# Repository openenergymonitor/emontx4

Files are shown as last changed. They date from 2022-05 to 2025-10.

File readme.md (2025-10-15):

# EmonTx v4

The emonTx v4 is an energy monitoring transmitter unit that can monitor up to 6 AC circuits using CT sensors and the OpenEnergyMonitor 1-3 phase voltage sensing unit. At it's core is a Microchip AVR128DB48 microcontroller - responsible for sampling the current and voltage waveforms and calculating the power and energy values. The emonTx v4 also supports temperature sensing and pulse counting.

Data from the emonTx can be transmitted over the 433 MHz RFM69cw radio link or read directly using a USB cable from an emonBase or emonPi. A number of adapter boards are also available to provide internal connectivity options via ESP32, ESP8266, Pi Pico W and Pi Zero W.

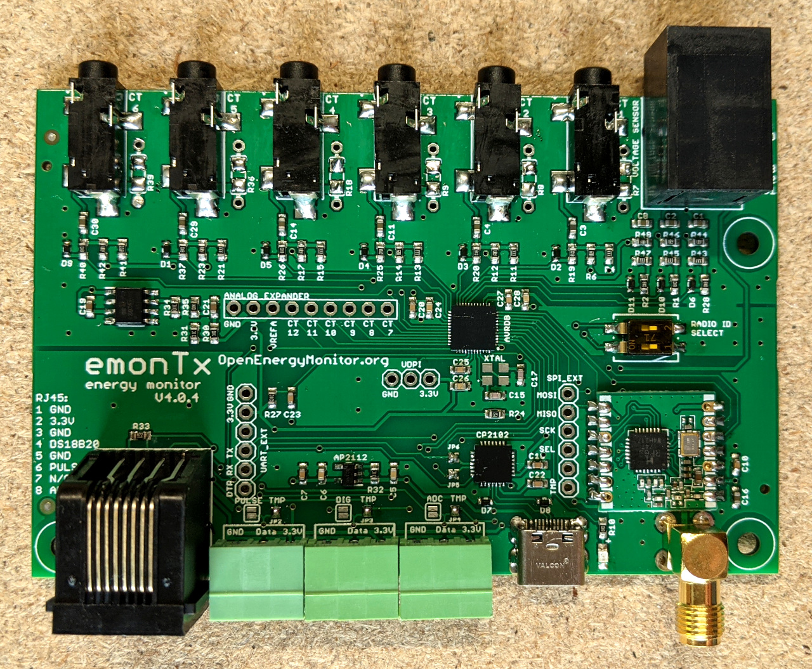
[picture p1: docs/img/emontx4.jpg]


**Key features**

* Micro-controller: AVR128DB48 (VQFN 128 kb flash, 48-pin package)
* 3 voltage channels (via RJ11 connector top-right, interfaces with separate voltage sensing board, single phase firmware only at present).
* 6 CT current channels on the base board.
* Option to extend the number of CT channels to 12 via an additional extender board (firmware not yet developed for this).
* Precision voltage reference for the ADC to improve accuracy.
* RJ45 socket for pulse counter and DS18B20 temperature sensing.
* 3x 3-WAY pluggable terminal blocks for selectable temperature sensing, pulse or additional analog input.
* RFM69CW 433MHz radio transceiver
* DIP Switch to select node id
* USB-C power and integrated CP2102 usb to serial chip
* Serial and SPI pin headers breakout internally, designed for use with adapter boards.
 
The dimensions are slightly smaller than that of the emonTx v3 at 65mm long rather than 80mm.

The board is designed to support both single and full 3-phase electricity monitoring when used in conjunction with the relevant external voltage sensing board. And the CT extender pin headers should provide a cost effective way of gaining additional CT channels.

The on-board USB to serial chip will make it easier and neater to have a hard-wired installation linking the emonTx to a RaspberryPi based base station.

## Documentation

[View on read the docs](https://docs.openenergymonitor.org/emontx4/index.html)

Or here on github:

- [Install Guide](docs/emontx4_emonbase_install.md)
- [Configuration](docs/configuration.md)
- [Firmware](docs/firmware.md)
- [Expansion boards](docs/expansion_boards.md)

## Expansion Boards

- [6CT Expansion Board](https://github.com/openenergymonitor/emontx4/tree/main/expansion_boards/CTExt)
- [ESP8266 Expansion Board](https://github.com/openenergymonitor/emontx4/tree/main/expansion_boards/ESP8266)
- [ESP32 Expansion Board](https://github.com/openenergymonitor/emontx4/tree/main/expansion_boards/ESP32)
- [Pi Pico Expansion Board](https://github.com/openenergymonitor/emontx4/tree/main/expansion_boards/PiPico)
- [Pi Zero ExtExpansionension Board](https://github.com/openenergymonitor/emontx4/tree/main/expansion_boards/PiZero)

## Community & Support

- [OpenEnergyMonitor Forums](https://community.openenergymonitor.org)

OpenEnergyMonitor Shop Support: support@openenergymonitor.zendesk.com

## License

- The hardware designs (schematics and CAD files) are licensed under a Creative Commons Attribution-ShareAlike 3.0 Unported License.
- The firmware is released under the GNU GPL V3 license The documentation is subject to GNU Free Documentation License
- The hardware designs follow the terms of the OSHW (Open-source hardware) Statement of Principles 1.0.

## Disclaimer

```
OUR PRODUCTS AND ASSEMBLY KITS MAY BE USED BY EXPERIENCED, SKILLED USERS, AT THEIR OWN RISK. TO THE FULLEST EXTENT PERMISSIBLE BY THE APPLICABLE LAW, WE HEREBY DISCLAIM ANY AND ALL RESPONSIBILITY, RISK, LIABILITY AND DAMAGES ARISING OUT OF DEATH OR PERSONAL INJURY RESULTING FROM ASSEMBLY OR OPERATION OF OUR PRODUCTS.

Your safety is your own responsibility, including proper use of equipment and safety gear, and determining whether you have adequate skill and experience. OpenEnergyMonitor and Megni registered partnership disclaims all responsibility for any resulting damage, injury, or expense. It is your responsibility to make sure that your activities comply with applicable laws, including copyright. Always check the webpage associated with each unit before you get started. There may be important updates or corrections. All use of the instructions, kits, projects and suggestions given both by megni.co.uk, openenergymonitor.org and shop.openenergymonitor.org are to be used at your own risk. The technology (hardware , firmware and software) are constantly changing, documentation (including build guide and instructions) may not be complete or correct.

If you feel uncomfortable with assembling or using any part of the system, return it to us for a full refund.
```

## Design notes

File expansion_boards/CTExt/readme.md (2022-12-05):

# EmonTx v4 CT Expansion Board

The expansion board adds another 6 CT inputs, bringing the total to 12. This utilises the larger amount of analog inputs on the 48pin AVR-DB chip.

While the first version of the hardware for this is available, the firmware for this functionality is not yet available.

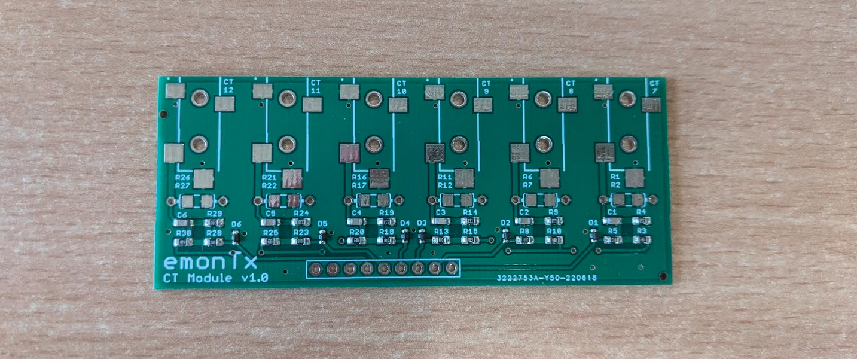
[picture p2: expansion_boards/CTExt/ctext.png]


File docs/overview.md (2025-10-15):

---
github_url: "https://github.com/openenergymonitor/emontx4/blob/main/docs/overview.md"
---

# Overview

The emonTx4 is part of the AVR-DB based hardware family which now includes the emonPi2 and the emonTx5.

While no longer available in the shop the emonTx4 is still actively supported as part of the latest generation of hardware.

These units provide a redesigned focus on higher accuracy, more CT channels and precision voltage sensing. When combined with the emonVs voltage sensor, the emonBase base-station and a selection of CT sensors, the emonTx4 provides an end-to-end electricity monitoring solution perfect for monitoring home consumption, solar generation, EV charging, heat pumps, battery storage or any AC electrical circuit for that matter.

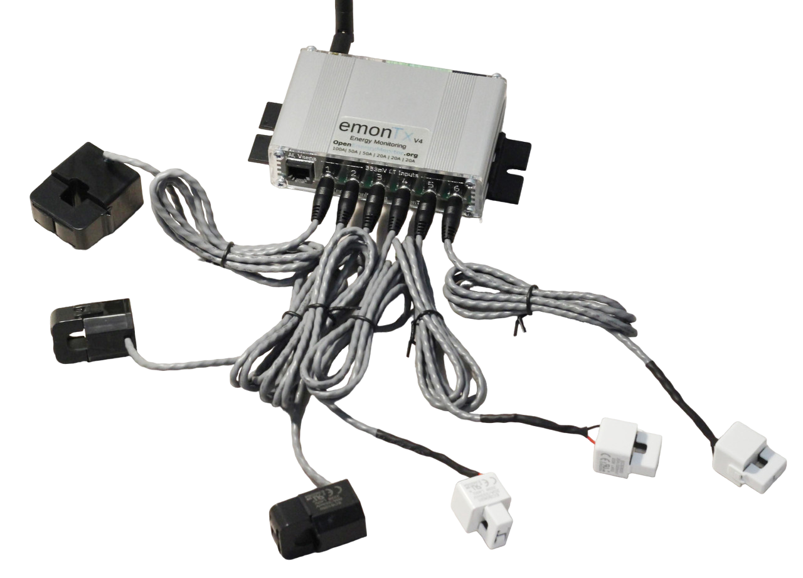
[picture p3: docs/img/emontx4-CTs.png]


## Key features

- 6x clip-on CT current sensor inputs (suitable for a range of 333mV voltage output CT sensors).
- emonVs precision voltage sensor input.
- Full Real/Active power measurement & continuous sampling.
- Cumulative energy persisted on reboot.
- The initial firmware release supports single phase monitoring only.
- Support for 3 phase voltage sensing.
- 3 pluggable terminal block inputs for DS18B20 temperature sensing, pulse counting or an analogue voltage input.
- RJ45 socket for pulse counting and DS18B20 temperature sensors.
- On-board USB to UART converter for easier programming and serial output.
- 433 MHz radio transceiver
- Extension header pins for use with ESP8266, ESP32, Pi Pico & Pi Zero development board extension modules
- Wall-mount aluminium enclosure

## Technical spec

- Microcontroller: [Microchip AVR128DB48](https://www.microchip.com/en-us/products/microcontrollers-and-microprocessors/8-bit-mcus/avr-mcus/avr-db)
- Arduino core support [DxCore by SpenceKonde](https://github.com/SpenceKonde/DxCore)
- ADC Resolution: 12-bit
- Precision voltage reference: [MCP1502](https://www.microchip.com/en-us/product/MCP1502)
- On board USB to UART converter: CP2102
- RFM69CW 433 MHz radio

## Accuracy

We have taken several key steps to improve accuracy with the emonTx4. The largest source of improvement comes from: a higher accuracy voltage sensor, higher accuracy CT current sensors and a wider range of CT sensors with current ratings that can better suit the load being monitored (making sure the analog-to-digital range of the microcontroller is being put to full use).

The key sensor and component tolerances are now:

- CT Sensors: ±0.5%
- EmonVs voltage sensor: ±0.5%
- Analog voltage reference ±0.2%
- Combined: ±1.2%

We have also upgraded the microcontroller from the ATmega328 to and AVR128DB48. The main improvement is a higher resolution ADC at 12-bits (4x the resolution of the ATmega328) alongside the capability to monitor more channels.

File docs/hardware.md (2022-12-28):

---
github_url: "https://github.com/openenergymonitor/emontx4/blob/main/docs/hardware.md"
---

# Hardware

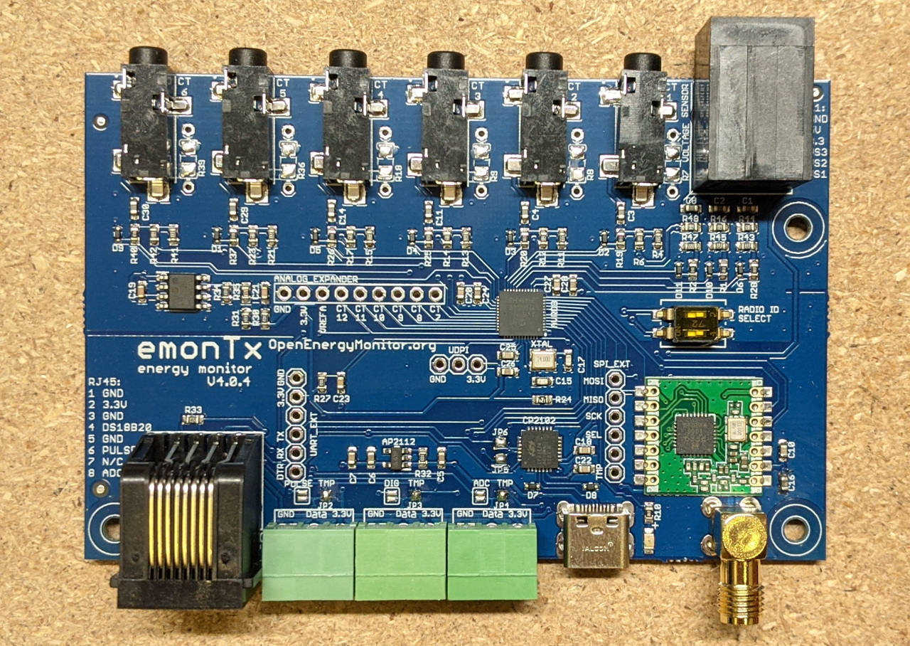
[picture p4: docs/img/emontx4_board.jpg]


## Schematic

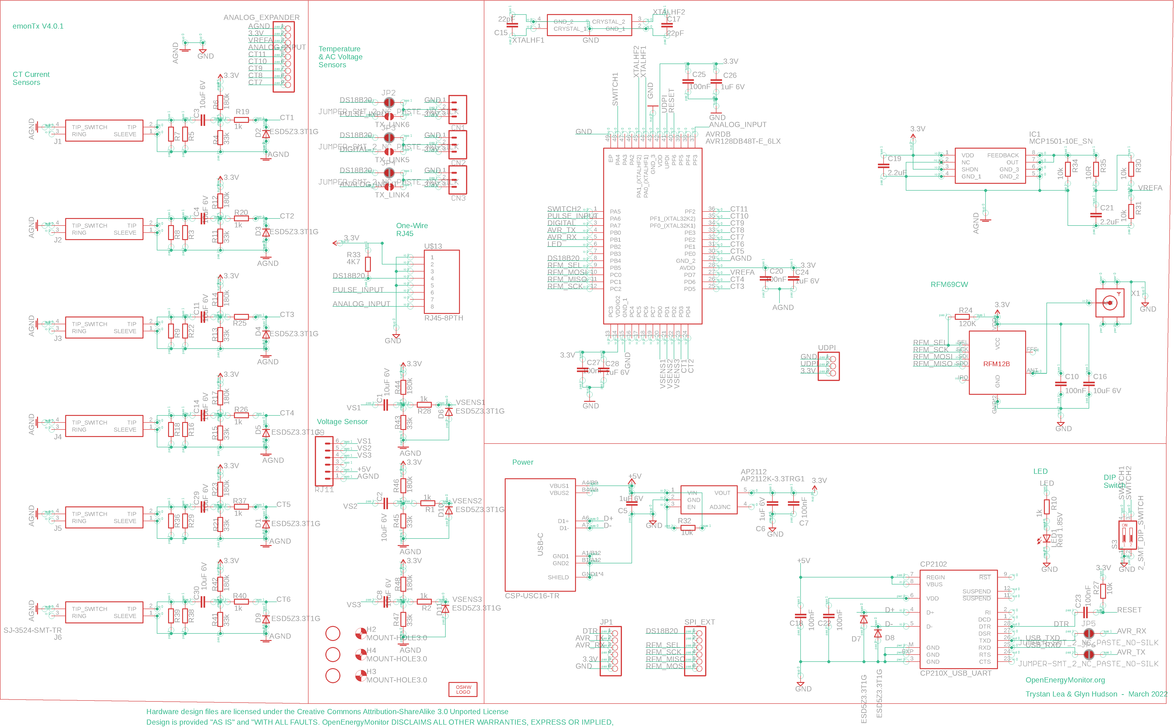
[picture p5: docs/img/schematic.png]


## Board layout

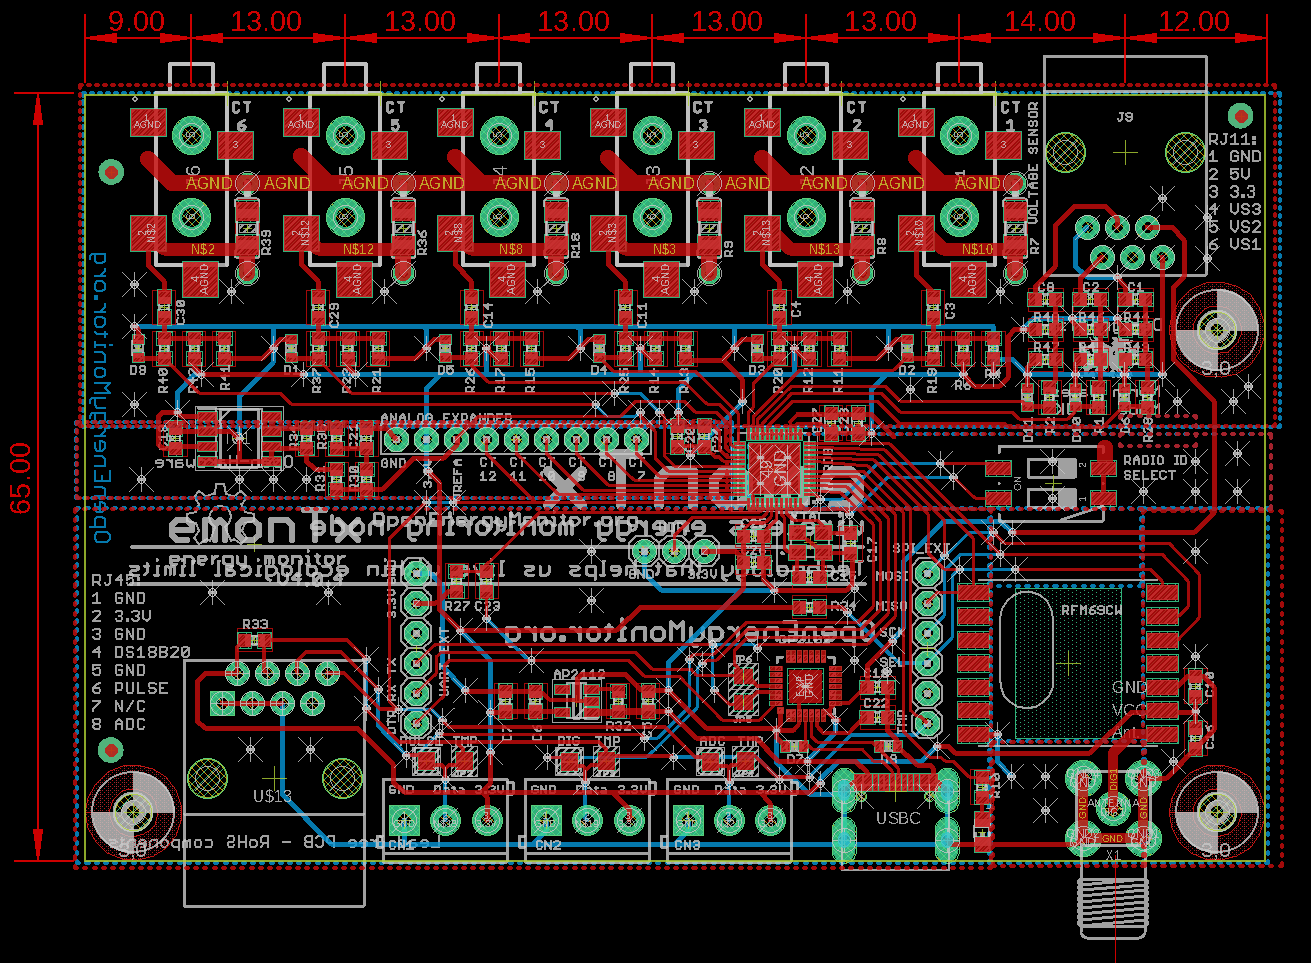
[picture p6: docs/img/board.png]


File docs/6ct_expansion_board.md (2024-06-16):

# 6 CT Expansion board

The 6 CT Expansion board adds a further 6x CT inputs to the EmonTx4, giving a total of 12 CT inputs. This can be used with example firmware that is provided as part of the new EmonLibDB library, supporting both single phase and 3 phase monitoring. 

**Note: Firmware configuration, compilation and upload required using the Arduino IDE, see firmware guide below for details.**

## Installation guide

**Upgrading:** If ordered separately to the EmonTx4 the expansion board comes with a 12 CT fascia to replace the standard 6 CT version. A 9-way header is also included that needs to be soldered in place on the EmonTx4.

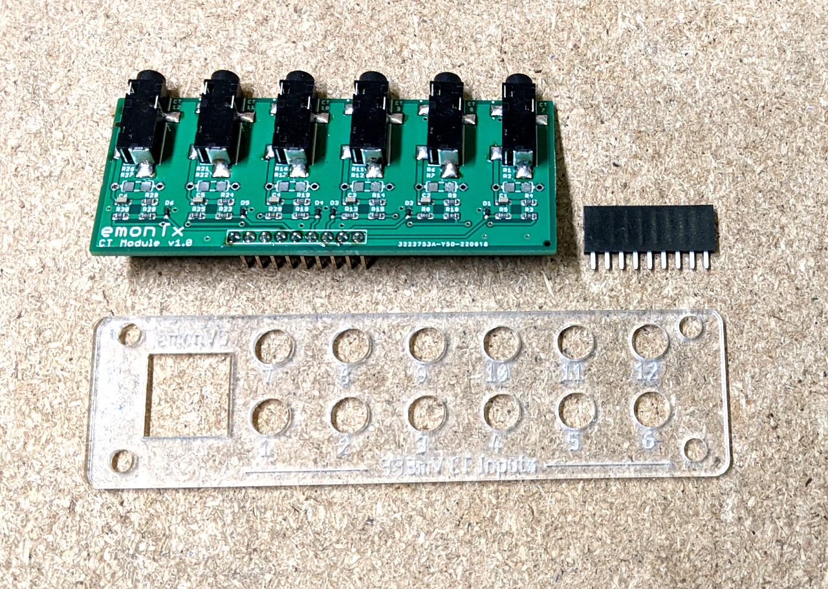
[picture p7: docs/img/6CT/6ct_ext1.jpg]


Place the 9 way header on the top side of the board as circled below:

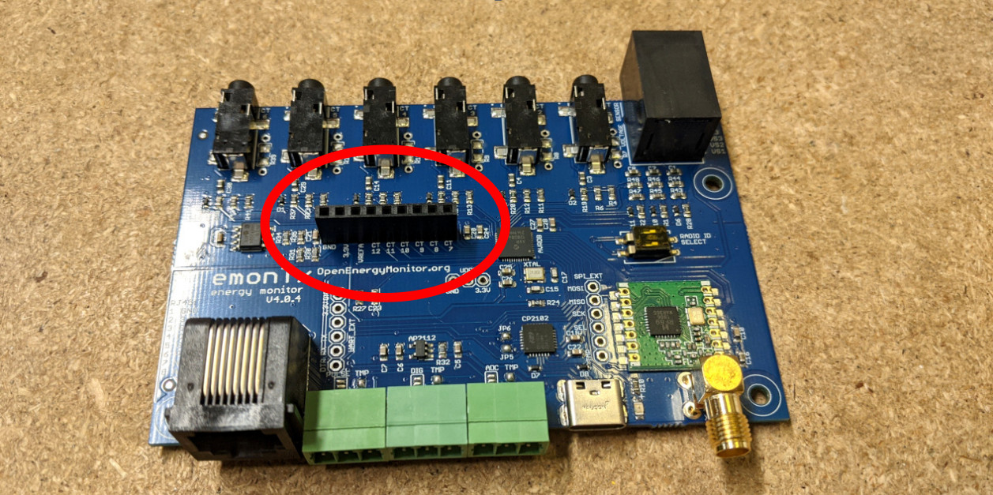
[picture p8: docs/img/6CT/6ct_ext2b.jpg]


Solder the pins on the bottom side, taking care not to bridge across the pins:

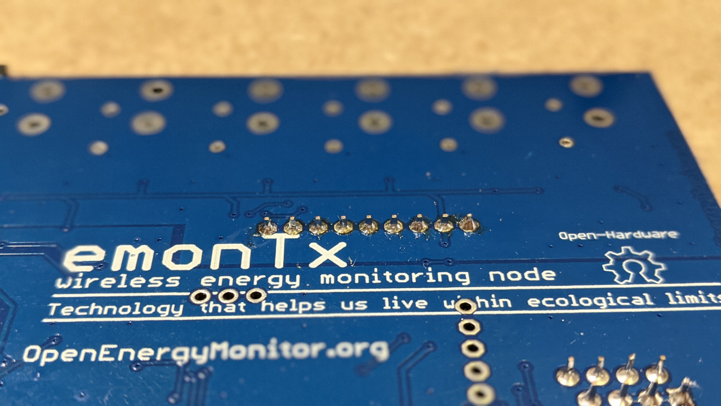
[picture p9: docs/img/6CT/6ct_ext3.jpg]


**Note:** The mechanical attachment of the expansion board is not very secure. It relies on the 9 way PCB header connection. Care needs to be taken when plugging in expansion board CTs as the board can flex on the header. This is something we plan to improve on future versions.

We recommend connecting the CT sensors through the face plate, outside of the aluminium enclosure first and then attaching the face plate to the enclosure second. This ensures that the CT's are all fully inserted and that the pressure on the header is minimised. See pictures below.

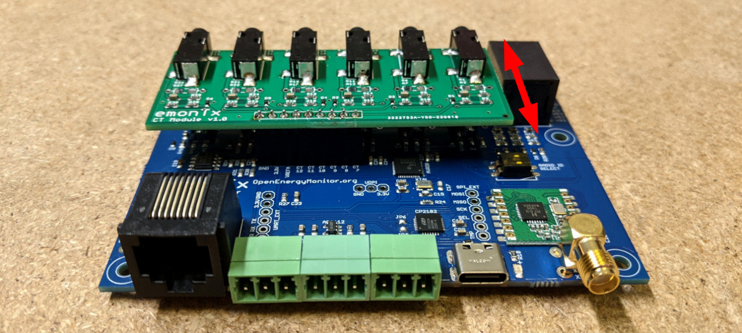
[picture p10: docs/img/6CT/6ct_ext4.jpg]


Slide the emonTx4 board, expansion board, face plate and CT jacks into the case:

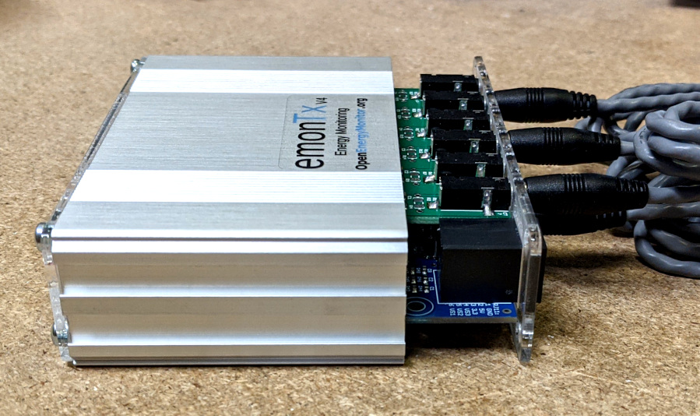
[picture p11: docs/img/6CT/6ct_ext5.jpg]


Screw in the torx screws (torx size T10):

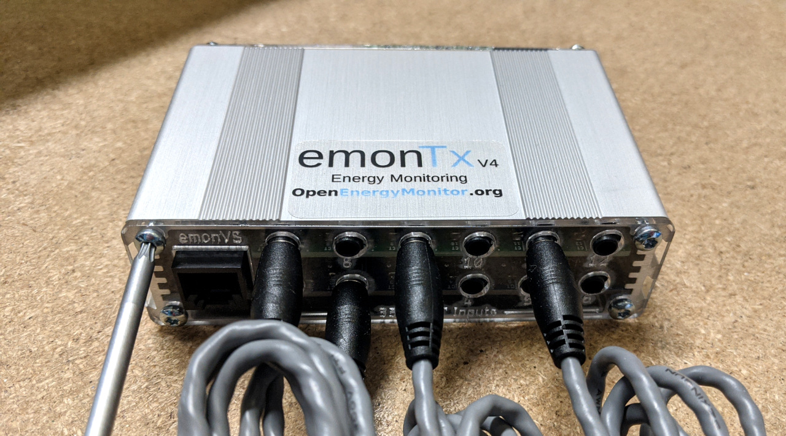
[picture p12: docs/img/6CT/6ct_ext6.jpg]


## Firmware guide

If you are using the newer "LowPowerLabs" radio firmware, you will be able to flash precompiled firmware. See the [firmware guide](firmware.md) to determine which firmware you require for your needs.

If you are using the older "JeeLib Classic" radio firmware (pre 2022 monitoring installations), using the 6 CT channel expansion board may require compiling and uploading custom configuration of the emonTx4 firmware. Start by setting up the Arduino IDE environment following the [firmware guide](firmware.md).

Open the base firmware `emon_DB_12CT` from the [avrdb_firmware](https://github.com/openenergymonitor/avrdb_firmware) firmware repository.

1\. Make sure to **select emonTx4 as the hardware variant**:

```
// 1. Set hardware variant
// Options: EMONTX4, EMONTX5, EMONPI2
#define EMONTX4
```

2\. **Set `NUM_V_CHANNELS`** to 1 for single phase or 3 for three phase: 

```
// 3. Set number of voltage channels (1 for single phase, 3 for three phase)
#define NUM_V_CHANNELS 3
```

3\. **Adjust voltage and CT sensor calibration as required** (lines 187-207):

**Voltage inputs:**
101.3 here refers to 101.3% of the default calibration value. Please see [emonLibDB user guide](https://github.com/openenergymonitor/emonLibDB/blob/main/guide.md) for more info as well. 0.16 refers to the voltage sensor phase calibration.

```
  EmonLibDB_set_vInput(1, 101.3, 0.16);  
#if NUM_V_CHANNELS == 3
  EmonLibDB_set_vInput(2, 101.3, 0.16); 
  EmonLibDB_set_vInput(3, 101.3, 0.16); 
#endif
```

**Current channel inputs:** 100.0 here refers to 100A CT sensors. If you have 20A or 50A CT sensors change the relevant channels to 20.0 or 50.0 to match the CT sensor. 3.2 refers to the CT sensor phase calibration.

```
  EmonLibDB_set_cInput(1, 20.0, 3.2);
  EmonLibDB_set_cInput(2, 20.0, 3.2);
  EmonLibDB_set_cInput(3, 20.0, 3.2);
  EmonLibDB_set_cInput(4, 20.0, 3.2);
  EmonLibDB_set_cInput(5, 20.0, 3.2);
  EmonLibDB_set_cInput(6, 20.0, 3.2);
  
#ifdef EXPANSION_BOARD
  EmonLibDB_set_cInput(7, 20.0, 3.2);
  EmonLibDB_set_cInput(8, 20.0, 3.2);
  EmonLibDB_set_cInput(9, 20.0, 3.2);
  EmonLibDB_set_cInput(10, 20.0, 3.2);
  EmonLibDB_set_cInput(11, 20.0, 3.2);
  EmonLibDB_set_cInput(12, 20.0, 3.2);
#endif  
```

4\. **Link voltage and current sensors to define the power & energy measurements.** The firmware includes default configuration for the selected NUM_V_CHANNELS (1 phase or 3 phase). In the single phase example all CT sensors are connected to voltage phase 1. In the three phase code, the allocation is CT1 = phase1, CT2 = phase2, CT3 = phase3 etc.

```
#if NUM_V_CHANNELS == 1
  EmonLibDB_set_pInput(1, 1);                  // CT1, V1 (etc)
  EmonLibDB_set_pInput(2, 1);
  EmonLibDB_set_pInput(3, 1);
  EmonLibDB_set_pInput(4, 1);  
  EmonLibDB_set_pInput(5, 1);
  EmonLibDB_set_pInput(6, 1);
#ifdef EXPANSION_BOARD
  EmonLibDB_set_pInput(7, 1);                  // CT7, V1 (etc)
  EmonLibDB_set_pInput(8, 1);
  EmonLibDB_set_pInput(9, 1);
  EmonLibDB_set_pInput(10, 1);  
  EmonLibDB_set_pInput(11, 1);
  EmonLibDB_set_pInput(12, 1);
#endif
#endif

#if NUM_V_CHANNELS == 3
  EmonLibDB_set_pInput(1, 1);                  // CT1, V1 (etc)
  EmonLibDB_set_pInput(2, 2);
  EmonLibDB_set_pInput(3, 3);
  EmonLibDB_set_pInput(4, 1);  
  EmonLibDB_set_pInput(5, 2);
  EmonLibDB_set_pInput(6, 3);
#ifdef EXPANSION_BOARD
  EmonLibDB_set_pInput(7, 1);                  // CT7, V1 (etc)  
  EmonLibDB_set_pInput(8, 2);
  EmonLibDB_set_pInput(9, 3);
  EmonLibDB_set_pInput(10, 1);  
  EmonLibDB_set_pInput(11, 2);
  EmonLibDB_set_pInput(12, 3);
#endif
#endif
```

*Note: It is also possible to measure Line-Line loads, see Line-Line loads: example lines 253-267.*

5\. **Compile and upload your configured firmware to the EmonTx4.** Note compilation and upload settings as covered in the  [EmonTx4 How to compile and upload firmware guide](firmware.md). 

6\. **To receive the radio packet data on an emonPi or emonBase** first make sure that you are running LowPowerLabs radio firmware on the emonPi or emonBase receiver. 

If you have existing nodes running the original JeeLib classic radio format, the firmware on these will also need to be updated if everything is to continue talking to each other. 

If you have an emonPi make sure that it's running the latest emonPi LowPowerLabs firmware, this can be uploaded from the local emoncms Admin > Update page.

If you bought an emonBase alongside an emonTx4 and selected the standard radio format option the radio configuration should already be correct and ready to receive data from the EmonTx4 running the above firmware example.

7\. **Configure emonHub to decode the `emon_DB_12CT` radio packet**.<br>
If you have the latest version of emonhub with autoconf enabled, it will automatically populate the node decoder configuration below. If you have an older system with autoconf disabled, follow the following manual steps:

On your local emonPi/emonBase navigate to `Setup > Emonhub > Edit Config.`

If you already have a node configuration in the `[nodes]` section for the EmonTx4 under the same nodeid as above, remove this first. 

Add the following node decoder in its place (Adjust the nodeid to match the configured nodeid as set in the firmware above):

    [[28]]
        nodename = emonTx4_28
        [[[rx]]]
            names = MSG, Vrms1, Vrms2, Vrms3, P1, P2, P3, P4, P5, P6, E1, E2, E3, E4, E5, E6, pulse, Analog
            datacodes = L, h, h, h, h, h, h, h, h, h, l, l, l, l, l, l, L, H
            scales = 1.0, 0.01, 0.01, 0.01, 1.0, 1.0, 1.0, 1.0, 1.0, 1.0, 1.0, 1.0, 1.0, 1.0, 1.0, 1.0, 1.0, 1.0
            units = n, V, V, V, W, W, W, W, W, W, Wh, Wh, Wh, Wh, Wh, Wh, p, n

    [[29]]
        nodename = emonTx4_29
        [[[rx]]]
            names = MSG, Vrms2, Vrms3, P7, P8, P9, P10, P11, P12, E7, E8, E9, E10, E11, E12, digPulse, anaPulse
            datacodes = L, h, h, h, h, h, h, h, h, l, l, l, l, l, l, L, L
            scales = 1.0, 0.01, 0.01, 1.0, 1.0, 1.0, 1.0, 1.0, 1.0, 1.0, 1.0, 1.0, 1.0, 1.0, 1.0, 1.0, 1.0
            units = n, V, V, W, W, W, W, W, W, Wh, Wh, Wh, Wh, Wh, Wh, p, p

8\. **That should be it!** you should now see the EmonTx4 data appear both in the EmonHub log window and as inputs on the Emoncms inputs page :tada:

For more information, please see forum thread: [EmonTx4 3-phase support with emonLibDB](https://community.openenergymonitor.org/t/emontx4-3-phase-support-with-emonlibdb/23541)

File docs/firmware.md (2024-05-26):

---
github_url: "https://github.com/openenergymonitor/emontx4/blob/main/docs/firmware.md"
---

# Firmware

**Updated: 14th May 2024**<br>

There are currently 8 pre-compiled firmware options for the emonTx4 available via both the Emoncms firmware upload tool and the command line `emonupload.py` firmware tool. 

**To choose the right firmware, there are 4 main questions:**

1. Is the application 1-phase, 3-phase (4-wire) or current only?<br>

2. Are you using a 6 channel expander for a total of 12 CT channels?<br>

3. Do you require temperature sensing?<br>

4. Do you require compatibility firmware that uses the JeeLib Classic radio format for use with an existing pre 2022 monitoring installation?

Select the right firmware from the list that matches the requirements of your application:

| ID | Firmware | Voltage | CTs | Temperature | Pulse|
| --- | --- | --- | --- | --- | --- |
| | **Radio: LowPowerLabs** | | | | |
| 1 | emonTx4_DB_6CT_1phase_LPL | 1-ph | 6 | 0 | 1* |
| 2 | emonTx4_DB_6CT_3phase_LPL | 3-ph | 6 | 0 | 1* |
| 3 | emonTx4_DB_12CT_1phase_LPL | 1-ph | 12 | 0 | 3* |
| 4 | emonTx4_DB_12CT_3phase_LPL | 3-ph | 12 | 0 | 3* |
| 5 | emonTx4_CM_6CT_temperature_LPL | 1-ph or current only | 6 | 3 (6\*\*) | 1 |
| | **Radio: Compatibility mode (JeeLib Classic)** | | | | |
| 6 | emonTx4_DB_6CT_1phase_JeeLib_Classic | 1-ph  | 6 | 0 | 1* |
| 7 | emonTx4_DB_6CT_3phase_JeeLib_Classic | 3-ph  | 6 | 0 | 1* |
| 8 | emonTx4_CM_6CT_temperature_JeeLib_Classic | 1-ph or current only | 6 | 3 (6\*\*) | 1 |

*The pulse sensor * denote standard firmware radio packet support for the number of pulse sensors given. Firmware modification can extend the number of pulse sensors to 3 on all emonLibDB based firmwares.*

- All firmwares transmit data via 433Mhz RFM69CW radio by default and are designed to be used with a receiving emonPi/emonBase base-station. The radio can be turned off via serial configuration if reading data via USB cable.

- All firmwares include serial configuration of radio, voltage and current channel calibration values.

- **_DB:** EmonLib**DB** electricity monitoring library.<br>

- **_CM:**  EmonLib**CM** electricity monitoring library.

- **3-phase firmwares phase allocation:** follows the following pattern: 

  - CT1: phase 1
  - CT2: phase 2
  - CT3: phase 3
  - CT4: phase 1
  - CT5: phase 2
  - CT6: phase 3
  - continued for 12 CT expansion board...

- **3-phase (4-wire):** 3-phase support is for 3-phase, 4-wire systems only. That is systems with an L1, L2, L3 and a NEUTRAL wire. For 3-phase, 3-wire systems please contact us.

- **North American split-phase systems:** The 3-phase voltage sensor can also be used to provide voltage measurement for North American split-phase systems. A custom phase allocation will likely be required for this configuration which can be achieved by minor firmware modification.

- **Current only:** Supported by firmware 5 & 8 only, can be used with installations without an emonVs voltage sensor. These firmwares uses the older emonLibCM electricity monitoring library that has a fallback option to an assumed RMS voltage value if no AC voltage signal is detected.

- **Temperature sensing:** 
  - Supported by firmware 5 & 8 only. Temperature sensing support is achieved with a very slight degradation in electricity monitoring performance, see forum thread about this [here](https://community.openenergymonitor.org/t/emontx4-ds18b20-temperature-sensing-firmware-release-1-5-7/23496/3).

  - \*\*The default maximum number of temperature sensors that can be connected is 3 but this can be increased up to 6 by changing the `#define MAX_TEMPS 3` value at the top of the firmware when compiling and uploading from source.

- **Pulse sensing** is configured on the standard emonTx4 digital input port available on the RJ45 socket as well as the terminal block input (if the solder pad is configured). 

- **Analog input:** Reading from the analog input can be enabled for all firmware variants via a `#define` compile option when compiling from source.

**Base firmwares**<br>
These are now built from a set of base firmware's common to all AVR-DB hardware variants (emonTx4, emonTx5 and emonPi2) available in the [avrdb_firmware repository](https://github.com/openenergymonitor/avrdb_firmware/)

- Firmwares 1, 2, 6 & 7 compiled from the `emon_DB_6CT` base firmware.
- Firmwares 3 & 4 are compiled from the `emon_DB_12CT` base firmware.
- Firmwares 5 & 8 are compiled from the `emon_CM_6CT_temperature` base firmware.

---

## Updating firmware using an emonPi/emonBase (recommended)

The easiest way of updating the emonTx4 firmware is to connect it to an emonBase with a USB cable and then use the firmware upload tool available at `Setup > Admin > Update > Firmware`.

```{warning} 

**System update may be required:** If you don not see the latest firmware version as listed above in the firmware list a full system update is required first.
```

**Note: Upload via USB-C will only work if connected in the right orientation. Try turning the USB-C connector around if upload fails.** Some USB-C connectors have a smooth side on one side and jagged connection of the metal fold on the other. On the cables we have here, the smooth side should be facing up towards the top/front face of the emonTx4:

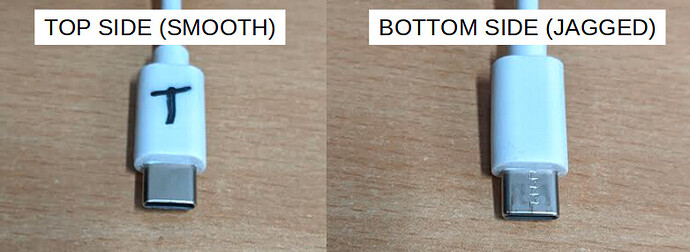
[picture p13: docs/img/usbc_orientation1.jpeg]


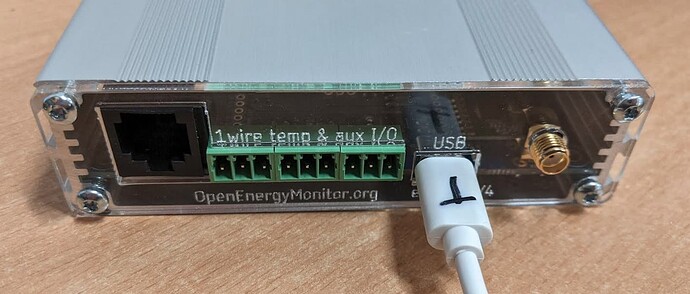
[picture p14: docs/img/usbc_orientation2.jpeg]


Refresh the update page after connecting the USB cable. You should now see port `ttyUSB0` appear in the 'Select port` list.



Double check the serial port, this is likely to be 'ttyUSB0' when plugged in via USB device connected. Select 'emonTx4' from hardware.

The standard radio format is 'LowPowerLabs', if you wish to use the emonTx4 with an existing system running JeeLib classic radio format you can select the JeeLib classic radio format here.

## Upload pre-compiled using EmonScripts emonupload2 tool 

On the emonPi/emonBase ensure EmonScripts is updated to latest version then run emonupload2 tool 

    /opt/openenergymonitor/EmonScripts/emonupload2.py

Select hardware then firmware version

```
Select hardware:
  1. emonTx5
  2. emonPi2
  3. emonTx4
  4. emonPi
  5. emonTx3
  6. rfm69pi
  7. rfm12pi
  8. emonTH2
  9. JeeLink
Enter number:3

Select firmware:
1. emonTx4_DB_6CT_1phase_LPL               2.1.0      (Standard LowPowerLabs)
2. emonTx4_DB_6CT_3phase_LPL               2.1.0      (Standard LowPowerLabs)
3. emonTx4_DB_12CT_1phase_LPL              1.2.0      (Standard LowPowerLabs)
4. emonTx4_DB_12CT_3phase_LPL              1.2.0      (Standard LowPowerLabs)
5. emonTx4_CM_6CT_temperature_LPL          1.6.0      (Standard LowPowerLabs)
6. emonTx4_DB_6CT_1phase_JeeLib_Classic    2.1.0      (Compatibility)
7. emonTx4_DB_6CT_3phase_JeeLib_Classic    2.1.0      (Compatibility)
8. emonTx4_CM_6CT_temperature_JeeLib_Classic1.6.0      (Compatibility)

```

emonupload2 tool can also be run on any other linux computer by cloning the EmonScripts repo then running the emonupload2.py python script. Python3 required 

    git clone https://github.com/openenergymonitor/EmonScripts

## Upload pre-compiled manually using avrdude

Alternatively to upload the same pre-compiled firmware via command line on emonPi / emonBase: 

    avrdude -C/opt/openenergymonitor/EmonScripts/update/avrdude.conf -v -pavr128db48 -carduino -D -P/dev/ttyUSB0 -b115200 -Uflash:w:emonTx4_DB_6CT_1phase_LPL_v2_1_0.ino.hex:i 

Or using different computer, ensure `avrdude.conf` has `avr128db48` entry i.e DxCore see below instructions 

    avrdude -Cavrdude.conf -v -pavr128db48 -carduino -D -P/dev/ttyUSB0 -b115200 -Uflash:w:emonTx4_DB_6CT_1phase_LPL_v2_1_0.ino.hex:i 
    
You will need avrdude installed (tested on version 6.3-2017) and the custom DxCore avrdude.conf. This can be downloaded here: [DxCore avrdude.conf](https://raw.githubusercontent.com/openenergymonitor/EmonScripts/master/update/avrdude.conf).

## How to compile and upload firmware

### Compile and Upload using PlatformIO

Clone the `avrdb_firmware` repo 

    git clone https://github.com/openenergymonitor/avrdb_firmware
    cd avrdb_firmware/emon_DB_6CT
    
Open `emon_DB_6CT.ino` in an editor and change `#define EMONTX5` to `#define EMONTX4`. 

Change any other compile options as required e.g:

- to use JeeLib classic radio format for compatibility with an existing installation change `#define RFM69_LOW_POWER_LABS` to `#define RFM69_JEELIB_CLASSIC`.
- to enable analog read uncomment `#define ENABLE_ANALOG`.
- change pulse pin to standard emonTx4 digital input if required `#define PULSE_PIN 1`.
    
Install PlatformIO core then to compile and upload:

    pio run -t upload

On first run PlatformIO will download automatically all the required libraries. You can also use the PlatformIO GUI. 

### Compile and Upload using Arduino IDE 

If you don’t already have the Arduino IDE it can be downloaded from here:<br>
[https://www.arduino.cc/en/software](https://www.arduino.cc/en/software)

Once you have the IDE installed, you then need to install [Spence Konde’s DxCore](https://github.com/SpenceKonde/DxCore). This can be done by first pasting the following board manager URL in Arduino IDE > File > Preferences:

    http://drazzy.com/package_drazzy.com_index.json

Then navigating to: *Tools > Boards > Boards Manager*, Select “DxCore by Spence Konde” and click Install. 

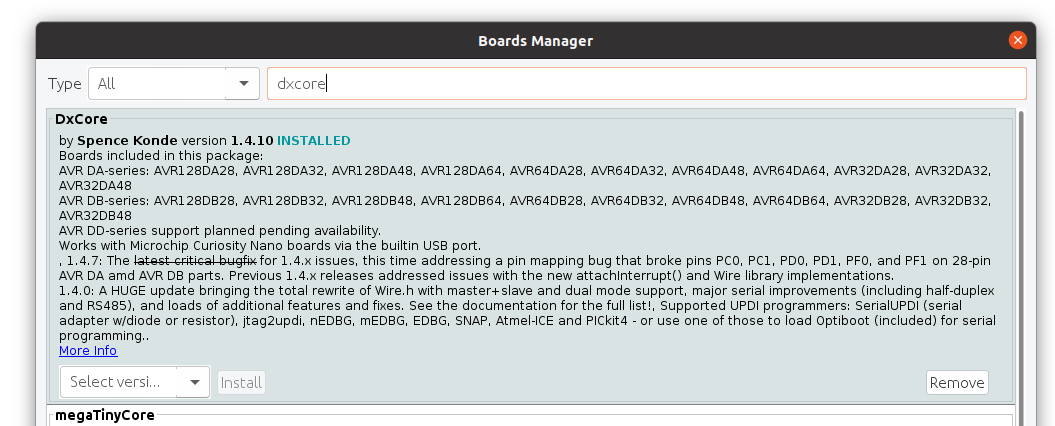
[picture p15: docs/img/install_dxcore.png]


For more information on DxCore installation see: [https://github.com/SpenceKonde/DxCore/blob/master/Installation.md](https://github.com/SpenceKonde/DxCore/blob/master/Installation.md).

**Libraries**

Locate or create your Arduino Sketchbook directory (location found in Arduino preferences). If it doesnt already exist, create a directory called libraries in the Sketchbook directory and install the following libraries:

1\. Download EmonLibCM library (avrdb branch)<br>
[https://github.com/openenergymonitor/EmonLibCM/tree/avrdb](https://github.com/openenergymonitor/EmonLibCM/tree/avrdb)

2\. Download EmonLibDB library (main branch)<br>
[https://github.com/openenergymonitor/emonLibDB](https://github.com/openenergymonitor/emonLibDB)

2\. Download emonEProm library (avrdb branch)<br>
[https://github.com/openenergymonitor/emonEProm/tree/avrdb](https://github.com/openenergymonitor/emonEProm/tree/avrdb)

3\. Download RFM69_LPL library (main branch)<br>
[https://github.com/openenergymonitor/RFM69_LPL](https://github.com/openenergymonitor/RFM69_LPL)

4\. Download RFM69_JeeLib library (avrdb branch)<br>
[https://github.com/openenergymonitor/RFM69_JeeLib/tree/avrdb](https://github.com/openenergymonitor/RFM69_JeeLib/tree/avrdb)

5\. Download DxCore SpenceKonde OneWire library:<br>
[https://github.com/SpenceKonde/OneWire](https://github.com/SpenceKonde/OneWire)

**Open and edit the AVR-DB firmware**

Clone the `avrdb_firmware` repo 

    git clone https://github.com/openenergymonitor/avrdb_firmware

Open the base firmware that you wish to use in the Arduino IDE e.g `emon_DB_6CT.ino`.

Change `#define EMONTX5` to `#define EMONTX4`. 

Change any other compile options as required e.g:

- to use JeeLib classic radio format for compatibility with an existing installation change `#define RFM69_LOW_POWER_LABS` to `#define RFM69_JEELIB_CLASSIC`.
- to enable analog read uncomment `#define ENABLE_ANALOG`.

**Compilation settings:**

With DxCore and the libraries installed the firmware should then compile. 

Under Tools, select the following configuration options:

- Select Board "AVR DB-series (Optiboot)"
- Select Chip: AVR128DB48
- Clock Speed: 24 MHz Crystal
- Bootloader serial port: UART3: TXPB0, RXPB1

Select Board "AVR DB-series (Optiboot)"

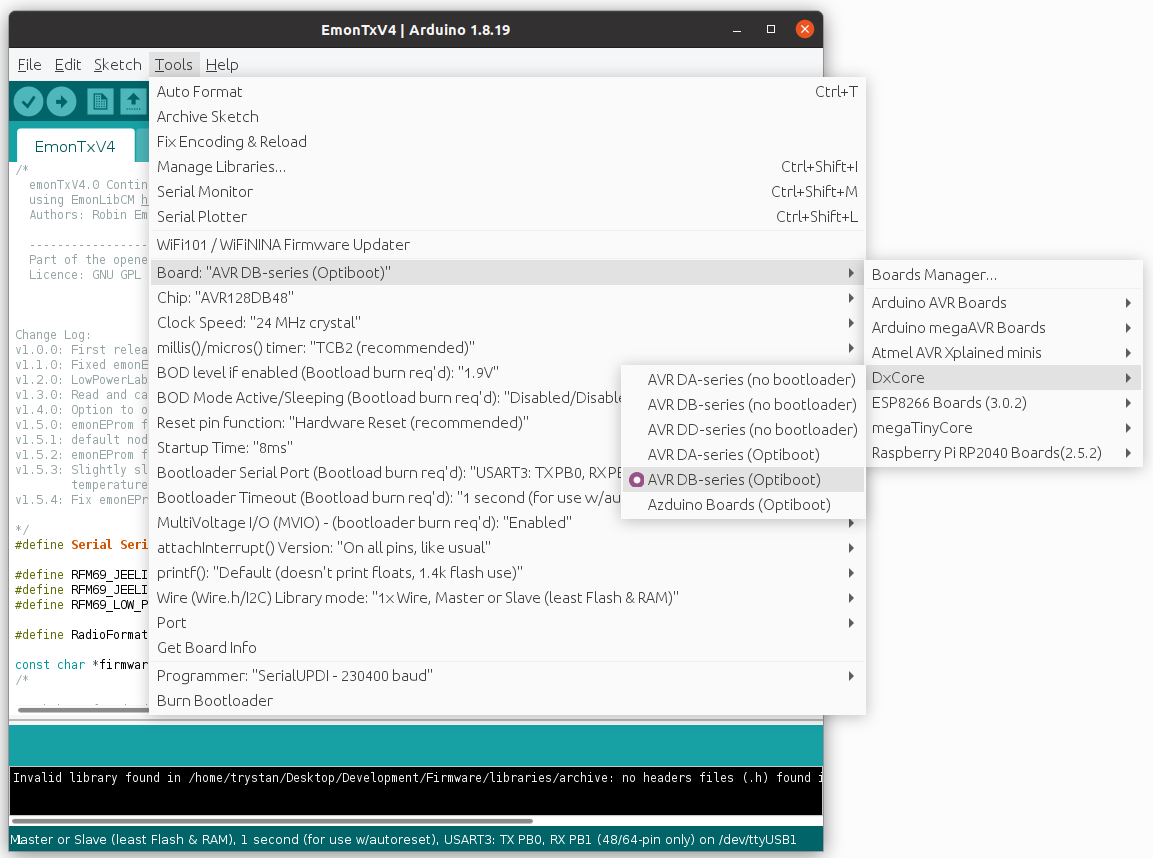
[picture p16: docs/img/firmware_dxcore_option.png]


Select Chip: AVR128DB48

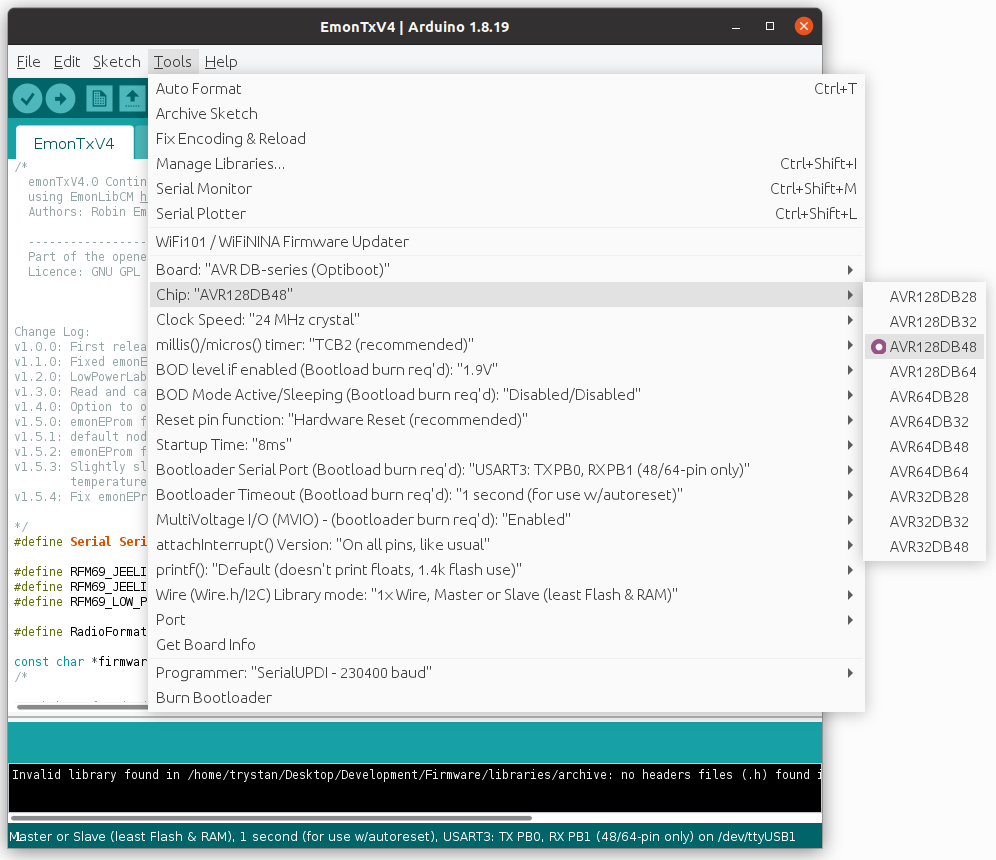
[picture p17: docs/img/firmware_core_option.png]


Bootloader serial port: UART3: TXPB0, RXPB1

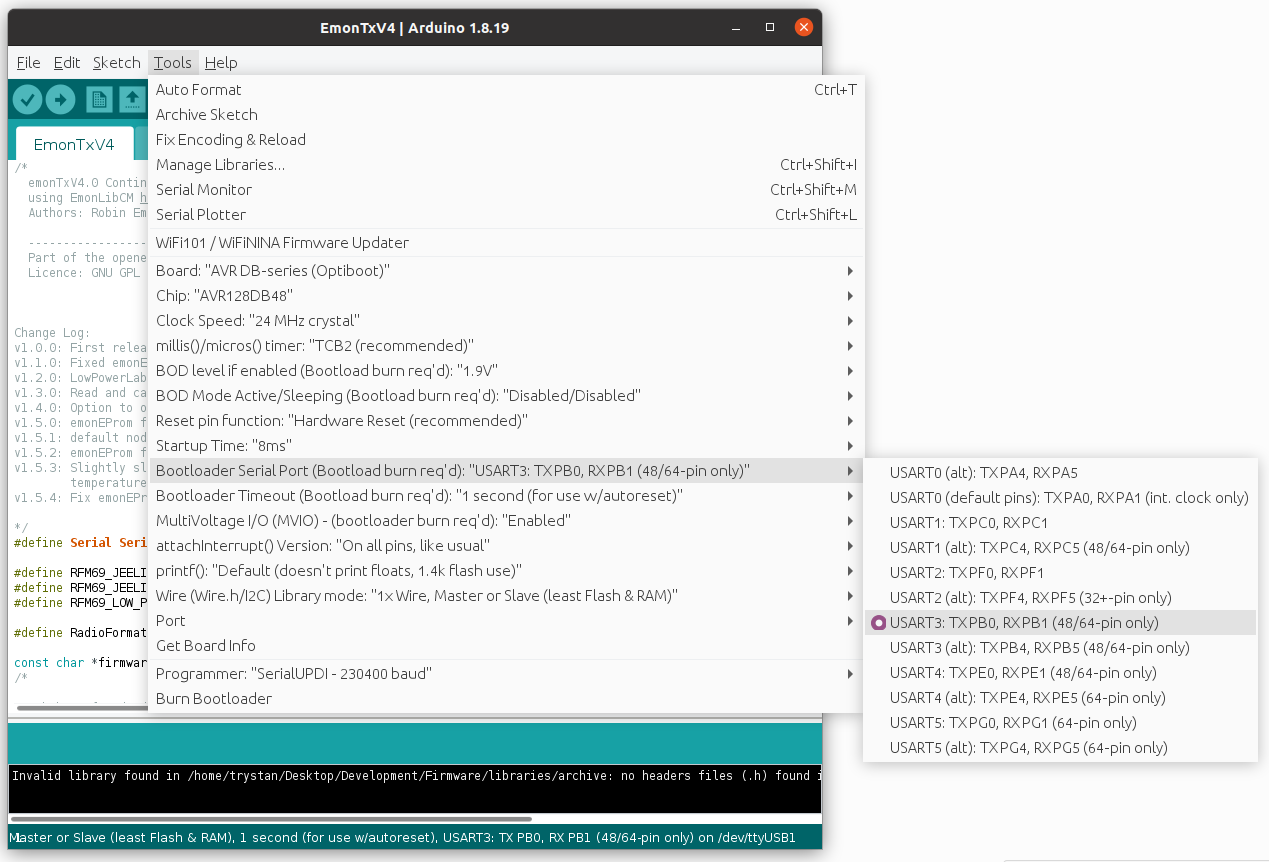
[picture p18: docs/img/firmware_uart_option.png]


### EmonHub node decoders:

**emonTx4_CM_6CT_temperature**

3 temperature sensors:

    [[17]]
        nodename = emonTx4_CM_17
        [[[rx]]]
            names = MSG, Vrms, P1, P2, P3, P4, P5, P6, E1, E2, E3, E4, E5, E6, T1, T2, T3, pulse
            datacodes = L,h, h,h,h,h,h,h, l,l,l,l,l,l, h,h,h,L
            scales = 1,0.01, 1,1,1,1,1,1, 1,1,1,1,1,1, 0.01,0.01,0.01,1
            units = n,V, W,W,W,W,W,W, Wh,Wh,Wh,Wh,Wh,Wh, C,C,C,p
            
4 temperature sensors:

    [[17]]
        nodename = emonTx4_CM_17
        [[[rx]]]
            names = MSG, Vrms, P1, P2, P3, P4, P5, P6, E1, E2, E3, E4, E5, E6, T1, T2, T3, T4, pulse
            datacodes = L,h, h,h,h,h,h,h, l,l,l,l,l,l, h,h,h,h,L
            scales = 1,0.01, 1,1,1,1,1,1, 1,1,1,1,1,1, 0.01,0.01,0.01,0.01,1
            units = n,V, W,W,W,W,W,W, Wh,Wh,Wh,Wh,Wh,Wh, C,C,C,C,p
            
6 temperature sensors:

    [[17]]
        nodename = emonTx4_CM_17
        [[[rx]]]
            names = MSG, Vrms, P1, P2, P3, P4, P5, P6, E1, E2, E3, E4, E5, E6, T1, T2, T3, T4, T5, T6, pulse
            datacodes = L,h, h,h,h,h,h,h, l,l,l,l,l,l, h,h,h,h,h,h, L
            scales = 1,0.01, 1,1,1,1,1,1, 1,1,1,1,1,1, 0.01,0.01,0.01,0.01,0.01,0.01,1
            units = n,V, W,W,W,W,W,W, Wh,Wh,Wh,Wh,Wh,Wh, C,C,C,C,C,C,p

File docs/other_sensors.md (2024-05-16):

---
github_url: "https://github.com/openenergymonitor/emontx4/blob/main/docs/other_sensors.md"
---

# Other sensors

## Temperature sensing

The emonTx4 supports temperature sensing via [DS18B20 temperature sensors](../electricity-monitoring/temperature/DS18B20-temperature-sensing.md) when using the single phase emonLibCM *emonTx4_CM_6CT_temperature* firmware. 

These are small temperature sensors with a 12-bit ADC and a digital output all in the sensor itself. Communication is over a one-wire bus and requires little in the way of additional components. The sensors have a quoted accuracy of ±0.5°C in the range -10°C to +85°C.

It is possible to connect DS18B20 temperature sensors to the emonTx4 either via the 3 pluggable terminal blocks or via the RJ45 connector (just to the left of the terminal blocks in the picture below, see pinout at the bottom of this page).

Pluggable terminal block connections are: GND (black), DATA (white), 3.3V (red), left to right, repeated for each of the three blocks:

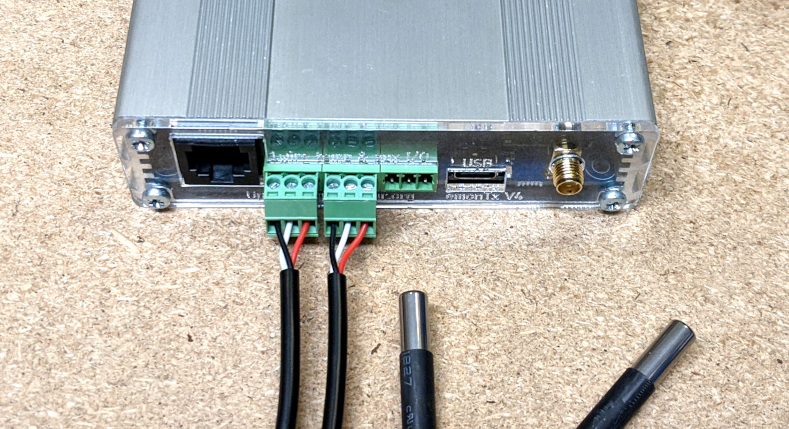
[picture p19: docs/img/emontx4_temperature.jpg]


The function of the emonTx4 terminal blocks can be changed with small solder-jumpers just above the terminals on the emonTx4 PCB. The default configuration is 3x temperature sensor inputs, one on each terminal block. Notice the bridged solder jumpers circled in red and labeled 'TMP' in the picture below: 

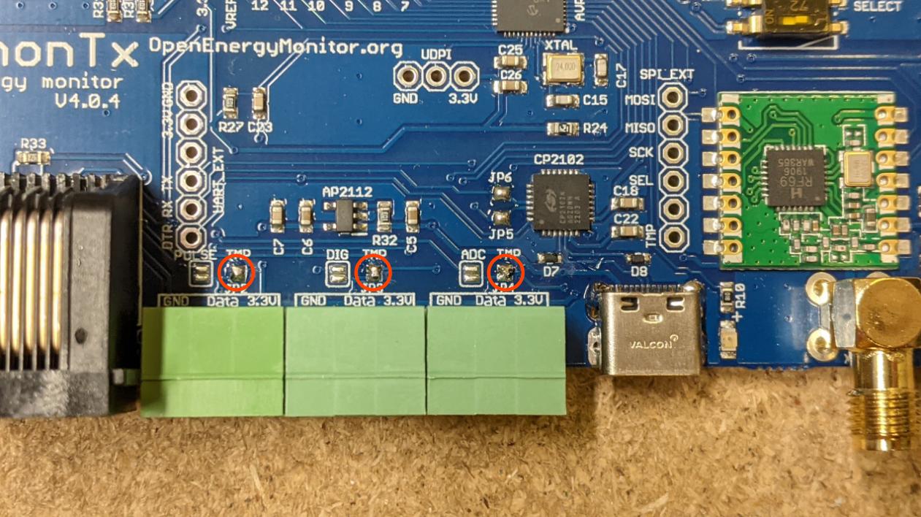
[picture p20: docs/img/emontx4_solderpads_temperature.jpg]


The DS18B20 input is connected to digital PIN_PB4 on the AVR128DB48 microcontroller.

```{tip}
It's possible to change the function of the 'Data' pin on each of the terminal blocks. 

- Terminal 1 (left) can be either temperature sensing or pulse input. 
- Terminal 2 (middle) can be either temperature sensing or digital input/output PA7. 
- Terminal 3 (right) can be either temperature sensing or analog input AIN19 (CT12).

Move the solder link as required to configure these for your application. Additional firmware changes are required to make use of the digital input/output PA7 and the analog input AIN19 (CT12).
```

The *emonTx4_CM_6CT_temperature* firmware supports up to 3x temperature sensors by default. This can be extended to support up to 6x temperature sensors by changing the firmware setting `MAX_TEMPS` at the top of the firmware file *(see base firmware `emon_CM_6CT_temperature` from the [avrdb_firmware](https://github.com/openenergymonitor/avrdb_firmware) repository)*:

```
// 8. The maximum number of temperature sensors that can be read
#define MAX_TEMPS 3
```

**Note:** Due to the way that the one wire protocol works, specifically its requirement for precise timing requiring brief periods of disabling other interrupts on the microcontroller, there is a minor negative impact on electricity monitoring performance when adding temperature sensors. An introduction of ~0.04% error with 3 temperature sensors or 0.07% error with 6 temperature sensors, out of a maximum component tolerance error of 1.2%. Please see the detailed forum post on this here: [EmonTx4 DS18B20 Temperature sensing & firmware release 1.5.7](https://community.openenergymonitor.org/t/emontx4-ds18b20-temperature-sensing-firmware-release-1-5-7/23496).

Temperature sensing is unfortunately not supported when using the more recent emonLibDB electricity monitoring library and associated firmwares: *emonTx_DB_6CT_1phase*, *emonTx_DB_6CT_3phase* and *emon_DB_12CT*. There is more going on in this electricity monitoring library in order to support 3-phase measurement and it was not possible to integrate temperature sensing in the same way. Please use the earlier single phase emonLibCM based firmware *emonTx4_CM_6CT_temperature* if you do require temperature sensing at the emonTx4 measurement point. 

For applications that require temperature sensing and 3phase emonTx4 monitoring or up to the 12 CT sensors, we recommend using a seperate USB powered emonTH2 with multiple external temperature sensors to achieve this.

## Pulse counting

- The pulse counting input on the emonTx4 is available as standard on the RJ45 socket (see pinout below).

- When compiling firmware make sure to set `#define PULSE_PIN 1` to select the standard emonTx4 digital input.

- The same pulse input can be configured for use on the first pluggable terminal block (closest to the RJ45 socket) as seen in the picture below with a solder bridge on solder jumper marked 'PULSE'. Solder bridge marked 'TMP' must also be removed.

- The pinout of the terminal block is: GND, PULSE INPUT, 3.3V.

- The pulse input is connected to PIN_PA6 on the AVR128DB48 microcontroller.

- With custom firmware modification and correctly configured solder bridges, further pulse inputs could be added to the other terminal block inputs as well. The middle pin of the second terminal block can be connected to PIN_PA7, the middle pin of the third terminal block is connected to PIN_PF3 (alternatively analog input 19).

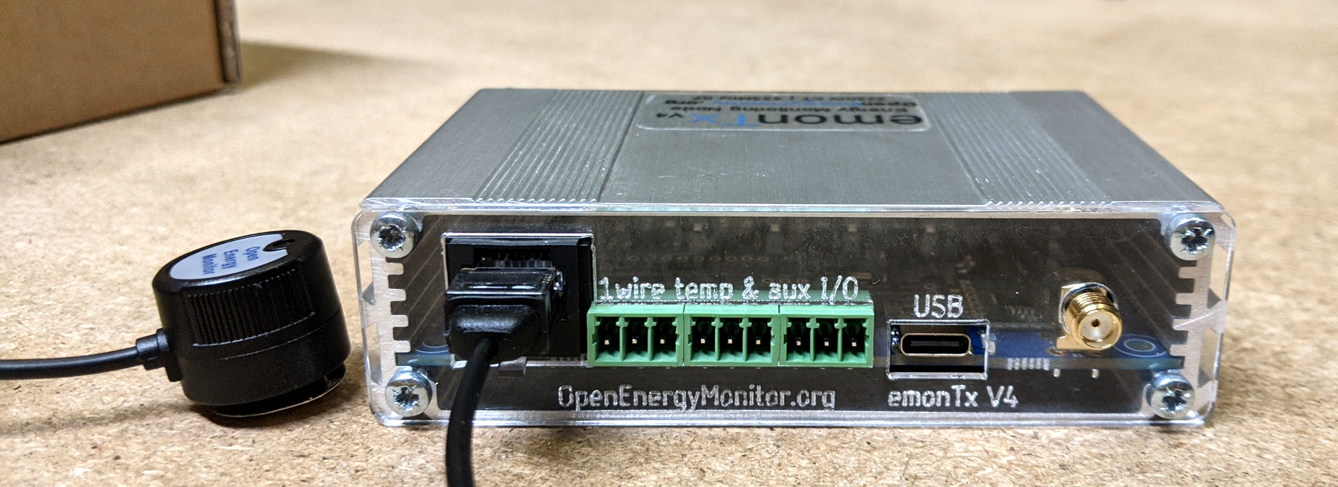
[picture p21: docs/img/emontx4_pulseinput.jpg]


## Analog input

It's possible to link analog input AIN19 (CT12) to right-most terminal block as shown below, the analog input is also available via the RJ45 socket (see pinout below). An example application is measuring flow rate using a Sika VFS which has an analog voltage output.

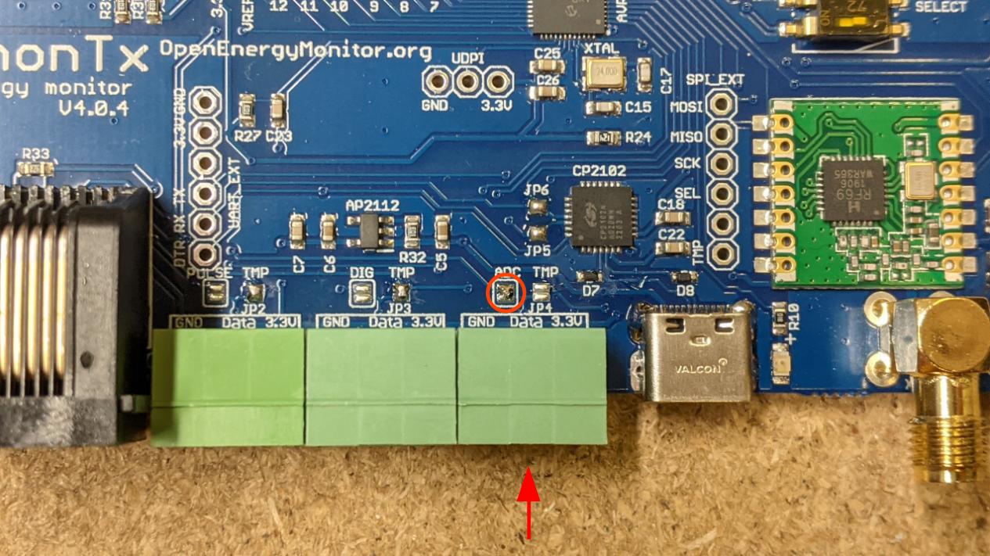
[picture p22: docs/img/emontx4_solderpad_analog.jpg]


```{warning}
The analog input voltage must be in the range **0 - 1.024V**. This ADC is configured for this range in order to suit the 333mV CT sensors. This analog input can not be used when using the emonTx4 with the C.T Extender board.
```

**How to use the analog input:**

Using the analog input requires compiling and uploading custom configuration of the emonTx4 firmware. Start by setting up the Arduino IDE environment following the [firmware guide](firmware.md).

For applications that require an analog input and temperature sensing open the base firmware `emon_CM_6CT_temperature` from the [avrdb_firmware](https://github.com/openenergymonitor/avrdb_firmware) firmware repository.

1\. Make sure to select emonTx4 as the hardware variant:

```
// 1. Set hardware variant
// Options: EMONTX4, EMONTX5, EMONPI2
#define EMONTX4
```

2\. Uncomment the line `#define ENABLE_ANALOG`:

```
// 6. Enable analog reading (disabled by default)
// IF ENABLED CHANGE NUM_I_CHANNELS = 5
// #define ENABLE_ANALOG
```

3\. Set `NUM_I_CHANNELS = 5`. We need to use one of the CT sensor ADC channel input allocations for the analog input instead:

```
// 4. Set number of current channels
#define NUM_I_CHANNELS 5
```

4\. Compile and upload the firmware to the emonTx4. 

## RJ45 Pinout

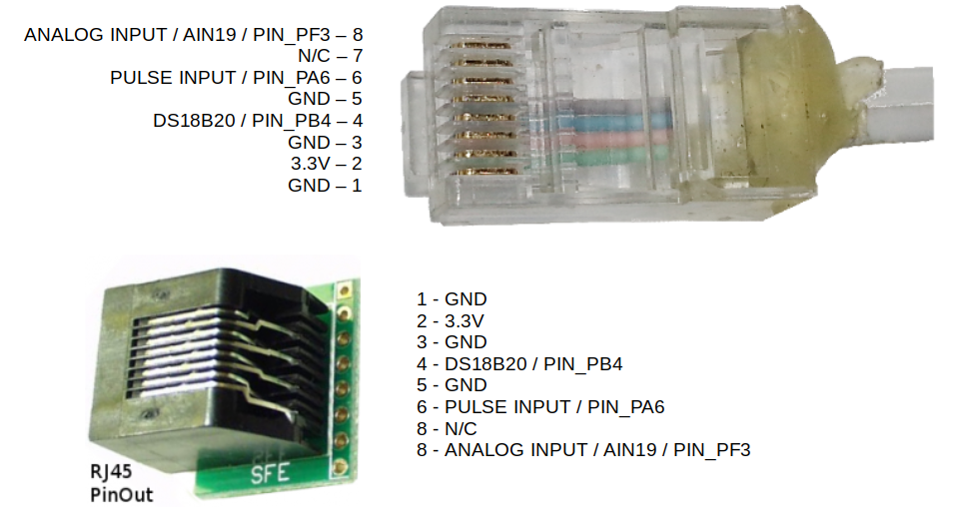
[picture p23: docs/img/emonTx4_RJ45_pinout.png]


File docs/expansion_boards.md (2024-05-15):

---
github_url: "https://github.com/openenergymonitor/emontx4/blob/main/docs/expansion_boards.md"
---

# Expansion boards

The emonTx4 has been designed to make it possible to expand its capability through expansion boards. These mostly focus around adding Wi-Fi communications but there's also a CT channel expansion board for more channels.

Not all of these expansion boards made it to production and have been labelled below as *Development only*. The initial goal was to try a range of options in an open development process, we then selected the WiFi connectivity option that we had the most mature software for given other issues that would have needed to have been addressed to make the other options production ready.

 We have kept the *development only* expansion boards here in the documentation for anyone interested in picking up the design files and software that we did put together.

## 6 CT Expansion Board

See dedicated page: [6 CT Expansion board](6ct_expansion_board.md)

## Adafruit ESP8266 Huzzah Wi-Fi Expansion Board

*This expansion board was stocked in the shop alongside the emonTx4 as an option to provide WiFi connectivity from 2022-2023. We still have spare ESP8266 expansion board bare PCB's please email the shop if you would like to add this to an existing emonTx4.* 

A simple adapter board that links the ESP8266 Huzzah Wi-Fi board to the EmonTx4. Can run the full EmonESP firmware which can be used to forward the emonTx4 data to Emoncms via HTTP or MQTT. Other firmware examples include an encrypted client with a serial configuration interface. See below.

When mounted on the emonTx4, the ESP8266 Huzzah module sits inverted so as to fit in the emonTx4 enclosure:

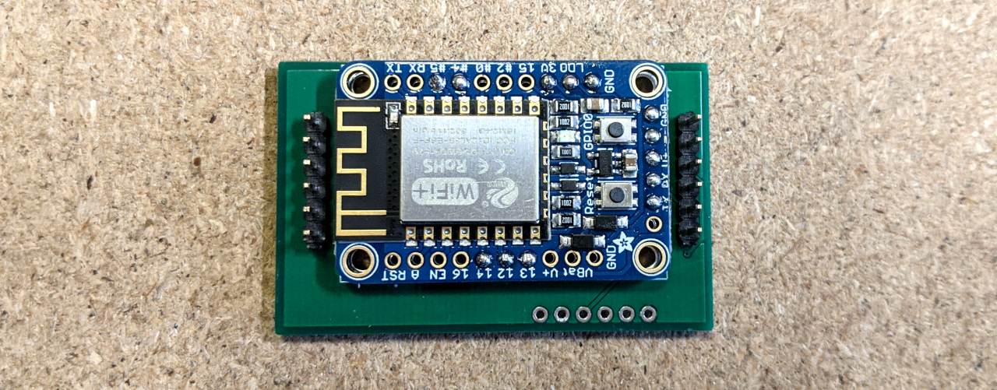
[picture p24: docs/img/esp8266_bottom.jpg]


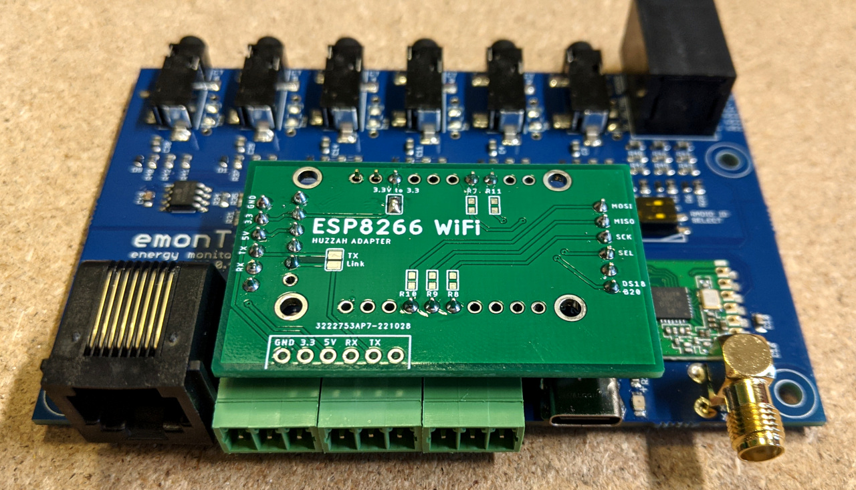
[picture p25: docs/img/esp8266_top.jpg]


**Note:** The ESP8266 adapter PCB design includes the option to solder additional SMT resistors that enable the ESP8266 to take control of the RFM69 Radio module and temperature sensing on the main emonTx4 board. 

### Software Examples

**Arduino / Platform IO**

- [EmonESP](https://github.com/openenergymonitor/EmonESP) (see the [EmonESP user guide](https://github.com/openenergymonitor/emonesp))
- [Basic emoncms client](https://github.com/openenergymonitor/emontx4/tree/main/expansion_boards/ESP8266/examples/basic_emoncms_client)
- [Emoncms client with encryption](https://github.com/openenergymonitor/emontx4/tree/main/expansion_boards/ESP8266/examples/emoncms_client_with_encryption)
- [Emoncms client with encryption & serial config](https://github.com/openenergymonitor/emontx4/tree/main/expansion_boards/ESP8266/examples/emoncms_client_encryption_serialconfig)

### Schematic and board file

- [Eagle files](https://github.com/openenergymonitor/emontx4/tree/main/expansion_boards/ESP8266/hardware)
- [Schematic image](https://github.com/openenergymonitor/emontx4/blob/main/expansion_boards/ESP8266/hardware/schematic.png)
- [Board image](https://github.com/openenergymonitor/emontx4/blob/main/expansion_boards/ESP8266/hardware/board.png)

---

## Pi Pico WiFi Expansion Board (Development only)

*The adapter board never made it to production as we decided to focus on the ESP8266 Wi-Fi expansion board above which had more mature software. We do however have plenty of spare Pi Pico WiFi Expansion Board PCB's if using this is of interest to anyone. Please email the shop if you would like to add this to an existing emonTx4.*

The Raspberry Pi Pico W is a wireless-enabled version of the original Pi Pico based on the RP2040 chip. This simple expansion board just maps the Pi Pico W pins to the UART and SPI headers on the emonTx4.



### Software Examples

**Arduino**

- [Basic emoncms client](https://github.com/openenergymonitor/emontx4/blob/main/expansion_boards/PiPico/examples/arduino/basic_emoncms_client/basic_emoncms_client.ino)
- [Emoncms client with encryption](https://github.com/openenergymonitor/emontx4/blob/main/expansion_boards/PiPico/examples/arduino/emoncms_client_with_encryption/emoncms_client_with_encryption.ino)
- [Serial config example](https://github.com/openenergymonitor/emontx4/blob/main/expansion_boards/PiPico/examples/arduino/serial_config_struct/serial_config_struct.ino)
- **[Emoncms client with encryption & serial config](https://github.com/openenergymonitor/emontx4/blob/main/expansion_boards/PiPico/examples/arduino/emoncms_client_encryption_serialconfig/emoncms_client_encryption_seri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)**

**MicroPython**

- [Basic emoncms client](https://github.com/openenergymonitor/emontx4/tree/main/expansion_boards/PiPico/examples/micropython)

### Uploading Arduino code

This guide provides a good overview of getting started with the Pi Pico W and Arduino IDE: [https://dronebotworkshop.com/picow-arduino](https://dronebotworkshop.com/picow-arduino)

### Uploading MicroPython

1. Download the latest MicroPython Pi Pico W build from here: [https://micropython.org/download/rp2-pico-w](https://micropython.org/download/rp2-pico-w) and drop it onto the drive created by the Pi Pico when plugged in via USB to your computer.
2. Install Adafruit Ampy, see: [https://pypi.org/project/adafruit-ampy](https://pypi.org/project/adafruit-ampy)
3. Upload the micropython example using ampy, e.g:

```
ampy --port /dev/ttyACM0 put basic_emoncms_client.py main.py
```

---

## ESP32 Wi-Fi Expansion Board (Development only)

*The adapter board never made it to production as we decided to focus on the ESP8266 Wi-Fi expansion board above which had more mature software. We do however have a small number of spare PCB's if using this is of interest to anyone. Please email the shop if you would like to add this to an existing emonTx4.*



### Software Examples

**Arduino / Platform IO**

- [Basic emoncms client](https://github.com/openenergymonitor/emontx4/tree/main/expansion_boards/ESP32/examples/basic_emoncms_client)
- [Emoncms client with encryption](https://github.com/openenergymonitor/emontx4/tree/main/expansion_boards/ESP32/examples/emoncms_client_with_encryption)
- [Emoncms client with encryption & serial config](https://github.com/openenergymonitor/emontx4/tree/main/expansion_boards/ESP32/examples/emoncms_client_encryption_serialconfig)
- [Emoncms client with encryption & serial config & display](https://github.com/openenergymonitor/emontx4/tree/main/expansion_boards/ESP32/examples/emoncms_client_encryption_serialconfig_display)
- [RFM69 SPI test](https://github.com/openenergymonitor/emontx4/tree/main/expansion_boards/ESP32/examples/rfm69cw_test)

---

## Pi Zero Expansion Board (Development only)

*The adapter board never made it to production as we decided to focus on the ESP8266 Wi-Fi expansion board above which had more mature software. We do however have a small number of spare PCB's if using this is of interest to anyone. Please email the shop if you would like to add this to an existing emonTx4.*



Starting with an SD card running emonSD:<br>
[https://github.com/openenergymonitor/emonpi/wiki/emonSD-pre-built-SD-card-Download-&-Change-Log](https://github.com/openenergymonitor/emonpi/wiki/emonSD-pre-built-SD-card-Download-&-Change-Log)

Configure EmonHub to use the EmonHubOEMInterfacer:<br>
[https://github.com/openenergymonitor/emonhub/tree/master/conf/interfacer_examples/OEM](https://github.com/openenergymonitor/emonhub/tree/master/conf/interfacer_examples/OEM)

    [[OEM]]
        Type = EmonHubOEMInterfacer
        [[[init_settings]]]
            com_port = /dev/ttyAMA0
            com_baud = 115200
        [[[runtimesettings]]]
            pubchannels = ToEmonCMS,

Errata: The PiZero needs to be powered seperately via a micro-USB cable (optionally sourced from the emonVs). We missed connecting the internal 5V rail to the expansion header in the first emonTx4 design that went to production, initially we didnt think the 5V rail would be needed but in hindsight this was an unfortunate oversight.

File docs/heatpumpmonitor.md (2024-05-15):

---
github_url: "https://github.com/openenergymonitor/emontx4/blob/main/docs/heatpumpmonitor.md"
---

# EmonTx4 Heatpump Monitor

This guide covers how to setup an emonTx4 as a heat pump monitor, measuring:

- Heat pump electrical consumption
- Immersion heater & backup heater consumption
- Flow temperature
- Return temperature
- Other temperatures e.g: DHW & outside
- Flow rate and heat output via an analog reading from a Sika VFS flow meter (supplied with many heat pumps, e.g: Mitsubushi EcoDan, Samsung & Daikin).



This can be used to create the full 'My Heatpump' emoncms dashboard, showing electric, heat, COP and system temperatures.

It's a configuration that is particularly well suited as a retrofit heat pump monitoring system that can be added on to a heat pump that is already installed, the CT sensors can be clipped on existing cables without rewiring, temperature sensors can be attached and an existing Sika flow meter interfaced with, without requiring draining down of the system and installation of a heat meter. 

This said, if you have the opportunity to install an inline class 1 electricity meter and class 2 heat meter, which requires electrical installation and system drain down, we would recommend that approach for higher accuracy, see our [emonHP system for more details](https://shop.openenergymonitor.com/level-3-heat-pump-monitoring-bundle-emonhp/).

## Hardware

The following outlines the kit we would recommend for an emonTx4 heat pump monitor installation. You may want to add more CT sensors or temperature sensors depending on your installation requirements.

- 1x emonTx4
- 1x emonVs-psu voltage sensor and power supply<br>*or the emonVs-mini together with a seperate power supply.*
- 1x+ CT sensors (rating and number as required)
- 2x+ DS18B20 temperature sensors<br>*firmware supports 3x by default, additional sensors can be added.*
- 1x+ Cable to read from Sika VFS analog output with integrated voltage divider.



## 1. Electricity monitoring

There are a number of different components that make up the electricity consumption of a heat pump, these can include:

1. Heat pump compressor and air source fan.
2. Control electronics often located alongside the compressor (usually in the outside unit of a monoblock air source heat pump).
3. Inside controllers
4. Central heating pumps
5. Zone or diverter valves
6. Immersion heater for legionella and DHW backup.
7. Backup direct electric heater
8. Fan assisted radiators
9. Other 3rd party controls
10. Monitoring 

**Mitsubishi Ecodan** heat pumps usually have 1,2,3,4 & 5 on one supply and circuit breaker, 6 & 7 will usually be connected seperately. 

On several EcoDan installations that we have worked with the outside unit was connected via an armoured cable to the main consumer unit - often some distance away. The primary pipework and a signal & power cable then run to a location inside the house where the inside controller is located alongside other components such as the central heating pump, diverter valve, hot water cylinder etc.

We often find that the most convenient place for the CT sensor that measures the electricity consumption of the EcoDan outside unit (and usually inside controller) is inside the outside unit itself, with a cable extension back to an emonTx4 located next to the inside controller. 

The following picture shows a 50A CT sensor on the main supply connection terminals inside the outside unit. This unit is a 11kW (heat output) unit which specifies a 32A MCB rating. The maximum current seen so far on this unit has been 17A.

```{warning}
The supply to the heat pump should be disconnected before opening the front panel on the outside unit. This work should only be carried out by a suitably competent person due to electrocution risk.
```



It's then often convenient to add additional CT sensors at the location of the inside controller to measure central heating pump electricity consumption and the immersion heater separately.



The CT sensors connect to the CT sensor inputs on the emonTx4. 

**Voltage sensing**<br>
For accurate electricity monitoring we would always recommend a voltage sensor. Without a voltage sensor the standby electricity consumption of a heat pump can read as high as ~270W when the real (active) power reading should actually be 12W! The EcoDan heat pumps that we have tested this on so far have all exhibited very low power factor, leading to these large differences between real (active) power and apparent power. The power factor is usually better when the heat pump is running with a difference of 10-20% between real power and apparent power.

The emonTx4 can either use the full emonVs-psu (voltage sensor and power supply) or the cheaper emonVs-mini (voltage sensor only). If using the emonVs-mini, a separate USB power supply is required. The installation picture above shows an installation with the full emonVs-psu.

## 2. Temperature sensing

The next step is to add temperature sensors. It can be useful to measure a wide range of system and environment temperatures when monitoring heat pumps. 

In the following example installation we are monitoring the flow and return temperatures in the primary pipework. Together with a flow rate measurement, we can use these to calculate the heat output of the heat pump.

We are also measuring the flow and return temperatures on the radiator side of the low loss header. These can be used to check how well balanced the flow rates in and out of the low loss header are and how much distortion is present.



It can also be worthwhile measuring:

- Outside temperature: can be used together with flow temperature to estimate Carnot COP)
- DHW tank temperature: useful for analysing DHW cycle timing and hot water use.
- Room temperatures: useful for analysing fabric efficiency or effectiveness of heat pump in providing comfort.

### Temperature sensor installation

The emonTx4 single phase *emonTx4_CM_6CT_temperature* firmware supports temperature sensing using DS18B20 temperature sensors. We supply these as encapsulated waterproof sensors in our shop. One of the challenges to accurate temperature measurement is mounting these to the flow and return primary pipework. John Cantor of [heatpumps.co.uk](https://heatpumps.co.uk), who we have worked with on heat pump monitoring, wrote a useful blog post with suggestions for different ways to mount these sensors here [Temperature sensing with OpenEnergyMonitor](https://heatpumps.co.uk/2015/06/08/temperature-sensing-with-openenergymonitor/).

The most accurate mounting method would be to use temperature sensor pockets which immerse the sensor in the fluid being measured. These however require a system drain down and plumbing work to install. 

When retrofitting monitoring to an existing system it's often more practical to mount the sensors to the outside of the pipework. The following illustrates one way of doing this, we are still experimenting with the best approach.

Testing the difference between sensor pockets and pipe surface measurement suggests that pockets read about 0.5C higher than measurements taken at the pipe surface. See temperature sensing error below.

1\. Remove the rubber heat shrink cover from the bottom end of the DS18B20 temperature sensor, this ensures that the sensor cylinder is in maximum contact with the pipe.

2\. Choose a straight piece of pipe where you can ensure a good insulation cover after installing the sensor, avoid attaching to fittings. Clean the copper pipe with some wire wool to remove any oxide layer.

3\. Place a little thermal paste (used for computer CPU heat sinks) on the pipe to aid conduction.

4\. In this example we have wound a length of solid core copper wire around the pipe and sensor with the idea that it will aid conduction of heat more evenly around the sensor body. A cable tie on the cable end of the sensor can help keep the sensor in place.



<!--![temperature_sensor_02.jpg](img/heatpump/temperature_sensor_02.jpg)-->

5\. Ensure that the sensor and pipework is well insulated.



6\. Connect temperature sensors to the emonTx



7\. Ensure that the emonTx4 solder bridges are configured for temperature sensing on the first two terminal blocks and analog on the last block:



### Temperature sensing error

A small error in temperature measurement can make a large difference to heat output measurement accuracy. To give an example, let's say we have a relative error between the flow and return temperature measurement of 0.2°C. If the flow rate is 20 L/min, the heat error is: 

    4200 J/kg.K x (20 L/min / 60 s/min) x 0.2 K = 280W

The DS18B20 temperature sensors that the emonTx4 supports have a maximum error of ±0.5°C from -10°C to +85°C. The typical error curve suggests a mean error of -0.2°C at 20°C decreasing to 0°C at 60°C. The default resolution set in the firmware is 11-bit which provides a resolution of 0.125°C.

For heat measurement the relative error between the flow and return temperature sensors is more important than the absolute error of the individual flow and return temperature measurements. 

```{image} img/heatpump/temperature_rel_error_test.jpg
:class: bg-primary
:width: 300px
:align: right
```

One relatively simple way to test this relative error is to attach the sensors to be installed together and take comparative measurements immersed in warm water. To give an example of the kind of difference we've observed, a test over 138 readings gave an average difference of 0.03°C between two sensors from the same batch and a 0.1°C comparing with a sensor from a different batch. The accuracy of the heat measurement could be improved by calibrating for these differences.

In our experience ecapsulated DS18B20 temperature sensors mounted to the surface of copper pipe as shown above can read ~0.5°C lower than sensors immersed in water using sensor pockets. The flow and return temperature sensors usually read lower by the same amount, which means the deltaT and heat measurement is not necessarily affected. Taking account of this difference and applying a manual adjustment may however be worthwhile when using the flow temperature sensor for carnot COP calculation.

```
T_condensing = T_flow + 4K
T_refrigerant = T_ambient - 6K
Carnot_COP = (T_condensing + 273) / ((T_condensing+273) – (T_evaporating + 273))
Practical_COP = 0.5 x  Carnot_COP (a real-life heat pump achieves about 50% its 'ideal' efficiency)
```

If the flow temperature measurement is measured as 30°C at the surface of the pipe rather than 30.5°C via a pocket and the outside temperature is 5°C. The difference in COP would be a predicted COP of 4.386 rather than 4.331, an error of around 1.3%. The difference in predicted heat output at 500W electrical input would be ~28W.

## 3. Reading from a Sika VFS analog output

Some heat pumps have a Sika VFS flow sensor installed as part of the standard installation package. The Sika VFS flow sensor looks like this:



If you have a Mitsubushi EcoDan, this will usually be installed near your EcoDan controller, which is often mounted close to the hot water tank.

The Sika VFS flow sensor that is usually installed alongside Mitsubushi EcoDan heat pumps has an output of 0.5V at 5L/min and 3.5V at 100L/min. The following lists typical flow rates and Sika VFS output voltages that we might see from a range of heat pump sizes:

- 5kW heat output at a dT of 5K is ~14 L/min (0.78V)
- 8kW heat output at a dT of 5K is ~23 L/min (1.07V)
- 11kW heat output at a dT of 5K is ~32 L/min (1.35V)
- 14kW heat output at a dT of 5K is ~40 L/min (1.61V)

We can see that at 23, 32 & 40 L/min the output voltage is higher than the 0-1.024V range of the analog input on the emonTx4. We therefore need to scale this voltage down to better fit the emonTx4 input voltage range. This can be done with a simple voltage divider.

In the example pictured below I have choosen a voltage divider with equal values for both top and bottom resistors, 100k each. This halves the voltage seen at the emonTx4 analog input pin. 1.61V will now become 0.8V and the maximum measurable flow rate is just over 50L/min.

Different voltage divider values can be choosen to best fit the range of flow rates expected.

 



## 4. Firmware

Open the base firmware `emon_CM_6CT_temperature` from the [avrdb_firmware](https://github.com/openenergymonitor/avrdb_firmware) firmware repository.

1\. Make sure to select emonTx4 as the hardware variant:

```
// 1. Set hardware variant
// Options: EMONTX4, EMONTX5, EMONPI2
#define EMONTX4
```

2\. Uncomment the line `#define ENABLE_ANALOG`:

```
// 6. Enable analog reading (disabled by default)
// IF ENABLED CHANGE NUM_I_CHANNELS = 5
// #define ENABLE_ANALOG
```

3\. Set `NUM_I_CHANNELS = 5`. We need to use one of the CT sensor ADC channel input allocations for the analog input instead:

```
// 4. Set number of current channels
#define NUM_I_CHANNELS 5
```

4\. Increase the number of temperature sensors if required (the first image above shows an example with 4x temperature sensors: primary flow and return and secondary flow and return after the low loss header). E.g increase the default MAX_TEMPS 3 to 4 if required:

```
// 8. The maximum number of temperature sensors that can be read
#define MAX_TEMPS 4
```

5\. Compile and upload the firmware to the emonTx4. 

## 5. Basestation or Wi-Fi adapter

The emonTx4 can transmit its data via: 

1. 433 MHz radio to a receiving emonBase basestation or emonPi.
2. USB cable direct connection to an emonBase/emonPi
3. Direct WiFi using an expansion board.

See guides:

- [Install Guide](emontx4_emonbase_install.md)
- [Adding to an existing install](emontx4_emonpi_install.md)
- [Expansion boards](expansion_boards.md)

If transmitting via 433 MHz radio, the following emonhub.conf node decoder is required to decode the radio packet data:

```
[[17]]
  nodename = emon_CM_6CT_temperature_17
  [[[rx]]]
    names = MSG, Vrms, P1, P2, P3, P4, P5, E1, E2, E3, E4, E5, T1, T2, T3, T4, pulse, analog
    datacodes = L,h,h,h,h,h,h,l,l,l,l,l,h,h,h,L,h
    scales = 1,0.01,1,1,1,1,1,1,1,1,0.01,0.01,0.01,1,1
    units = n,V,W,W,W,W,W,Wh,Wh,Wh,Wh,Wh,C,C,C,p,
```

## 6. Emoncms input configuration

The following set of screenshots gives an example of configuring this analog input for use in reading the flow rate from the Sika VFS flow sensor. The flow rate is then used together with measurement of flow and return temperature to calculate heat.

These screenshots are from the emonPi2 guide, the process is however exactly the same for the emonTx4:









## 7. Emoncms & MyHeatpump app

Emoncms includes an application specific heat pump dashboard available in the Apps module. The following video gives a good overview of what this dashboard can do, how to access daily electricity consumption and heat output data as well as detailed system temperature and power data.

There's also a little feature shown briefly at the end that simulates the heat output and COP of the heat pump based on the Carnot COP equation.

<div class='videoWrapper'>
<iframe width="560" height="315" src="https://www.youtube.com/embed/jBY1Sx3LR2o" frameborder="0" allowfullscreen></iframe>
</div>

It's also worth checking out David Bowen (@MyForest) heat pump app, see community forum post: [Heat Pump Experimentation App - Release News](https://community.openenergymonitor.org/t/heat-pump-experimentation-app-release-news/13423).

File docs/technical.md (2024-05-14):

---
github_url: "https://github.com/openenergymonitor/emontx4/blob/main/docs/technical.md"
---

# Technical Guide

## RFM69 Radio

The emonTx4 includes a 433 MHz RFM69CW radio on the board. This can be used to transmit data to an emonPi or emonBase base station. These radios provide a neat and simple way of sending data between devices.

The emonTx4 supports two different RFM69 radio formats:

1. LowPowerLabs (Default & Recommended)
2. JeeLib Classic (backwards compatibility mode)

There is a shop option to select between Standard (LowPowerLabs) and Backwards compatibility (JeeLib Classic) when ordering an emonTx4.



The radio format can also be changed by updating the firmware later using either the local emoncms firmware upload tool or the command line emonupload.py tool. See [Firmware](firmware.md).

The format can also be chosen when compiling the firmware, see the #define option towards the top of each firmware option:

```
// 2. Set radio format
// Options: RFM69_JEELIB_CLASSIC, RFM69_JEELIB_NATIVE, RFM69_LOW_POWER_LABS
#define RFM69_LOW_POWER_LABS
```

The LowPowerLabs format supports encryption. Please see encryption section below for details on how to secure this.

### Background on libraries and formats

We have used the RFM69CW radio now for quite a few years but the release of the emonTx4 brings with it an important change in the software implementation used for the radio. Up until this point we had been using the **JeeLib 'Classic' packet format.** This was built around compatibility with an earlier generation radio module called RFM12. The benefit of backwards compatibility however meant that some of the new features implemented on the RFM69 module could not be used. These included the FIFO data buffers which reduce the requirement to interrupt the main microcontroller (useful for energy monitoring) and hardware encryption. 

Jean Claude Wippler who originally developed the JeeLib library did develop a version of the library that made use of the new RFM69 features. He called the resulting packet format the **'Native' packet format**. There's a useful post on the differences [here](https://jeelabs.org/book/1522a/index.html). More recently Robert Wall adapted this JeeLib native library for use with the emonPi, to make continuous sampling possible.

The **LowPowerLabs packet format and library** is a separately developed project by [Felix Rusu of LowPowerLabs](https://github.com/LowPowerLab/RFM69). In terms of packet format and implementation it is in many ways similar to the JeeLib Native packet format library - in that it uses the native RFM69 module features. The radio settings such as bit rate are subtly different (55,555 bits/s vs 49,230 bits/s). The header section of the radio packet payload is also slightly differently enabling 1023 possible nodes, 256 possible networks and a control byte used for requesting acknowledgments.

**The emonTx4 uses the LowPowerLabs radio format by default.**<br>
The release of the emonTx4 was originally going to include the switch from the JeeLib Classic format to the JeeLib Native format, but in the end we've decided to make the switch to the LowPowerLabs library instead. 

This significant change was made primarily in order to make use of the packet acknowledgment and retry feature implemented in the LowPowerLabs library, which in testing was critical to bring packet loss down to the magic 0% level (with nodes within good signal range).

The second important benefit of this change is to have a radio format that is compatible with the wider actively developed LowPowerLabs RFM69 ecosystem. 

**Uncoordinated vs coordinated transmit**<br>
The present implementation can still be improved further, OpenEnergyMonitor nodes are still transmitting radio data in an uncoordinated way, which increases the likelihood of packet collisions and therefore packet loss. Nodes do listen briefly for a quiet radio window and the emonTx4 requests a packet acknowledgment, retrying if not heard, but there is a limitation to how many nodes that can practically be accommodated using this scheme alone.

The next step in development is to explore the option to either have the base station request data from each radio node in sequence or for the base station to broadcast some kind of timing coordination packet, say every 10s. Nodes would then offset the time at which they transmit by some delay relating to their unique node id's.

### Encryption

Encryption is enabled by default when using the LowPowerLabs or JeeLib Native packet formats.

**It is not however secure as the encryption key used is publicly available.** There is not yet a mechanism in place to generate and distribute the encryption key's to radio nodes in an automated way, or as part of an initial pairing process.

The default encryption key is currently hard coded in the firmware, e.g on line 230 of the emonTx4 firmware:

```
rf.encrypt("89txbe4p8aik5kt3");
```

In order to truly secure the radio network you can create your own secret 16 character encryption key. This encryption key needs to be copied to all radio nodes on the network, including the base-station.

The emonBase available for purchase with the emonTx4 in the OpenEnergyMonitor shop comes with an SPI RFM69 receiver board. The encryption key used for this is currently hard-coded in emonHub on line 51: [https://github.com/openenergymonitor/emonhub/blob/master/src/interfacers/EmonHubRFM69LPLInterfacer.py#L51](https://github.com/openenergymonitor/emonhub/blob/master/src/interfacers/EmonHubRFM69LPLInterfacer.py#L51).

This key needs to be modified here to match the secret key used on the emonTx4. The result will be a secure, encrypted radio network.

## Voltage sensing

The following LTSpice schematic & simulation describes the emonTx4 voltage sensing circuit.



*Download [voltage sensor LTSpice simulation](files/emonVs.zip)*

1. On the left, the mains supply is connected through a series of 10k, 0.1%, 250mW current limiting resistors. These add up to a total resistance of 60k. The primary winding of the ZMPT101B precision voltage transformer also has a series resistance of 120 Ohms. This means we would expect the current in the primary to be 3.992 mA at a mains voltage of 240V RMS.

2. The ZMPT101B precision voltage transformer itself has a 1:1 relationship between primary and secondary current. While the suggested current is 2mA on the datasheet the transformer is rated up to 10ma and the phase error is significantly less at 4mA than 2ma. 

3. Next we convert the secondary current to a voltage using the burden resistor (R2, 75R, 0.1%). The burden resistor alone would give a voltage output of 299.4mV RMS when the mains voltage is 240V.

4. The actual output voltage is a little less due to the impedance of the bias circuit. We can treat R5 (180k) and R6 (33k) as being in parallel with the burden resistor R2. The effective resistance is then: 1/((1/75)+(1/33000)+(1/180000)) = 74.799 Ohms. This gives an output voltage of 298.6 mV.

5. The output voltage as simulated by LTSpice taking into account the indicated inductance values of the voltage sensing transformer, small effect of the RJ11 cable resistance and capacitor C1 is a little lower at 297.55 mV.

6. The above suggests a calibration value of 240 / 0.29755 = 806.58.  

**Update 14th May 2024:** The actual calibration value as applied over serial or hardcoded for emonTx4 firmware now uses the emonLibDB approach of setting this as a % value of 800, where 800 would be 100.0% and 806.58 is 100.8%.

7. If we use this calibration value in the emonTx4 firmware and compare the resulting RMS voltage with parallel measurement from SDM120 electric meters we usually see the SDM120 voltage measurement reading about 0.3% higher. This suggests a calibration value of:<br>`806.58 × 1.003 = 809.0` or 101.1%

8. If we compare with a non-isolated version of the circuit above (omitting the ZMPT101B) consisting of a voltage divider with R1 (top) = 60k and R2 (bottom) = 75 Ohms. The RMS voltage difference is ~0.2%. This suggests that the voltage calibration for a single emonTx4 should be:<br>`806.58 × 1.002 = 808.2` or 101.0%.

9. The difference between the LTSpice simulated voltage output derived calibration and calibration based on comparison to an SDM120 or the non-isolated voltage sensor test is likely due to three main factors:

    - Transformer coupling factor
    - Error in the inductance value used in the simulation
    - Higher coil impedance due to higher coil temperature @ 4ma.
  
Work is ongoing to improve these parameters used in the LTSpice simulation.

**Phase angle error**

An important factor with both voltage and current sensing is phase error. The following chart from the ZMPT101B datasheet shows the phase error at different input currents. 

We have chosen current limiting resistors on the primary to give an input current of ~4mA at 240V RMS and 2mA at 120V RMS in order to reduce both the extent of the phase error and the variation - the curve is flatter between 2mA and 4mA than it is between 1mA and 2mA.

This does of course have a small penalty in terms of increased power consumption. Increasing from 0.5W at 2mA to 1W at 4mA.



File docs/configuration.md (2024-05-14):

---
github_url: "https://github.com/openenergymonitor/emontx4/blob/main/docs/configuration.md"
---

# Configuration

## Default configuration

**Updated 14th May 2024 to reflect updated configuration for new firmware release**. These use the same calibration format for both emonLibCM based firmwares and emonLibDB based firmwares.

The emonTx4 comes as standard with the following default configuration:

- **emonVs:** (Vcal: 101.3)
- **CT 1:** 100A 0.333V (Ical: 100.0, Ilead: 3.2)
- **CT 2:** 50A 0.333V (Ical: 50.0, Ilead: 3.2)
- **CT 3:** 50A 0.333V (Ical: 50.0, Ilead: 3.2)
- **CT 4:** 20A 0.333V (Ical: 20.0, Ilead: 3.2)
- **CT 5:** 20A 0.333V (Ical: 20.0, Ilead: 3.2)
- **CT 6:** 20A 0.333V (Ical: 20.0, Ilead: 3.2)
- **Transmit via RFM69CW:** ON
- **Radio nodeid:** 17
- **Radio group:** 210
- **Radio frequency:** 433 MHz
- **Datalogging period:** 9.8s 
- **Minimum pulse period:** 100ms

To use the emonTx4 with a different CT arrangement, radio node or group, these settings can be adjusted over serial using either an online web tool or directly via a serial console. 

Alternatively it’s possible to configure the emonTx4 directly via serial using the arduino serial.

## Using the web tool

**Note: Communication via USB-C will only work if connected in the right orientation. Try turning the USB-C connector around if upload fails.** Some USB-C connectors have a smooth side on one side and jagged connection of the metal fold on the other. On the cables we have here, the smooth side should be facing up towards the top/front face of the emonTx4:





With the emonTx connected to a computer via a [USB-C to USB-A cable](https://shop.openenergymonitor.com/1m-usb-c-cable/) (USB-C to USB-C is **not** supported), it's possible to configure the emonTx directly from a WebSerial compatible internet browser. 

*Note: To connect to a computer that only has a USB-C port, use a USB-C to USB-A cable, together with a USB-A to USB-C adaptor.*

The process is plug-and-play on Mac and Linux, but windows users will need to install a driver for the emonTx serial (CP210x): [Windows 10 Driver Download](https://www.silabs.com/developers/usb-to-uart-bridge-vcp-drivers?tab=downloads)

Compatible browsers: [Chrome, Edge, Opera](https://developer.mozilla.org/en-US/docs/Web/API/Web_Serial_API#browser_compatibility)

**Launch the tool: [openenergymonitor.org/serial](https://openenergymonitor.org/serial/)**

- Click 'Connect` and allow the connection to the serial port. The emonTx V4 appears as a CP210x serial port 
- Make changes to the configuration
- Click 'Save' 

Monitoring data from the emonTx is displayed in the serial window 

*Note: Firefox is not currently supported*



## Directly via serial

Alternatively it's possible to configure the emonTx4 directly via serial using the arduino serial monitor or other similar tool. 
The following details the available commands and their function.

Available commands:

- **l** list the settings
- **r** restore sketch defaults
- **s** save settings to EEPROM
- **v** show firmware version
- **z** zero energy values
- **x** exit, lock and continue
- **?** show this text again
- **w\<x\>** turn RFM Wireless data off: x = 0 or on: x = 1
- **b\<n\>** set r.f. band n = a single numeral: 4 = 433MHz, 8 = 868MHz, 9 = 915MHz (may require hardware change)
- **p\<nn\>** set the r.f. power. nn - an integer 0 - 31 representing -18 dBm to +13 dBm. Default: 25 (+7 dBm)
- **g\<nnn\>** set Network Group nnn - an integer (OEM default = 210)
- **n\<nn\>** set node ID n= an integer (standard node ids are 1..60)
- **d\<xx.x\>** a floating point number for the datalogging period
- **c\<n\>** n = 0 for OFF, n = 1 for ON, enable current & power factor values to serial output for calibration.
- **f\<xx\>** the line frequency in Hz: normally either 50 or 60
- **k\<x\> \<yy.y\> \<zz.z\>**
  - Calibrate an analogue input channel:
  - x = a single numeral: 0 = voltage calibration, 1 = ct1 calibration, 2 = ct2 calibration, etc
  - yy.y = a floating point number for the voltage/current calibration constant
  - zz.z = a floating point number for the phase calibration for this c.t. (z is not needed, or ignored if supplied, when x = 0)
  - e.g. k0 256.8
  - k1 90.9 2.00
- **a\<xx.x\>** a floating point number for the assumed voltage if no a.c. is detected
- **m\<x\> \<yy\>** meter pulse counting: 
  - x = 0 for OFF, x = 1 for ON
  - yy = an integer for the pulse minimum period in ms. (y is not needed, or ignored when x = 0)
- **t\<x\>** turn temperature measurement on or off: x = 0 for OFF, x = 1 for ON

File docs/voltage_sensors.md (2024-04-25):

---
github_url: "https://github.com/openenergymonitor/emontx4/blob/main/docs/voltage_sensors.md"
---

# Voltage sensors

## Overview

There are 3 different voltage sensor options that are compatible with the emonTx4. While the **standard voltage sensor available in the bundle is the emonVs-PSU** (voltage sensor and power supply) you may want to select a different voltage sensor depending on your installation and requirements.

Here is a quick overview of the 3 options:



## emonVs-PSU

A combined precision 1-3 phase **voltage sensor and power supply** unit. When bought as a single-phase variant is comes with a cable and plug for use with a standard AC socket outlet but it can alternatively be installed by a suitably competent person into a 6A or lower circuit protection device in the fuse board (consumer unit) or a 3A fused spur (Note: The supplied emonVs mains power cable has a cross sectional area of 1.5mm^2). This can provide a tidy installation if no socket is available and helps ensure higher monitoring uptime if sockets are at risk of being unplugged for use by other appliances.

The following picture shows what is inside the box for the single phase configuration. The 3-phase variant includes 3x ZMPT101B precision voltage transformers (T1, T2 & T3), 3x fuses (F1, F2 & F3) and 3x MOV surge protectors (M1, M2 & M3). One of each for each phase.



- Supports a range of mains voltages 120-240V, US, EU, UK.
- Output AC voltage signal on RJ11 @ 120V = (120V / 60k 0.1%) x 75R 0.1% = 150 mV
- Output AC voltage signal on RJ11 @ 240V = (240V / 60k 0.1%) x 75R 0.1% = 300 mV
- Precision current-type voltage transformer: ZMPT101B (0.2%) 
- Combined tolerance of voltage sensor components: 0.4%
- 10W Mornsun power supply can power both the emonTx v4 (via RJ11) and the emonBase (via USB-C)
- 1A Fuse, MOV surge protector, Common mode choke & filter capacitor.
- Wall mountable.

## emonVs-mini

A simple single-phase precision **voltage sensor only** (no integrated power supply). The emonTx4 will require a separate power supply/source when used with this voltage sensor. Supplied with a mains cable and plug for use with a standard AC socket outlet.

This can be a good solution if you have sockets near by and a spare USB power supply that can be used to power the emonTx4. An existing emonPi or emonBase could also be used to power and read data from the emonTx4 over USB.



- Supports a range of mains voltages 120-240V, US, EU, UK.
- Output AC voltage signal on RJ11 @ 120V = (120V / 60k 0.1%) x 75R 0.1% = 150 mV
- Output AC voltage signal on RJ11 @ 240V = (240V / 60k 0.1%) x 75R 0.1% = 300 mV
- Precision current-type voltage transformer: ZMPT101B (0.2%)
- Combined tolerance of voltage sensor components: 0.4%
- 1A Fuse & MOV surge protector
- Wall mountable.

## ACAC Converter

If you already have an ACAC adapter voltage sensor spare from one of our earlier units e.g emonTx2, emonTx3 or emonPi. This small adapter can be used to convert the voltage and connector to the ~300mV RJ11 input on the emonTx4. The tolerance of the ACAC adapters are ±3% and voltage divider resistors will be ±1% (not pictured), the accuracy of using an ACAC adapter can be improved with careful calibration, more details to follow.



Available as a development board in the shop soon.

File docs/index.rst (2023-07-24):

emonTx4 User Guide
==================

.. toctree::
   :maxdepth: 2
   
   overview.md
   Install Guide <emontx4_emonbase_install.md>
   Adding to an existing install <emontx4_emonpi_install.md>
   Heatpump monitor <heatpumpmonitor.md>
   configuration.md
   firmware.md
   hardware.md
   technical.md
   voltage_sensors.md
   Temperature, Pulse & Analog <other_sensors.md>
   expansion_boards.md
   6ct_expansion_board.md

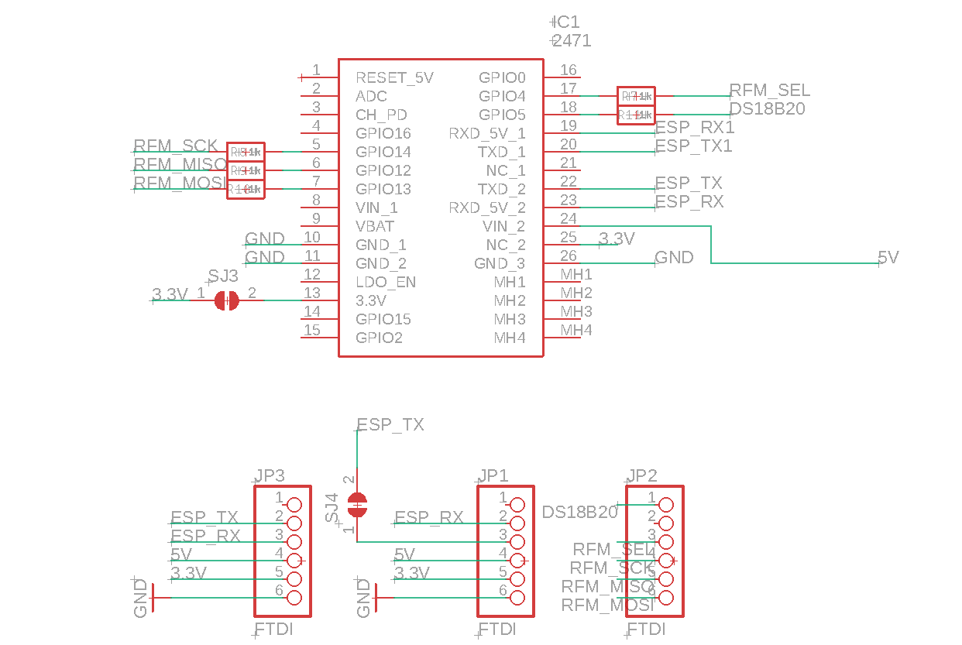
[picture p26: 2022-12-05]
expansion_boards/ESP8266/hardware/schematic.png

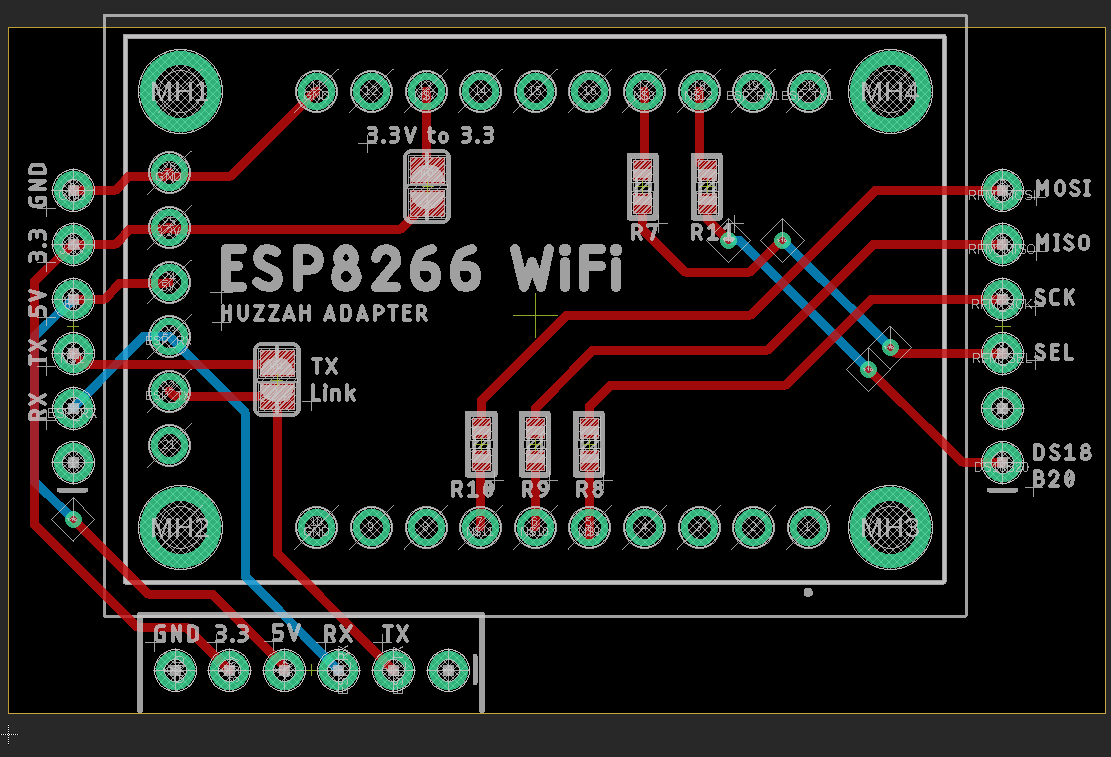
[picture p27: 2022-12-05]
expansion_boards/ESP8266/hardware/board.png

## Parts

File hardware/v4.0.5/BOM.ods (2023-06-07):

Qty | Schematic Reference | MPN | Octopart URL | Part Description
11 | D1, D2, D3, D4, D5, D6, D7, D8, D9, D10, D11 | UCLAMP3301H.TCT | https://octopart.com/uclamp3301h.tct-semtech-587385 | UCLAMP Series 8 V 25 pF Low Voltage uClamp for ESD & CDE Protection - SOD-523
10 | R1, R2, R10, R19, R20, R25, R26, R28, R37, R40 | CR0603-FX-1001ELF | https://octopart.com/cr0603-fx-1001elf-bourns-2326646 | SMD Chip Resistor, 1 kOhm, ± 1%, 100 mW, 0603 [1608 Metric], Thick Film, General Purpose
9 | R6, R12, R14, R17, R23, R42, R48, R46, R44 | CRGCQ0603F180K | https://octopart.com/crgcq0603f180k-te+connectivity-91018046 | SMD Chip Resistor, 180 kOhm, ± 1%, 100 mW, 0603 [1608 Metric], Thick Film, General Purpose
9 | R4, R11, R13, R15, R21, R41, R47, R45, R43 | CRG0603F33K | https://octopart.com/crg0603f33k-te+connectivity-16077362 | SMD Chip Resistor, 33 kOhm, ± 1%, 100 mW, 0603 [1608 Metric], Thick Film, High Power
10 | C30, C29, C16, C14, C11, C8, C4, C3, C2, C1 | CC0603KRX5R5BB106 | https://octopart.com/cc0603krx5r5bb106-yageo-20204858 | Multilayer Ceramic Capacitor, 10 uF, 6.3 V, ± 10%, X5R, 0603 [1608 Metric]
8 | C7, C10, C18, C20, C22, C23, C25, C27 | CL10B104KB8NNWC | https://octopart.com/cl10b104kb8nnwc-samsung-23795471 | Multilayer Ceramic Capacitor, 0.1 uF, 50 V, ± 10%, X7R, 0603 [1608 Metric]
6 | J1, J2, J3, J4, J5, J6 | SJ-3524-SMT-TR | https://octopart.com/sj-3524-smt-tr-cui+devices-106234236 | 3.5 mm, Stereo, Right Angle, Surface Mount (SMT), Audio Jack Connector
5 | C5, C6, C24, C26, C28 | CL10B105KO8NNNC | https://octopart.com/cl10b105ko8nnnc-samsung-19018973 | Multilayer Ceramic Capacitor, 1 uF, 16 V, ± 10%, X7R, 0603 [1608 Metric]
5 | R27, R30, R31, R32, R34 | ERA-3AEB103V | https://octopart.com/era-3aeb103v-panasonic-55403501 | Res Thin Film 0603 10K Ohm 0.1% 1/10W ±25ppm/°C Molded SMD SMD Punched Carrier T/R
3 | CN1, CN2, CN3 | 8971054 | https://octopart.com/8971054-rs+pro-103323948 | Pluggable Terminal Block Header 3 Pin 3.5mm Pitch 10A Right Angle Green Solder | RS PRO 8971054
2 | C15, C17 | 06035A220JAT2A | https://octopart.com/06035a220jat2a-avx-55386345 | Multilayer Ceramic Capacitor, 22 pF, 50 V, ± 5%, C0G (NP0), 0603 [1608 Metric]
2 | C19, C21 | GRM188R71A225KE15D | https://octopart.com/grm188r71a225ke15d-murata-197889 | Multilayer Ceramic Capacitor, 2.2 uF, 10 V, ± 10%, X7R, 0603 [1608 Metric]
1 | X1 | SMA RA CONNECTOR | https://octopart.com/sma+ra+connector-lprs-23943634 | Rf/Coaxial Connector, Sma Coaxial, Solder Rohs Compliant: Yes |Lprs SMA RA CONNECTOR
1 | U$13 | MTJ-881X1 | https://octopart.com/mtj-881x1-multicomp-10438668 | CAT5/CAT5E RJ45 Modular Jack 8POS 1 Port
1 | J9 | SS-6466-NF | https://octopart.com/ss-6466-nf-stewart+connector-55399276 | Telecom and Datacom Connector, 6 Contact(s), Female, Right Angle, Solder Terminal, Jack
1 | LED | 597-5111-407F | https://octopart.com/597-5111-407f-dialight-872730 | LED Uni-Color Red 660nm 2-Pin Chip 0805(2012Metric) T/R
1 | U$14 | RFM69CW-433S2 | https://octopart.com/rfm69cw-433s2-hoperf-107341092 | OEMs, CMs ONLY (NO BROKERS)
1 | XTAL | MCSJK-7U-24.00-12-30-60-B-30 | https://octopart.com/mcsjk-7u-24.00-12-30-60-b-30-multicomp-91739712 | CRYSTAL, 24MHZ, 12PF, 3.2mm X 2.5mm; Frequency Nom: 24MHz; Crystal Case: SMD, x Stability + / -: 30ppm; Load...
1 | IC1 | MCP1501-18E/SN | https://octopart.com/mcp1501-18e%2Fsn-microchip-65892139 | V-Ref Precision 1.8V 20mA 8-Pin SOIC N Tube
1 | USB-C | CSP-USC16-TR | https://octopart.com/csp-usc16-tr-valcon-107481004 | OEMs, CMs ONLY (NO BROKERS)
1 | CP2102 | CP2102N-A01-GQFN28 | https://octopart.com/cp2102n-a01-gqfn28-silicon+labs-74636024 | Full Speed Basic USB Type-C Controller USB 2.0 3.3V Tube 28-Pin QFN EP
1 | AVRDB | AVR128DB48T-I/6LX | https://octopart.com/avr128db48t-i%2F6lx-microchip-108145389 | 128KB, 8KB Ram, 48P, 24MHZ, 3XOPAMP, Mvio, 12B Adc, 3XZCD, Dac, Uart, 2XSPI, Twi
1 | AP2112 | AP2112K-3.3TRG1 | https://octopart.com/ap2112k-3.3trg1-diodes+inc.-30954557 | AP2112 Series 0.6 A 3.3 V Fixed Output SMT LDO Linear Regulator - SOT23-5
1 | R24 | RC0603FR-07120KL | https://octopart.com/rc0603fr-07120kl-yageo-40946039 | SMD Chip Resistor, 120 kOhm, ± 1%, 100 mW, 0603 [1608 Metric], Thick Film, General Purpose
1 | R33 | 3-2176339-3 | https://octopart.com/3-2176339-3-te+connectivity-91017476 | SMD Chip Resistor, 4.7 kOhm, ± 1%, 100 mW, 0603 [1608 Metric], Thick Film, General Purpose
1 | R35 | CRT0603-BY-10R0ELF | https://octopart.com/crt0603-by-10r0elf-bourns-10485904 | SMD Chip Resistor, 10 Ohm, ± 0.1%, 100 mW, 0603 [1608 Metric], Thin Film, Precision
1 | S3 | MCEMR-02-T | https://octopart.com/mcemr-02-t-multicomp-7505473 | Switch DIP OFF ON SPST 2 Recessed Slide 0.025A 24VDC Gull Wing 2000Cycles 2.54mm SMD

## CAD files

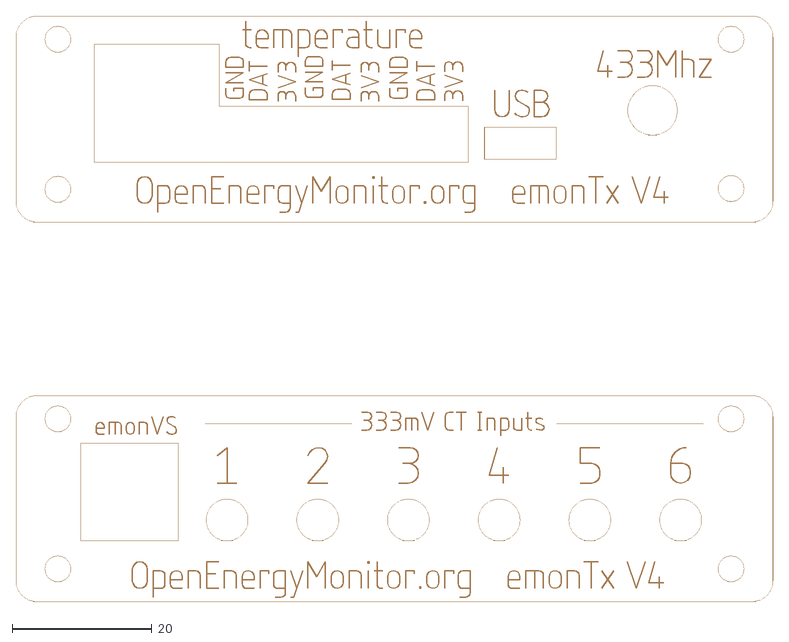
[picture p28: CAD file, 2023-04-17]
hardware/fascia/V1.2-fascia-emontxv4.dxf
108.5 x 83.9

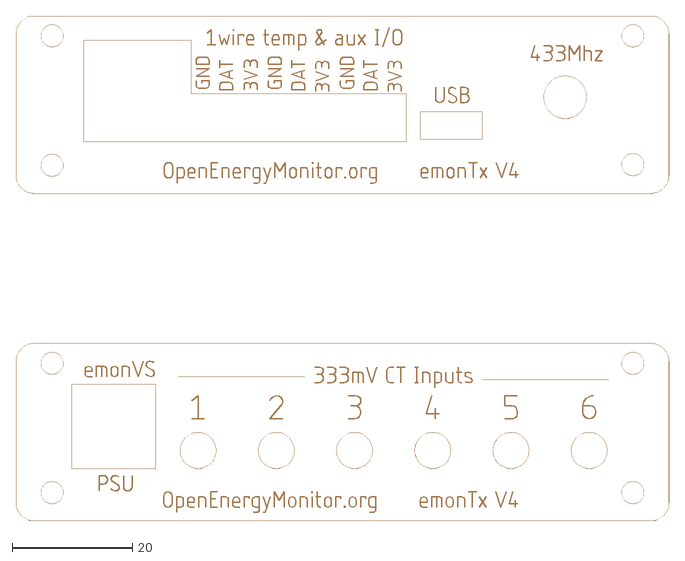
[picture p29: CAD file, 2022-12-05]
hardware/fascia/V1.1-fascia-emontxv4-2mm-clear-acrylic.dxf
108.5 x 83.9

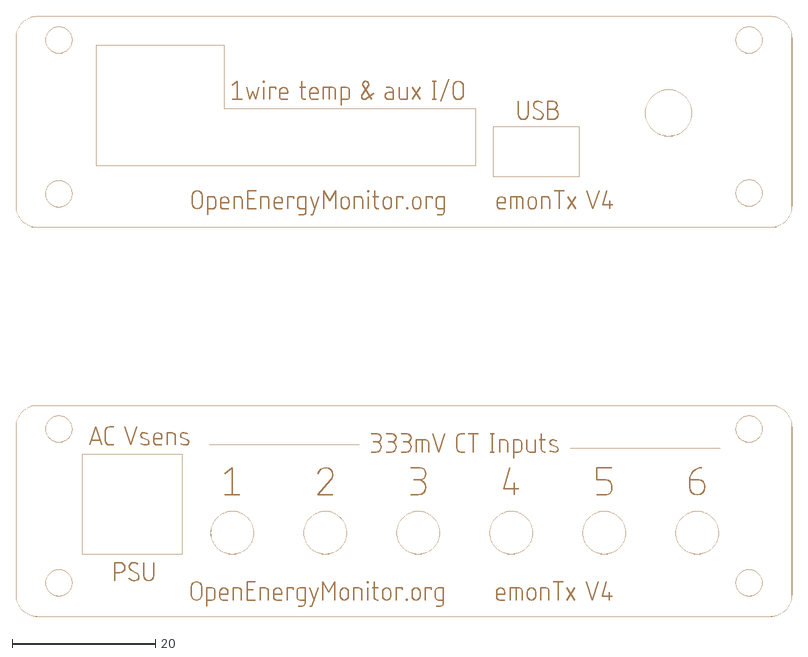
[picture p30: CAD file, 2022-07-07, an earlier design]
hardware/fascia/archive/V1.0-fascia-emontxv4-2mm-clear-acrylic.dxf
108.5 x 83.9

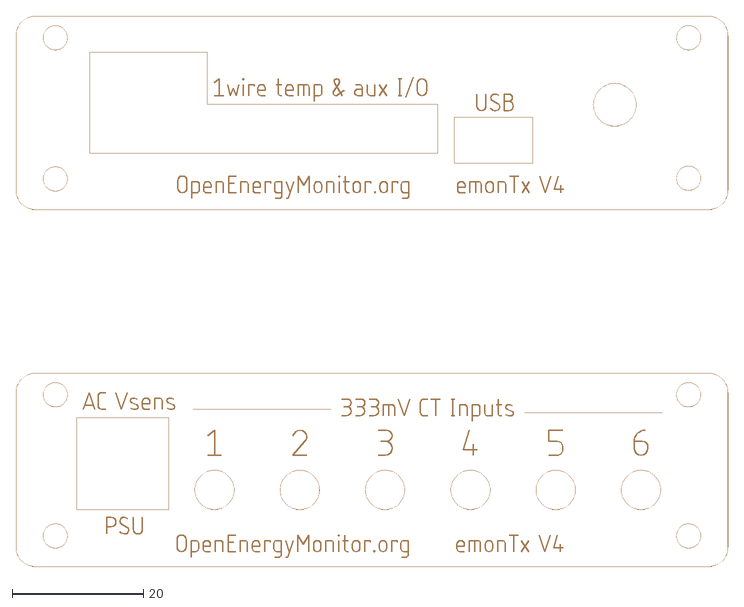
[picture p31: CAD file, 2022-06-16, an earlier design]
hardware/fascia/archive/V0.2-fascia-emontxv4.dxf
108.5 x 83.9

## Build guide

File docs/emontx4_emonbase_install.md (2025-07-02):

---
github_url: "https://github.com/openenergymonitor/emontx4/blob/main/docs/emontx4_emonbase_install.md"
---

# emonTx4, emonVs & emonBase Install Guide

The following guide covers installation of the [emonTx4 6x input energy monitor](overview.md) in combination with an [emonBase (RaspberryPi base-station)](../emonbase/rfm69-spi.md). Using an emonTx4 with an emonBase provides full local emoncms data logging and visualisation capabilities as well as the option to expand data input from other devices.

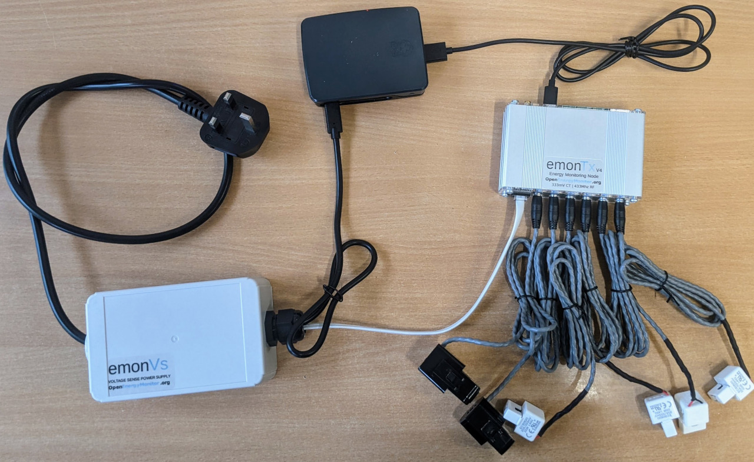
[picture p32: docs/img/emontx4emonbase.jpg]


**Hardware covered in this guide:**

- [emonTx4: 6 input energy monitor](overview.md)
- [emonVs: Precision voltage sensor and power supply](voltage_sensors.md)
- [emonBase: RaspberryPi base-station](../emonbase/rfm69-spi.md)
- Up to 6 CT sensors
- RJ11 voltage sensor cable

**If you already have an emonPi or emonBase** you can use this rather than needing to buy a new emonBase. The terms emonPi/emonBase can be used interchangeably in this guide. Please see the [Adding to an existing install guide](emontx4_emonpi_install.md).

## Quick Start

1. Clip the CT current sensors around Live OR Neutral cable of the AC circuit to be measured (not both), note CT direction K -> L (L: Load), That’s on the Line conductor, the arrow points
away from the load on the Neutral.

2. Plug the CT current sensors into emonTx4 via 3.5mm jack plugs

3. Plug emonVs RJ11 cable into emonTx4

4. Plug emonVs USB-C cable into emonBase Raspberry Pi base-station power input connector

5. Plug emonVs into mains power via a domestic wall socket

6. (optionally) connect emonBase Raspberry Pi base-station to Ethernet

7. Switch on mains socket and verify that the red LED on the emonTx4 and the red LED on the Raspberry Pi illuminates.

8. Continue with step 5. emonBase Setup below.

```{admonition} Instructions for safe use
- Clip-on CT sensors are non-invasive and should not have direct contact with the AC mains. As a precaution, we recommend ensuring all cables are fully isolated prior to installing. If in doubt seek professional assistance.
- Do not expose to water or moisture
- Do not expose to temperate above rated operating limits
- Indoor use only
- Do not connect unapproved accessories
- Please contact us if you have any questions
```

## Extended version

A good place to start is to assess the location where you wish to install the emonTx4, identify the circuits that you wish to monitor using the clip-on CT sensors and decide how you would like to install the emonVs voltage sensor. There are a couple of example installations given below which may provide inspiration.

## 1. emonVs installation

There are two different ways of installing the emonVs voltage sensor:

**Using the mains plug supplied:** If you have a convenient socket near-by this will be the easiest and quickest option.<br>

**Direct installation:** The emonVs can be hardwired by a suitably competent person into a 6A or lower circuit protection device in the fuse board (consumer unit) or a 3A fused spur. The supplied emonVs mains power cable has a cross sectional area of 1.0mm<sup>2</sup>. This can provide a tidy installation if no socket is available and helps ensure higher monitoring uptime if sockets are at risk of being unplugged for use by other appliances.

The emonVs unit can be wall mounted using the brackets on the enclosure. Start by marking the position of the holes and then, with the emonVs removed, screw in the screw for the bracket below the larger gland first. Slide the emonVs into place before inserting the second screw near the low profile gland used for the power cable.

## 2. CT sensor installation

- Current transformers (CTs) are sensors that measure alternating current (AC).

- The emonTx4 supports a wide variety of 333mV voltage output CT sensors. We stock 20A, 50A, 100A & 200A options in the OpenEnergyMonitor shop. The physical size of these CT sensors is also roughly proportional to their current rating. For highest accuracy it's a good idea to choose CT sensors that match the rating of the circuit being monitored. As an example a 20A CT should be used for 16A or 20A circuits, a 50A CT for 32A EV chargers or 100A CT for whole house monitoring (assuming a 100A rated supply).

- CT sensors need to be clipped around the Live OR Neutral cable of the AC circuit to be measured (not both). The CT sensors have an indicated direction printed on the case `K->L`, where L is the direction of the load. That’s on the Line conductor, the arrow points away from the load on the Neutral. This will ensure the correct sign (+/-) on the power readings.

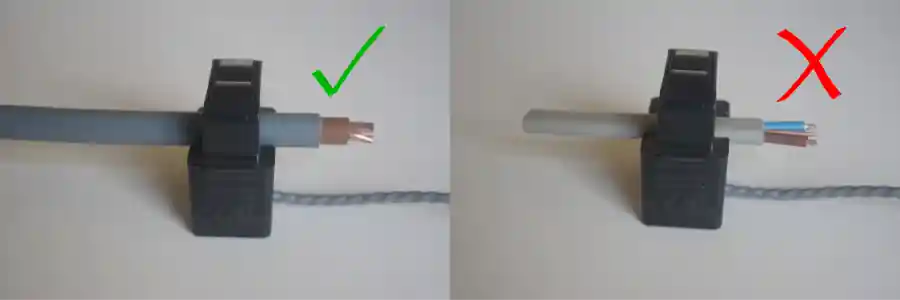
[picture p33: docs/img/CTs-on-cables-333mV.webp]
CTs on cables


- Take care not to compress the sensor with any sideways force as this can affect the accuracy of the measurement.

- The new range of CT sensors used with the emonTx4 are all voltage output CT sensors with integrated burden resistors and so are safe to clip on to the circuits that you wish to measure before plugging into the emonTx4 if that makes installation easier.

- Note the CT sensor used on each circuit, as well as the channel number on the emonTx4 that the CT is connected to, as this may be required to calibrate the emonTx4 if you are using non standard CT ratings. It's worth making a physical note of this on a label next to the emonTx4 for future reference.

```{note}
The emonTx4 requires voltage output CT sensors, it is not compatible with the old current output YHDC (blue) 100A CT sensors - unless appropriate burden resistors are installed.
```

```{tip} 
With 6 CT sensor cables and often more cable than you need it's easy for an installation to look like a hive of wires! A little electrical trunking can go a long way to tidying it all up, allowing for excess cable to be looped back on itself.
```

## 3. emonTx4 Installation

- The emonTx4 can be wall mounted using the wall mounting kit supplied. A vertical orientation can help reduce risk of things falling onto the sockets and can make for an easier installation in terms of CT sensor routing. See installation example images below.

- Connect the RJ11 cable (telephone sized connector with 6 pins) from the emonVs voltage sensor to the RJ11 socket which is on the same side as the CT sensor sockets. (The larger RJ45 socket on the other side is for temperature and pulse counting, take care not to plug the RJ11 plug into the RJ45 socket).

- Plug in the CT sensors, note which CT sensor is plugged into each input on the emonTx4 as each input needs to have the correct calibration applied.

- This is a good point to calibrate the emonTx4 with the correct configuration to match the CT sensors connected. There are a couple of different ways of doing this, the easiest is to use our browser based web-serial configuration tool supported by Chrome, Edge and Opera browsers.

```{note}
Unless otherwise selected in the shop, the emonTx4 is pre-calibrated with the following default CT ratings:

- Channel 1: 100A
- Channel 2: 50A
- Channel 3: 50A
- Channel 4: 20A 
- Channel 5: 20A 
- Channel 6: 20A

```

**Browser based configuration tool**
- Connect the emonTx4 to your computer using a USB-C cable,
- Open the web-serial configuration tool [https://openenergymonitor.org/serial](https://openenergymonitor.org/serial) (Browser must be Chrome, Edge or Opera). Firefox and Safari do not currently support the web-serial technology used by this tool.
- Click on 'Connect' and select the emonTx4 serial port in the pop up menu. It should be listed as 'CP2102N USB to UART Bridge Controller..'
- After a couple of seconds the emonTx4 will print out its current configuration which will populate the interface.
- Adjust the  CT rating to match the CT sensor that you have installed on each channel.
- Click on 'Save Changes' to ensure that the new configuration is recorded such that it persists when you power cycle the board.

```{note} 
The USB-C connection on the emonTx4 only works in one orientation for data transfer (usually smooth face up). If the config tool doesn't connect then invert the orientation of the plug.
```

## 4. emonBase Installation

- Depending on the installation it may make sense to install the emonBase next to the emonTx4 or further away, perhaps near the internet router for Ethernet connectivity.
- The emonBase can receive data from the emonTx4 either via 433 MHz radio or if near by via wired USB connection.
- If near by, the emonBase can be powered by the emonVs USB-C cable.
- Alternatively a separate USB-C power supply will be required if located elsewhere.
- Before powering up the emonBase, you may want to enable SSH and pre-configure your WiFi details on the SD card first. See [emonSD: before bootup SSH & WiFi configuration](../emonsd/download.md).

## 5. emonBase setup

- **If the emonBase is powered up without Ethernet connected it will create a Wi-Fi Access Point** called `emonPi`. Connect to this using password `emonpi2016`. Browse the IP address [http://192.168.42.1](http://192.168.42.1) and follow the setup wizard to connect the device to your local Wi-Fi network.
- **Once connected via Wi-Fi or Ethernet** the base-station can be accessed via [http://emonpi](http://emonpi) or [http://emonpi.local](http://emonpi.local). If you are unable to locate the emonBase via this hostname, try using a network scanner app such as ['Fing'](https://play.google.com/store/apps/details?id=com.overlook.android.fing&hl=en_GB&gl=US) or ['Network Analyser'](https://play.google.com/store/apps/details?id=net.techet.netanalyzerlite.an&hl=en_GB&gl=US) to list the IP addresses of devices on your network or check the device list on your router.
- **The emonBase should now present the emoncms login screen.** Create a local account, save the password and login.
- **Configure inputs by navigating to Setup > Inputs.** The emonTx4 will pop up here automatically under the emonTx4_xx node name. If you have connected the emonTx4 to the emonBase directly via USB it will appear twice, first under the emonTx4_xx node name corresponding to data received over radio and second under the 'emonTx4' node name corresponding to data received directly over USB. You may wish to disable the radio link at this point.

```{note} 
The USB-C connection on the emonTx4 only works in one orientation for data transfer (usually smooth face up), if you are not receiving data then invert the orientation of the plug.
```

```{tip} 
**The emonTx4 radio can be disabled if using USB:** on the emonBase local Emoncms webpage navigate to Admin > Serial Config to bring up the emonTx4 serial configuration interface. This version runs locally on the emonBase and is compatible with all browsers. Click on 'Stop EmonHub' and then click on 'Start' for the serial connection above it. If you are running emonTx4 firmware released after the 14th of May 2024 the radio can be turned on and off via the serial configuration UI. Alternatively for older firmware type 'w0' in the console entry box and click 'Send'. You should see 'RF = off' printed in the console log window below. Next enter the character 's' for save in the console entry box and click 'Send' again. This will save and persist this setting. You can at this point use the serial configuration interface to adjust CT calibration if needed as well, you may wish to upgrade the firmware to enable the full configuration interface. Once complete click on 'Stop Serial' and then 'Start EmonHub' again. Navigate back to Setup > Inputs, after about 20s the USB inputs should resume.
```
- **The next step is to log the input data to feeds.** Inputs are just placeholders showing the latest values sent from the emonTx4, we need to create feeds if we want to record a time-series of these values. It’s possible to either manually configure each input as required, or if you just want to record everything for now and delete what you don’t need later, then you can use the pre-configured Device Template.

    **Tip: Input configuration using the emonTx4 device template:** On the Setup > Inputs page, Click on the cog icon (top right corner) of the emonTx4 node. The 'Configure Device' window will appear, click on 'emonTx4 Standard', you may need to scroll down a little in the Devices pane to find. Click 'Save' and 'Initialize'. This will create feeds that record real power and cumulative energy for each channel, Vrms, total message count, temperatures and total pulse count. Navigate to Setup > Feeds to see these feeds.

    **Manual input configuration:** You may only want to record specific channels or apply more complex input processing. See input processing guide.

- **With feeds created, explore the data using the graph view.** Navigate to Setup > Feeds and click on a feed of interest to open the graph view. Click on the drop down time selector near the title and select the last hour. Click and drag to zoom further to see the new data coming in.

- **Try creating an Emoncms App.** Click on the Apps tab. From the Available Apps list select 'My Electric' and click 'Create', Select a power feed for 'use' and cumulative kWh energy feed for 'use_kwh' and then click 'Launch App'. After a few days this will start to show a daily bar graph of consumption alongside the real-time power graph and totals. There are a wide variety of different app's to choose from depending on the application.

## Installation Examples

**Installation example 1**<br>
In this installation example the emonVs has been hardwired into a suitable circuit breaker in the consumer unit. 5 CT sensors are clipped around individual circuits in the consumer unit and 1 CT sensor is clipped around the main supply to the house. The emonBase is located separately in the living room and receives data from the emonTx4 via 433 MHz radio. A short strip of trunking here made all the difference for a neater finish!

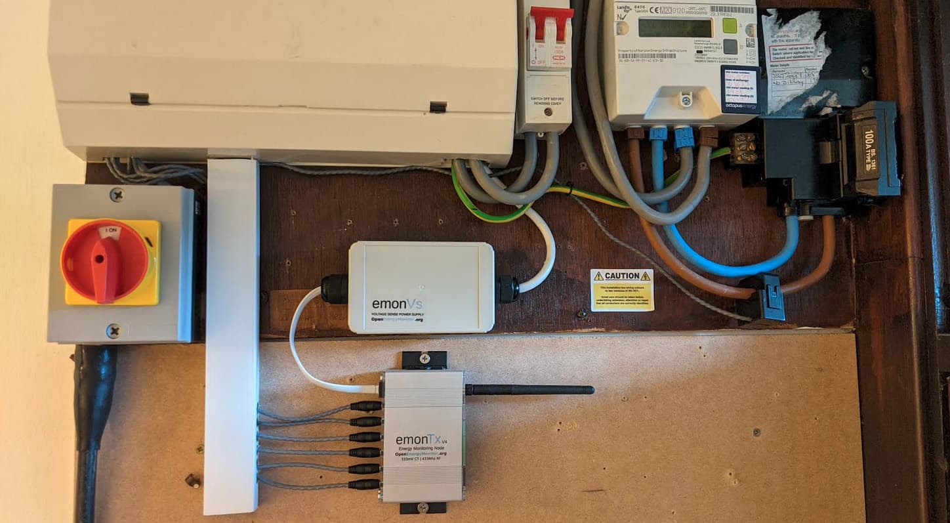
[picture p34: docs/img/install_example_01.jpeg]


**Installation example 2**<br>
In this installation the emonBase is located next to the emonVs and emonTx4. Both the emonTx4 and the emonBase are powered by the emonVs. The CT cables are routed through the trunking to the consumer unit where they are clipped around the individual circuits that are being monitored.

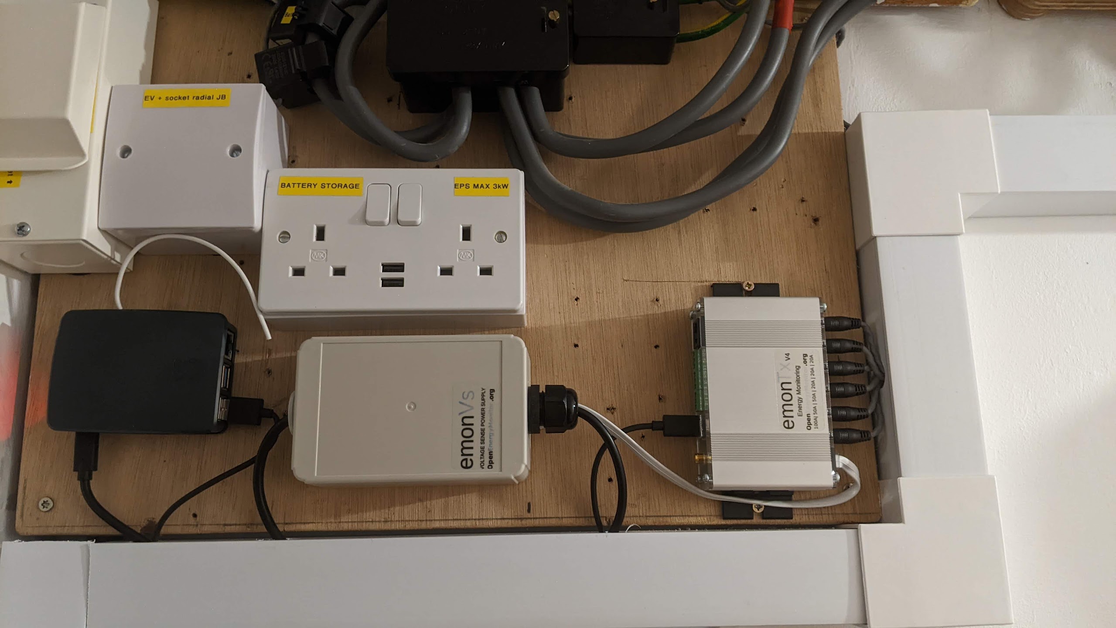
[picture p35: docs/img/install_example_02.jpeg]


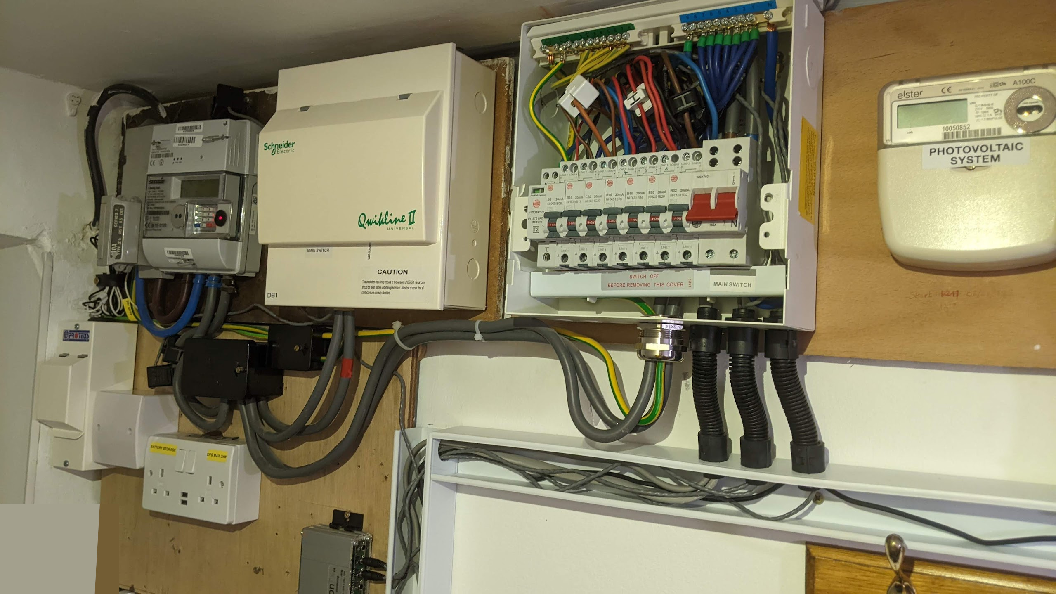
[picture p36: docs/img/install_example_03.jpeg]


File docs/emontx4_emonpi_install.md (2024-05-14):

---
github_url: "https://github.com/openenergymonitor/emontx4/blob/main/docs/emontx4_emonpi_install.md"
---

# Adding an emonTx4 to an existing installation

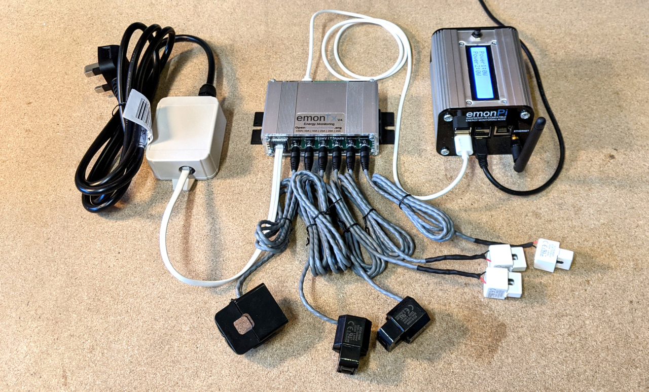
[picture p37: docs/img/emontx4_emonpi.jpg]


There are two ways to add an emonTx4 to an existing emonPi or emonBase installation:

1. Direct USB data connection
2. 433MHz radio data connection

---

## Direct USB data connection

The emonTx4 can be connected to an existing emonPi via a USB-C to USB-A cable (as shown in the example picture above), measurement data can be transferred over USB. This provides a simple and reliable setup.

**Tip:** For a lower cost single-phase configuration the emonTx4 can be powered from the emonPi over the same USB connection. The emonTx4 can then use the emonVs-mini pictured above (voltage sensor only) rather than the full emonVs-psu (voltage sensor with integrated power supply).

**Configuration**<br>The main thing we need to do here is tell a piece of software on the emonPi called emonHub to read from the USB serial port. 

1. Login to your local emonPi Emoncms account and navigate to Setup > EmonHub > Edit Config.

2. Under the `[interfacers]` section add the following interfacer config:

```
[[USB]]
    Type = EmonHubOEMInterfacer
    [[[init_settings]]]
        com_port = /dev/ttyUSB0
        com_baud = 115200
    [[[runtimesettings]]]
        pubchannels = ToEmonCMS,
        nodename = emonTx4
```

*If you have a relative new emonSD image, this interfacer configuration will already be populated*.

With that in place you should now see the emonTx4 inputs appear in your Emoncms inputs list.

**It is advisable to make sure that you are running the latest version of the emonHub software** as it has a couple of improvements to make sure that the USB serial connection recovers automatically after a failure such as unplugging and plugging back in the USB cable.

**If you have multiple USB ports in use** there is a risk that a device on /dev/ttyUSB0 might swap around with another on /dev/ttyUSB1. It's possible to reference the serial port by-id for a more robust solution:

    ls /dev/serial/by-id/*
    
example response:

    /dev/serial/by-id/usb-Silicon_Labs_CP2102N_USB_to_UART_Bridge_Controller_589399f65987ec118b30e33719c2d21c-if00-port0

Modify the emonhub.conf entry with the full path e.g:

    [[[init_settings]]]
        com_port = /dev/serial/by-id/usb-Silicon_Labs_CP2102N_USB_to_UART_Bridge_Controller_589399f65987ec118b30e33719c2d21c-if00-port0

---

## 433MHz radio data connection

Data can be transferred between the emonTx4 and emonPi via 433MHz radio. 

**A key thing to watch out for here** is that the default radio packet format for the latest emonTx4 is based on the **LowPowerLabs RFM69** code which is **not compatible** with an emonPi running the original JeeLib 'classic' code.

It is however easy to **change a new emonTx4 to transmit using the original JeeLib classic format** so that compatibility is maintained.

Alternatively it is possible up upgrade the firmware on an existing emonPi system to use the LowPowerLabs RFM69 radio format which offers hardware encryption and a packet acknowledgment/retry mechanism to minimize packet loss. LowPowerLabs firmware is also available for existing emonBase systems. Both are upgradable via the local Emoncms > Admin > Firmware update tool.

### 1. Shop option at time of purchase

It's possible to select the firmware version in the shop when buying an emonTx4:



**Standard:** LowPowerLabs radio format. **Existing hardware compatibility:** JeeLib classic format.

**Continue to EmonHub Configuration below.**

### 2. Using an emonPi to update/change the emonTx4 firmware

The easiest way of updating or changing the emonTx4 firmware is to connect it to an emonPi or emonBase with a USB cable and then use the firmware upload tool available at Setup > Admin > Update > Firmware.

**Select** the emonTx4 USB port, usually **ttyUSB0**. Select **emonTx4** hardware and then for existing hardware compatibility, select **RFM69 JeeLib Classic** in the Radio format drop down. Click Update Firmware to upload.



**Continue to EmonHub Configuration below.**

### 3. Manual firmware compile and upload

It is also possible to compile and upload the firmware with the radio format option set as desired, manually.

Start by following the [EmonTx4: How to compile and upload firmware](firmware.md) guide on the Firmware page.

At the top of the EmonTx4 firmware you will see the option to define the RadioFormat:

```
// 2. Set radio format
// Options: RFM69_JEELIB_CLASSIC, RFM69_JEELIB_NATIVE, RFM69_LOW_POWER_LABS
#define RFM69_LOW_POWER_LABS
```

For existing system compatibility change to:

    #define RFM69_JEELIB_CLASSIC

**Continue to EmonHub Configuration:**

## EmonHub Configuration

To receive the emonTx4 data on your existing emonPi/emonBase there is one last step and that is to add a node decoder configuration to emonhub. 

On your emonPi/emonBase navigate to Setup > EmonHub > Edit Config. Scroll down to the bottom of the config file and add the following emonTx4 configuration:

```
[[17]]
    nodename = emonTx4_17
    [[[rx]]]
        names = MSG, Vrms, P1, P2, P3, P4, P5, P6, E1, E2, E3, E4, E5, E6, T1, T2, T3, pulse
        datacodes = L, h, h, h, h, h, h, h, l, l, l, l, l, l, h, h, h, L
        scales = 1.0, 0.01, 1.0, 1.0, 1.0, 1.0, 1.0, 1.0, 1.0, 1.0, 1.0, 1.0, 1.0, 1.0, 0.01, 0.01, 0.01, 1.0
        units = n, V, W, W, W, W, W, W, Wh, Wh, Wh, Wh, Wh, Wh, C, C, C, p
```

Alternatively if you have an up-to-date emonhub installation you can try our new  `autoconf` feature. Add `autoconf = 1` just under the `[hub]` heading at the top. E.g:

```
[hub]
    loglevel = DEBUG
    autoconf = 1
```

The emonTx4 node should now automatically be detected and appear in the emoncms inputs list.

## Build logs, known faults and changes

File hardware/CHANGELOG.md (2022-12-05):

# Change log 

V4.0.3

- Use normally connected jumpers for JP2-6
- Add part referances to silkscreen
- Minor silkscreen tweaks 

V4.0.4

- Move to new mid-rail bias design
- GND one side of CT to reduce noise 
- Move voltage bias circuit onto emonVS

V4.0.5

- Route 5V to UART connector

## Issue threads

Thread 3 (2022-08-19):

EmonLibCM is configured for a maximum of 5 current channels

brandon3055, 2022-08-19:
Just a heads up. I spent a while trying to figure out why manually compiling would result in wired, broken behaviour.
Turns out this was why.
https://github.com/openenergymonitor/EmonLibCM/blob/avrdb/emonLibCM.cpp#L78
My guess is whoever built the firmware changed this to 6 but then forgot to commit that change.

glynhudson, 2022-08-19:
Correct, the changes required for emonTx V4 have not yet been pushed. @TrystanLea is working on this and will commit when ready

brandon3055, 2022-08-20:
Do you know if it would be at all possible to get my hands on a pre-release version? It turns out the avrdb branch is a lot more broken than I thought and I have not been able to figure out what's wrong.

Failing that is there any way to configure ical values via serial with the current pre-compiled firmware?

TrystanLea, 2022-08-20:
I've just pushed up the latest version supporting all 6 channels

brandon3055, 2022-08-20:
Ok so i was confsued there for a minute because that's pretty much what I already tried. Turns out the power monitoring is actually working as expected but the current values returned by `EmonLibCM_getIrms(EmonLibCM_getLogicalChannel(x))` are broken.

Closed 2022-08-19.

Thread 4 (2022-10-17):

Will it be possible to use the RFM69 in packet mode with the expansion module?

brandon3055, 2022-10-17:
Good Afternoon.

I have been experimenting with adding an expansion module to my DIY emontx4. But I quickly discovered that the existing rfm_send function
https://github.com/openenergymonitor/emontx4/blob/main/firmware/EmonTxV4CM/EmonTxV4CM_rfm.ino#L122
has a maximum payload size of 56 bytes which is far exceeded when trying to expand to 12 channels.

I would just like to know if this is something that can be fixed. or do I need to switch to the RFM69 native format if I want 12 channels?

TrystanLea, 2022-10-17:
Hello @brandon3055 yes both have the limit as you observe and the 12 channels would need to be split. Robert Wall is developing new firmware for the emonTx4 from scratch to try to cater for the wider set of requirements, both single and 3 phase, plus up to 12 channels, it's likely to be available further down the line. Id be interested to hear how you get on expanding to 12 channels with the existing firmware though!

brandon3055, 2022-10-19:
Success!
The config system has been expanded to support the additional channels, And the extension module can be enabled/disabled,
The amount of repetition in the code was kinda bothering me, especially when expanding to 12 channels. So reconfigured everything to be loop-based.
This also includes support for a second pulse input.

https://github.com/brandon3055/emontx4/blob/main/firmware/EmonTxV4CM/EmonTxV4CM.ino
https://github.com/brandon3055/emontx4/blob/main/firmware/EmonTxV4CM/EmonTxV4CM_config.ino
https://github.com/brandon3055/emontx4/commit/f8f613d936be07e554262718c11c5dce8c279699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

I spent way too long trying to figure out how I broke the calibration command only to discover that EmonLib's EmonLibCM_ReCalibrate_IChannel simply does not work correctly when using this many channels.
I guess that would explain why parts of the config were disabled.
https://github.com/openenergymonitor/emontx4/blob/main/firmware/EmonTxV4CM/EmonTxV4CM.ino#L158
Fortunately, calibration still works. It just takes a reboot to load the new values.

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

I do have one question. It relates to my post on the forum. https://community.openenergymonitor.org/t/avr-db-emontx-v4-new-hardware-in-progress/20209/171
I based my extension board on the old circuit because I mistakenly assumed that was a new/improved design.
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
Is noise enough of an issue that I should consider switching to the new design? Or will it *most likely* be fine?

TrystanLea, 2022-10-21:
Great to see the above @brandon3055, impressive! and I like the 3d printed fascia.

Did you see my commit here relating to EmonLibCM_ReCalibrate_IChannel? I had not mapped these correctly
https://github.com/openenergymonitor/emontx4/commit/bf63ca445ae41dbc8eeec04f2fcf8a977ab8df0e

Nice work with the loop based approach!

Is saving to EEPROM working for you?

Regarding noise, how do your zero current readings compare between the two types? Do you notice any difference if the CT is clipped around the wire (with no load) or on the work bench? The difference may not be significant enough to make it worthwhile your effort to change?

brandon3055, 2022-10-22:
> Did you see my commit here relating to EmonLibCM_ReCalibrate_IChannel? I had not mapped these correctly
https://github.com/openenergymonitor/emontx4/commit/bf63ca445ae41dbc8eeec04f2fcf8a977ab8df0e

Ahh! I wondered if it might be that. Good to know!

Saving to EEPROM works fine. The only thing stopping it from working in the existing firmware is the fact that `load_config(true); ` and `readConfigInput();` are commented out. But i suspected that was because of the calibration issue which it seems you have now solved in the rfn69n version.

As far as noise. I'm not sure how i missed it before but i do see current readings fluctuating between around 20 and 400ma.
So yea. I guess i will just have to add the new board to my next jlcpcb order.

TrystanLea, 2022-10-23:
Great thanks, happy to send you the CT extender PCB, I have a few spare. If that's useful feel free to send me a PM via the forum. It's great having your input testing this!

TrystanLea, 2022-10-23:
Got the EEPROM to work here. I had to make the following changes to the emonEProm library to get it to work. Is there a chance it wasn't actually saving for you?

https://github.com/openenergymonitor/emonEProm/commit/ce8aa27c71e6b0107b723035fc1fc3f1642344ff

I've also put together a little web-serial tool to make configuration easier, this is going to be nice! :)
 https://openenergymonitor.org/serial/

It requires a web-serial compatible browser e.g Chrome

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

brandon3055, 2022-10-23:
>Great thanks, happy to send you the CT extender PCB, I have a few spare (all partially assembled). If that's useful feel free to send me a PM via the forum. It's great having your input testing this!

It's all good. I have already ordered new boards. It's so nice being able to just order 5 professionally made PCBs for like $10 delivered!

Once those and my extra CTs arrive I can do more testing. When prototyping you never order just enough components for one board so I ended up building a second monitor for a friend and a third just to play with.
I decided to include the expansion module so he would have the option to expand once the 12CT firmware was available.
But it seems I lack the ability to leave something unfinished so here we are xD

>Got the EEPROM to work here. I had to make the following changes to the emonEProm library to get it to work. Is there a chance it wasn't actually saving for you?

Dont know what to tell you. Its definitely working for me without those chances. All I had to do was uncomment the load_config line.  My firmware is based on the old `EmonTxV4CM` not the new `EmonTxV4CM_rfm69n` firmware if that makes any difference.

The config for my [emonMicro](https://github.com/brandon3055/emonMicro) is based on the same code and I didn't notice any issues with those either.

>I've also put together a little web-serial tool to make configuration easier, this is going to be nice! :)

That looks nice! I can't wait to test it out!
Though that reminds me. I noticed you changed the default lead from 1.5 to 3.2. But as far as I could tell the power factor readings were already pretty much perfect. Usually around 0.999~ for a resistive load.

TrystanLea, 2022-10-23:
> Dont know what to tell you. Its definitely working for me without those chances

How strange, I was getting all sorts of issues due to an E2END not being anything like the right value. The EEPROM format would then just clear the signature with the overflow..

Might be interesting to check what the value of E2END is on your system? Perhaps we are running different versions of DxCore or something..

> I noticed you changed the default lead from 1.5 to 3.2. But as far as I could tell the power factor readings were already pretty much perfect.

The phase calibration only becomes noticeable on loads with large phase differences between voltage and current. The power supply on my heat pump controller board is a good example or connecting up one of these unloaded: https://www.screwfix.com/p/carroll-meynell-3000va-intermittent-isolation-transformer-230v-230v/320hv

> Sending commands does not seem to work though I suspect that's just because it's a WIP

It should work, it's working here for me on Chrome.. can you see anything in the serial window? is it loading the config values from the emontx into the input boxes?

> I notice there is no way to fine-tune the calibration. Is that planned? or is calibration not an issue with the CTs you use?

Im sure it will be something people will want, though I expect most will use the standard values. Il probably do a custom entry in the dropdown that then provides a input box..

brandon3055, 2022-10-23:
On my system `Serial.println(E2END);` returns 5631. I'm pretty sure that's not correct...

It seems the console does work. Bit it does not let you send +++ to enter config mode.

brandon3055, 2022-10-23:
Oh... I know config works.... EmonTxV4CM does not use emonEProm. It just writes a config struct using the arduino EEPROM lib.
EmonTxV4CM_rfm69n uses emonEProm.

TrystanLea, 2022-10-24:
Aha, ok that's useful to know. Are you staying on EmonTxV4CM for compatibility with existing devices?

TrystanLea, 2022-10-24:
> On my system Serial.println(E2END); returns 5631. I'm pretty sure that's not correct...

Thanks I get the same here.

TrystanLea, 2022-10-24:
E2END return 1023 for the ATmega328

It's defined for the avr128db48 in the file:
packages/DxCore/tools/avr-gcc/7.3.0-atmel3.6.1-azduino4b/avr/include/avr/ioavr128db48.h

#define EEPROM_END       (EEPROM_START + EEPROM_SIZE - 1)
#define E2END        EEPROM_END

though EEPROM_START and EEPROM_SIZE definitions above it seem to be commented out...

brandon3055, 2022-11-27:
Sorry, it took me a while to get back to this.

I have done some testing with the new board and I am still noticing some odd behaviour.  But only on channel 12.
With no load, I was randomly seeing currents as high as 300ma on channel 12.

So I did some more testing. Due to the new board no longer pulling the CT pin to the ground when a CT is disconnected. You can remove a CT and the channel will remain active. The result should be the same as having a CT connected with no load. But also no chance of interference. Turns out I still see the random 100-300ma readings even with no CT connected to channel 12. Or any channel for that matter.

It actually seems the interference is somehow coming from the v-sense board because disconnecting that and running on USB only completely stops the random readings.

These are some of my readings.
Vsense connected, no CTs connected (This matches what I see with all CTs connected)
[https://ss.brandon3055.com/3b549](https://ss.brandon3055.com/3b549)
Running without Vsense connected (Though I did connect it near the end)
[https://ss.brandon3055.com/b9509](https://ss.brandon3055.com/b9509)
And this is with all CTs connected, running on USB power, with a load test halfway though.
It works perfectly except for the fact that it's not using the vsense board.
[https://ss.brandon3055.com/5e016](https://ss.brandon3055.com/5e016)

I don't really have time to continue digging into this right now but I thought I would let you know what I found.
Its possible this is an issue with the changes I made to get 12 channels working. And I have not had a chance to
go through the changes you have made. It could also be an issue with my board. The soldering on the AVR128 is far from my best work. though the input pin for CT12 is nowhere near the VSense inputs.

The other thing that is obvious from my readings is every channel has a 15ma offset. Though I think this is easy to explain.  My one relatively cheap meter that can read 3.3 volts with three digits of precision shows that my VCC is 3.306v
If my math is correct a VCC of 3.307v would result in a 15ma offset. (With my Ical being 90.495)

TrystanLea, 2022-11-28:
Thanks @brandon3055

Does reducing the sample rate perhaps:

ADC0.CTRLC = ADC_PRESC_DIV32_gc;

or

ADC0.CTRLC = ADC_PRESC_DIV64_gc;

make any difference? adusting timing in the EmonLibCM_setADC(12,29.5); appropriately

do you have one-wire temperature sensing enabled? what happens if you turn that off?

brandon3055, 2022-11-29:
Disabling temperature had no noticeable effect.
DIV 32 with temperature enabled had no noticeable effect.
DIV 32 with temperature disabled had no noticeable effect.
DIV 64 with temperature enabled seems to have resolved the issue.

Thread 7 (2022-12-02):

Fuses and bootloader

damiano94, 2022-12-02:
Hi,
I didn't found this information in documentation, what are values of fuse bits? And what boot loader is used, opti boot?

Side question, when can we expect 3phase firmware? I don't have 3 phase devices, only single phase devices on different phases, do I really need new firmware or can I just measure power on every phase and add it together to get total consumption?

Adminius, 2024-05-08:
@damiano94 did you found it out?

TrystanLea, 2024-05-31:
Hello @damiano94 did you see the new firmware, latest available here https://github.com/openenergymonitor/avrdb_firmware/
1-phase, 3-phase, 6CT & 12CT variants, common base firmware for emonTx4, emonTx5 and emonPi2.
Cheers!

Closed 2024-05-31.

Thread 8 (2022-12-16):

The showCurrents option displays wrong values

eax64, 2022-12-16:
Hi,
The currents and power factors on my emontx4 didn't seem to make sense.

Looking at the code (in `EmonTxV4.ino`), there seems to have been a mistake:
```cpp
Serial.print(F(",I1:")); Serial.print(EmonLibCM_getIrms(EmonLibCM_getLogicalChannel(1)),3);
[...]
Serial.print(F(",I6:")); Serial.print(EmonLibCM_getIrms(EmonLibCM_getLogicalChannel(6)),3);

Serial.print(F(",pf1:")); Serial.print(EmonLibCM_getPF(EmonLibCM_getLogicalChannel(1)),4);
[...]
Serial.print(F(",pf6:")); Serial.println(EmonLibCM_getPF(EmonLibCM_getLogicalChannel(6)),4);
```

I think it should be:
```cpp
Serial.print(F(",I1:")); Serial.print(EmonLibCM_getIrms(0),3);
[...]
Serial.print(F(",I6:")); Serial.print(EmonLibCM_getIrms(5),3);

Serial.print(F(",pf1:")); Serial.print(EmonLibCM_getPF(0),4);
[...]
Serial.print(F(",pf6:")); Serial.println(EmonLibCM_getPF(5),4);
```
Readings before the change:
```
MSG:24,Vrms:244.50,P1:381,P2:-18,P3:27,P4:136,P5:52,P6:79,E1:37925,E2:4657,E3:14021,E4:8776,E5:6637,E6:4936,pulse:0,I1:1.961,I2:1.961,I3:1.961,I4:0.310,I5:0.370,I6:0.723,pf1:0.7938,pf2:0.7938,pf3:0.7938,pf4:-0.2564,pf5:0.2999,pf6:0.7668
MSG:25,Vrms:244.35,P1:385,P2:-18,P3:30,P4:135,P5:54,P6:79,E1:37926,E2:4657,E3:14021,E4:8776,E5:6637,E6:4937,pulse:0,I1:1.981,I2:1.981,I3:1.981,I4:0.309,I5:0.377,I6:0.723,pf1:0.7956,pf2:0.7956,pf3:0.7956,pf4:-0.2553,pf5:0.3226,pf6:0.7661
MSG:26,Vrms:244.55,P1:382,P2:-18,P3:30,P4:135,P5:51,P6:79,E1:37927,E2:4657,E3:14021,E4:8777,E5:6637,E6:4937,pulse:0,I1:1.967,I2:1.967,I3:1.967,I4:0.310,I5:0.378,I6:0.723,pf1:0.7933,pf2:0.7933,pf3:0.7933,pf4:-0.2565,pf5:0.3206,pf6:0.7657
```

Readings after the change:
```
MSG:13,Vrms:243.22,P1:384,P2:-18,P3:28,P4:132,P5:71,P6:68,E1:37913,E2:4658,E3:14021,E4:8772,E5:6635,E6:4934,pulse:0,I1:2.045,I2:0.307,I3:0.547,I4:0.713,I5:0.459,I6:0.292,pf1:0.7720,pf2:-0.2579,pf3:0.2136,pf4:0.7604,pf5:0.6378,pf6:0.9546
MSG:14,Vrms:243.90,P1:389,P2:-18,P3:28,P4:136,P5:72,P6:68,E1:37915,E2:4658,E3:14021,E4:8772,E5:6635,E6:4934,pulse:0,I1:2.060,I2:0.310,I3:0.542,I4:0.727,I5:0.462,I6:0.292,pf1:0.7748,pf2:-0.2554,pf3:0.2150,pf4:0.7652,pf5:0.6430,pf6:0.9550
MSG:15,Vrms:244.52,P1:393,P2:-18,P3:28,P4:140,P5:71,P6:68,E1:37916,E2:4658,E3:14021,E4:8773,E5:6635,E6:4934,pulse:0,I1:2.047,I2:0.311,I3:0.464,I4:0.741,I5:0.457,I6:0.293,pf1:0.7850,pf2:-0.2523,pf3:0.2484,pf4:0.7723,pf5:0.6390,pf6:0.9550
```

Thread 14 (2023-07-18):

Pi Pico W Expansion Board: Basic Emon CMS Client API Call

VincentSaelzler, 2023-07-18:
Is this line just a sample/placeholder, or is it actually supposed to send valid requests to Emon CMS?
```
req = "https://emoncms.org/input/post?apikey=apikey&node=emontx4pico&data="+data
```
[Link to File](https://github.com/openenergymonitor/emontx4/blob/main/expansion_boards/PiPico/examples/micropython/basic_emoncms_client.py)

I am asking because it seems to send back a 200 response with the content being `ok` regardless of whether I send  the correct or incorrect API key.

I am working on a more robust micropython client, and have gotten to the point of actually making the API call to Emon CMS.

```py
from machine import UART, Pin
from time import sleep

# UART configuration ---------------------------------------------------------
# default timeout for uart.any() to decide if a new line is coming is 0 (ms).
# increase to 1 (ms) to give emon time to send the next line.
# sending output to uart1 is optional - for debugging
# required to debug because if the micro-usb cable is plugged to pico
# the power cannot simultaneously be connected to emon (3.3V vs 5V)

uart0 = UART(0, timeout=1) # pins GP0/GP1
uart1 = UART(1)  # pins GP4/GP5

def blink_led(times_to_blink):
    # assumptions
    led = Pin('LED', Pin.OUT)
    a_brief_moment = .1
    # start with the led off
    led.value(0)
    for _ in range(times_to_blink):
        # turn on and wait
        led.toggle()
        sleep(a_brief_moment)
        # turn back off and wait
        led.toggle()
        sleep(a_brief_moment)

def process_line():
    line = read_line()
    trimmed_line = line.strip()

    # for now just write output to console and outgoing uart
    uart1.write(line)
    print(trimmed_line)

    # trimmed line looks something like:
    # MSG:540,Vrms:240.00,P1:2,P2:6,P3:6,P4:5,P5:5,P6:4,E1:3,E2:10,E3:10,E4:8,E5:8,E6:7,pulse:0
    # TODO: Make a correct API call

def read_line():
    try:
        # get input until a newline character is reached (or the uart's configured timeout_char expires)
        incoming_line = uart0.readline()

        if incoming_line is None:
            # blink thrice to signal an error
            blink_led(3)
            return('Readline Error: No Input')

        # return the line in string format
        return incoming_line.decode('utf-8')

    except UnicodeError:
        # blink thrice to signal an error
        blink_led(3)
        return('Unicode Error: '+ str(incoming_line))

def main():
    while True:

        # if one or more lines of incoming data are available
        if uart0.any():
            # while there is still data available
            while uart0.any():
                # process the next line of data
                process_line()
    
            # blink once to signal that line(s) came in
            blink_led(1)
        else:
            # blink twice to signal that nothing came in
            blink_led(2)

        # wait a few seconds
        sleep(2)

```

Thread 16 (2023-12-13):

Small typo in the doc

FredM67, 2023-12-13:
Instead "Output AC voltage signal on RJ11 @ 240V = (120V / 60k 0.1%) x 75R 0.1% = 300 mV"

it should be "Output AC voltage signal on RJ11 @ 240V = (**240V** / 60k 0.1%) x 75R 0.1% = 300 mV"

240 instead of 120 ;-)

glynhudson, 2023-12-15:
Where in the doc is this?  The docs are in this repo

FredM67, 2023-12-15:
In the file "voltage_sensors.md". The typo is twice in the file.

TrystanLea, 2024-04-25:
Thanks fixed

Closed 2024-04-25.

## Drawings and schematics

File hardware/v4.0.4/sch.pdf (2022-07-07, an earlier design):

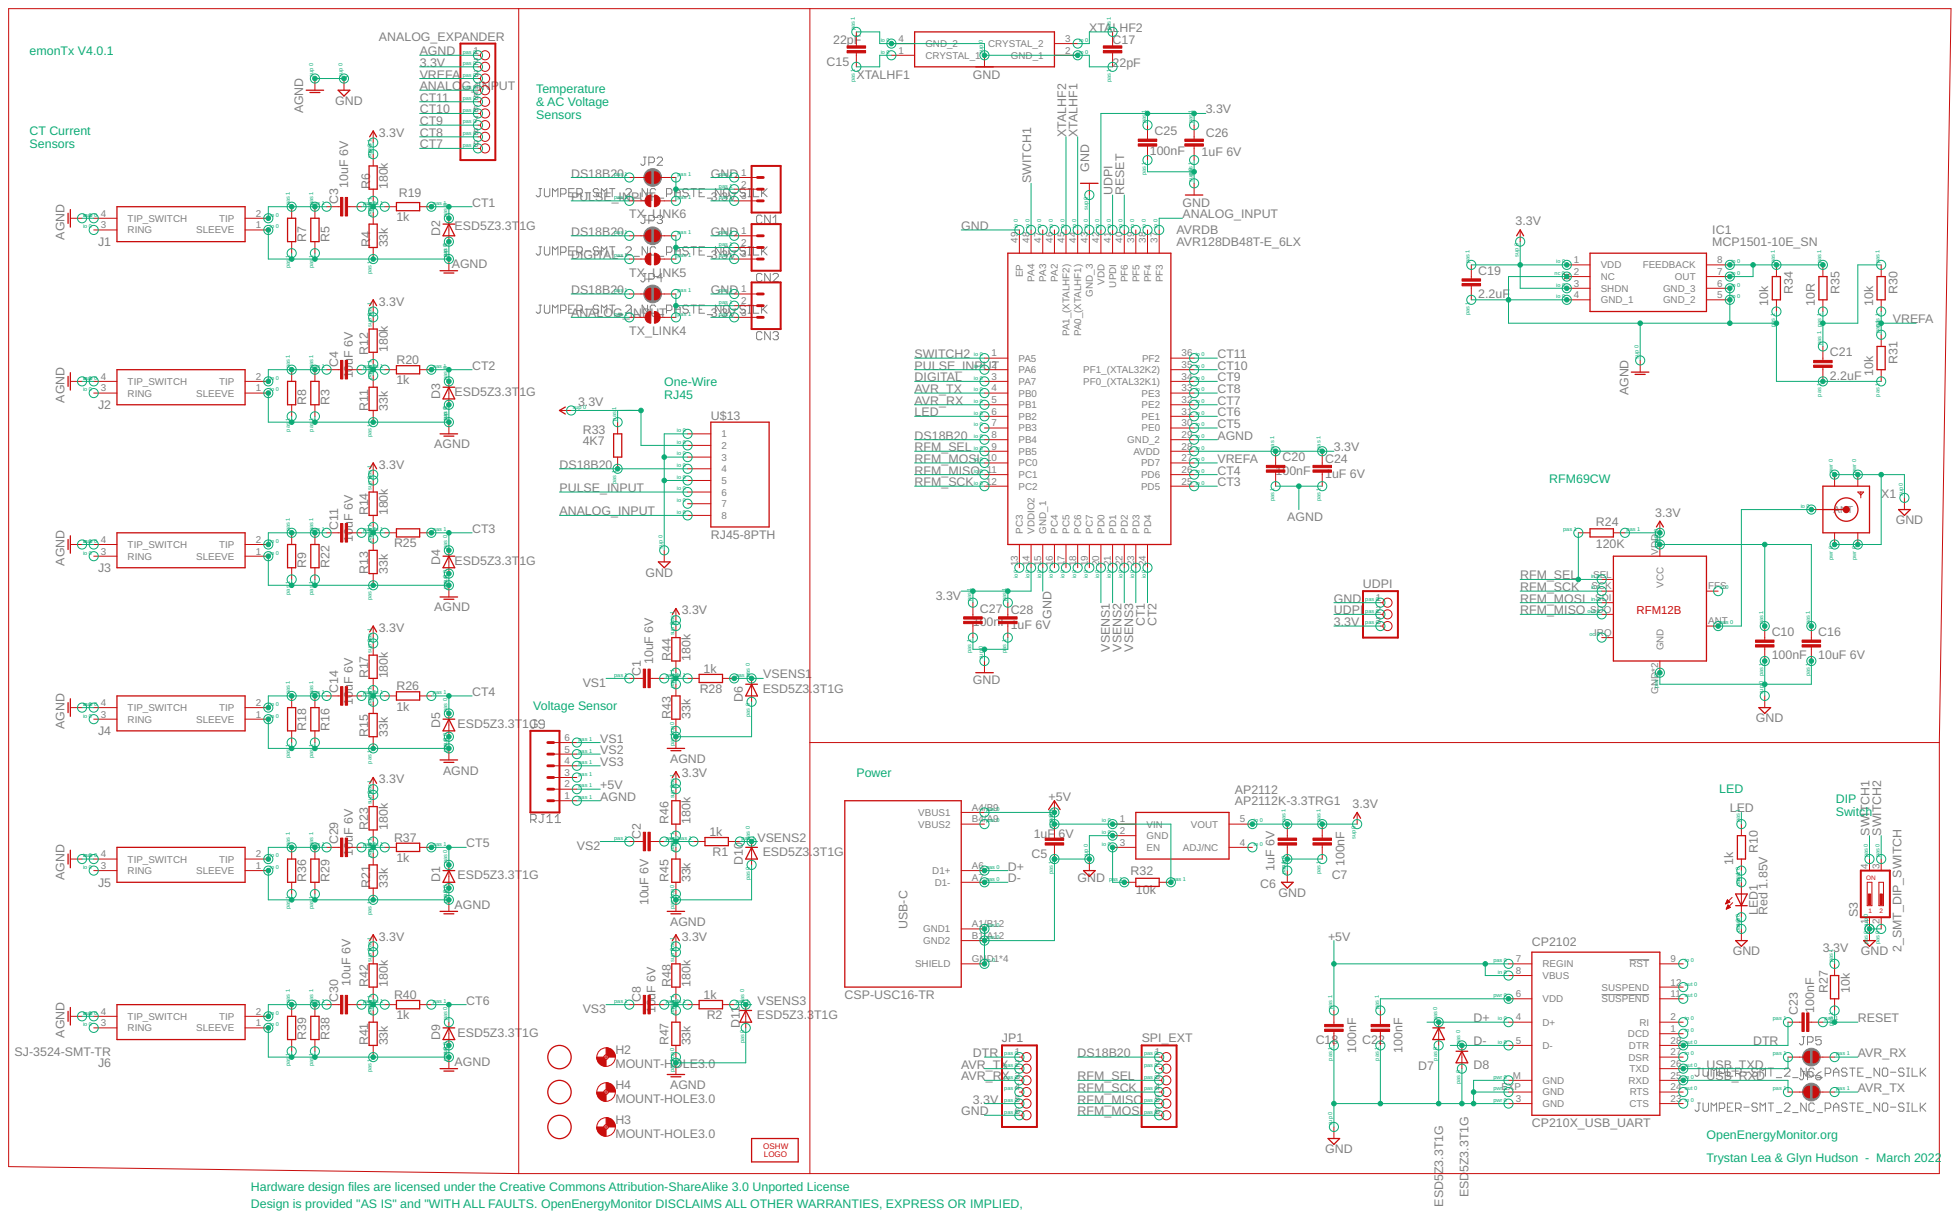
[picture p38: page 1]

pas 1 pas 1 pas 1 pas 1 sup 0 pas 1 pas 1 pas 1 pas 1 sup 0 pas 1 pas 1 pas 1 pas 1 sup 0 pas 1 pas 1 pas 1 pas 1 sup 0 pas 1 pas 1 pas 1 pas 1 sup 0

pas 1 pas 1 pas 1 pas 1

pas 1 pas 1 pas 1

AGND AGND AGND

pas 0 pas 0 pas 0 pas 0

sup 0 sup 0 sup 0 sup 0 sup 0
AGND

pas 1 pas 1

pas 1 pas 1 pas 1 pas 1 sup 0

sup 0 pas 1 pas 1 pas 1 pas 1 sup 0

1k GND MOUNT-HOLE3.0 MOUNT-HOLE3.0 MOUNT-HOLE3.0

OpenEnergyMonitor.org Trystan Lea & Glyn Hudson - March 2022

Design is provided "AS IS" and "WITH ALL FAULTS. OpenEnergyMonitor DISCLAIMS ALL OTHER WARRANTIES, EXPRESS OR IMPLIED, Hardware design files are licensed under the Creative Commons Attribution-ShareAlike 3.0 Unported License

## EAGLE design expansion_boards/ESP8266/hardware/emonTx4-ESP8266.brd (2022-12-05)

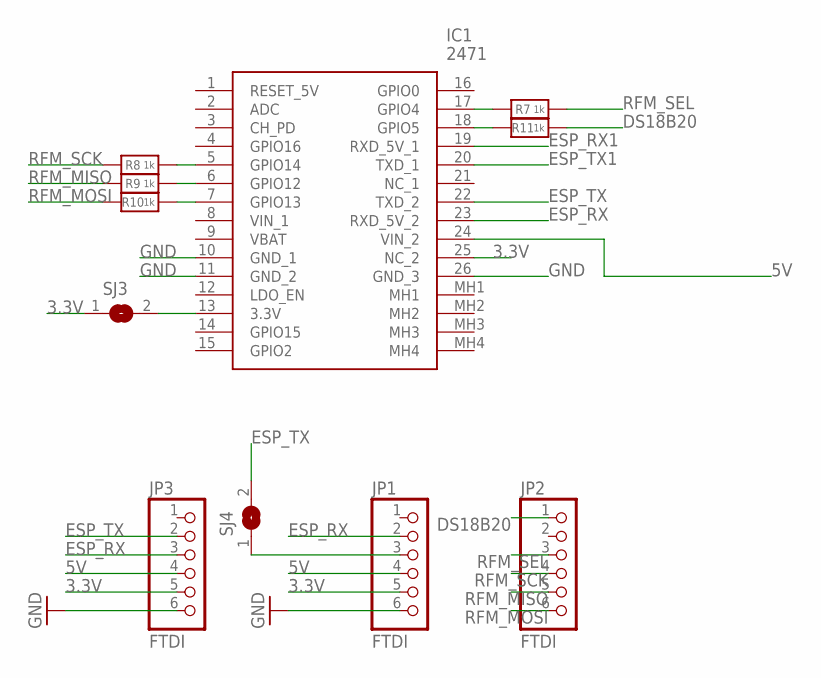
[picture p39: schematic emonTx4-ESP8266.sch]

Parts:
IC1: 2471
JP1, JP2, JP3: FTDI; 1X06_ROUND_70
R7, R8, R9, R10, R11: 1k; _0603
SJ3, SJ4: SJ

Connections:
3.3V: IC1.25 (NC_2), JP1.5, JP3.5, SJ3.1
5V: IC1.24 (VIN_2), JP1.4, JP3.4
DS18B20: JP2.1, R11.1
ESP_RX: IC1.23 (RXD_5V_2), JP1.2, JP3.3
ESP_RX1: IC1.19 (RXD_5V_1)
ESP_TX: IC1.22 (TXD_2), JP3.2, SJ4.2
ESP_TX1: IC1.20 (TXD_1)
GND: IC1.10 (GND_1), IC1.11 (GND_2), IC1.26 (GND_3), JP1.6, JP3.6
unnamed: JP1.3, SJ4.1
unnamed: IC1.13 (3.3V), SJ3.2
unnamed: IC1.17 (GPIO4), R7.2
unnamed: IC1.5 (GPIO14), R8.1
unnamed: IC1.6 (GPIO12), R9.1
unnamed: IC1.7 (GPIO13), R10.1
unnamed: IC1.18 (GPIO5), R11.2
RFM_MISO: JP2.5, R9.2
RFM_MOSI: JP2.6, R10.2
RFM_SCK: JP2.4, R8.2
RFM_SEL: JP2.3, R7.1

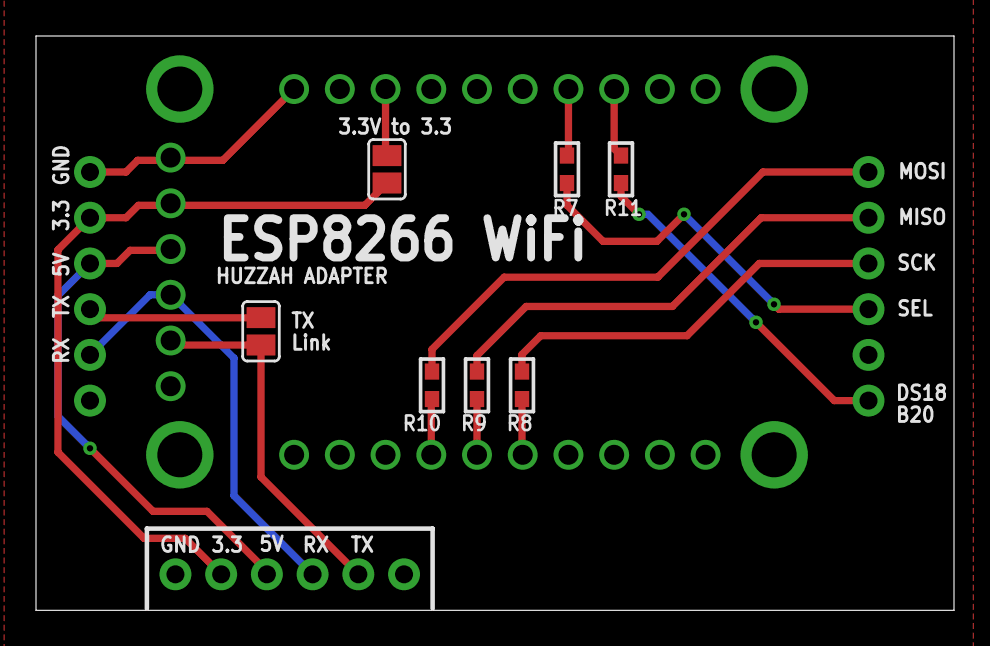
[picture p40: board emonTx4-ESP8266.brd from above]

Board: 2 copper layers, 51.0 x 31.9 mm, 11 parts (1 on the bottom side), 17 nets.

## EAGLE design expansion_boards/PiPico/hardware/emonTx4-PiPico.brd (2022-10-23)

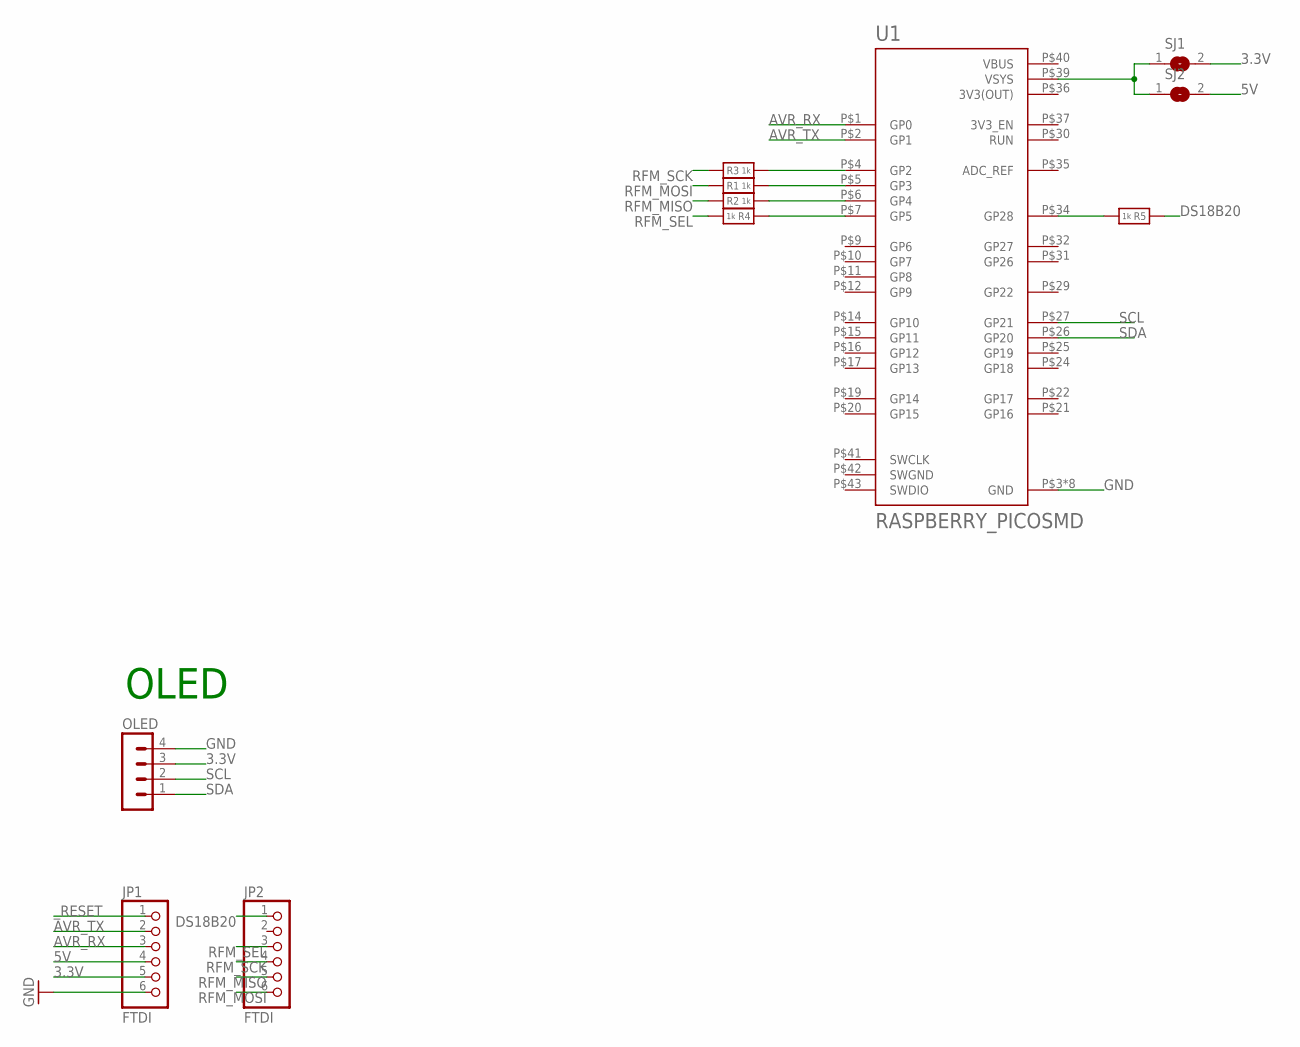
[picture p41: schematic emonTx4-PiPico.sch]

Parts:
JP1, JP2: FTDI; 1X06_ROUND_70
OLED: MA04-1-OLEDOLED; MA04-1-OLED
R1, R2, R3, R4, R5: 1k; _0603
SJ1, SJ2: SJ
U1: RASPBERRY_PICOSMD; PICO-PKG-SMD

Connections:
3.3V: JP1.5, OLED.3, SJ1.2
3V3(OUT): U1.P$36 (3V3(OUT))
5V: JP1.4, SJ2.2
AVR_RX: JP1.3, U1.P$1 (GP0)
AVR_TX: JP1.2, U1.P$2 (GP1)
DS18B20: JP2.1, R5.2
GND: JP1.6, OLED.4, U1.P$3 (GND), U1.P$8 (GND), U1.P$13 (GND), U1.P$18 (GND), U1.P$23 (GND), U1.P$28 (GND), U1.P$33 (GND), U1.P$38 (GND)
unnamed: SJ1.1, SJ2.1, U1.P$39 (VSYS)
unnamed: R3.1, U1.P$4 (GP2)
unnamed: R1.1, U1.P$5 (GP3)
unnamed: R2.1, U1.P$6 (GP4)
unnamed: R4.2, U1.P$7 (GP5)
unnamed: R5.1, U1.P$34 (GP28)
RFM_MISO: JP2.5, R2.2
RFM_MOSI: JP2.6, R1.2
RFM_SCK: JP2.4, R3.2
RFM_SEL: JP2.3, R4.1
SCL: OLED.2, U1.P$27 (GP21)
SDA: OLED.1, U1.P$26 (GP20)
SWGND: U1.P$42 (SWGND)
VBUS: U1.P$40 (VBUS)
_RESET: JP1.1

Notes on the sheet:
OLED

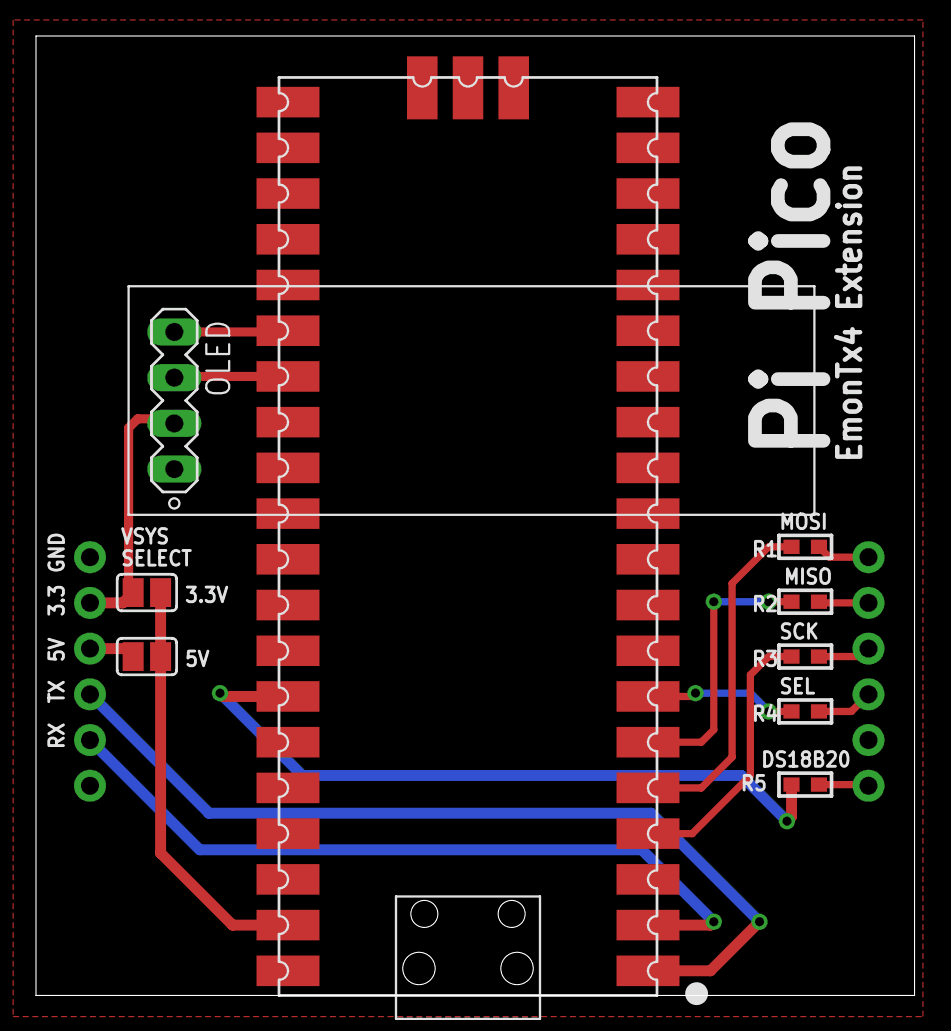
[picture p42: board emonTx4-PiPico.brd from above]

Board: 2 copper layers, 48.8 x 53.3 mm, 11 parts (0 on the bottom side), 18 nets.

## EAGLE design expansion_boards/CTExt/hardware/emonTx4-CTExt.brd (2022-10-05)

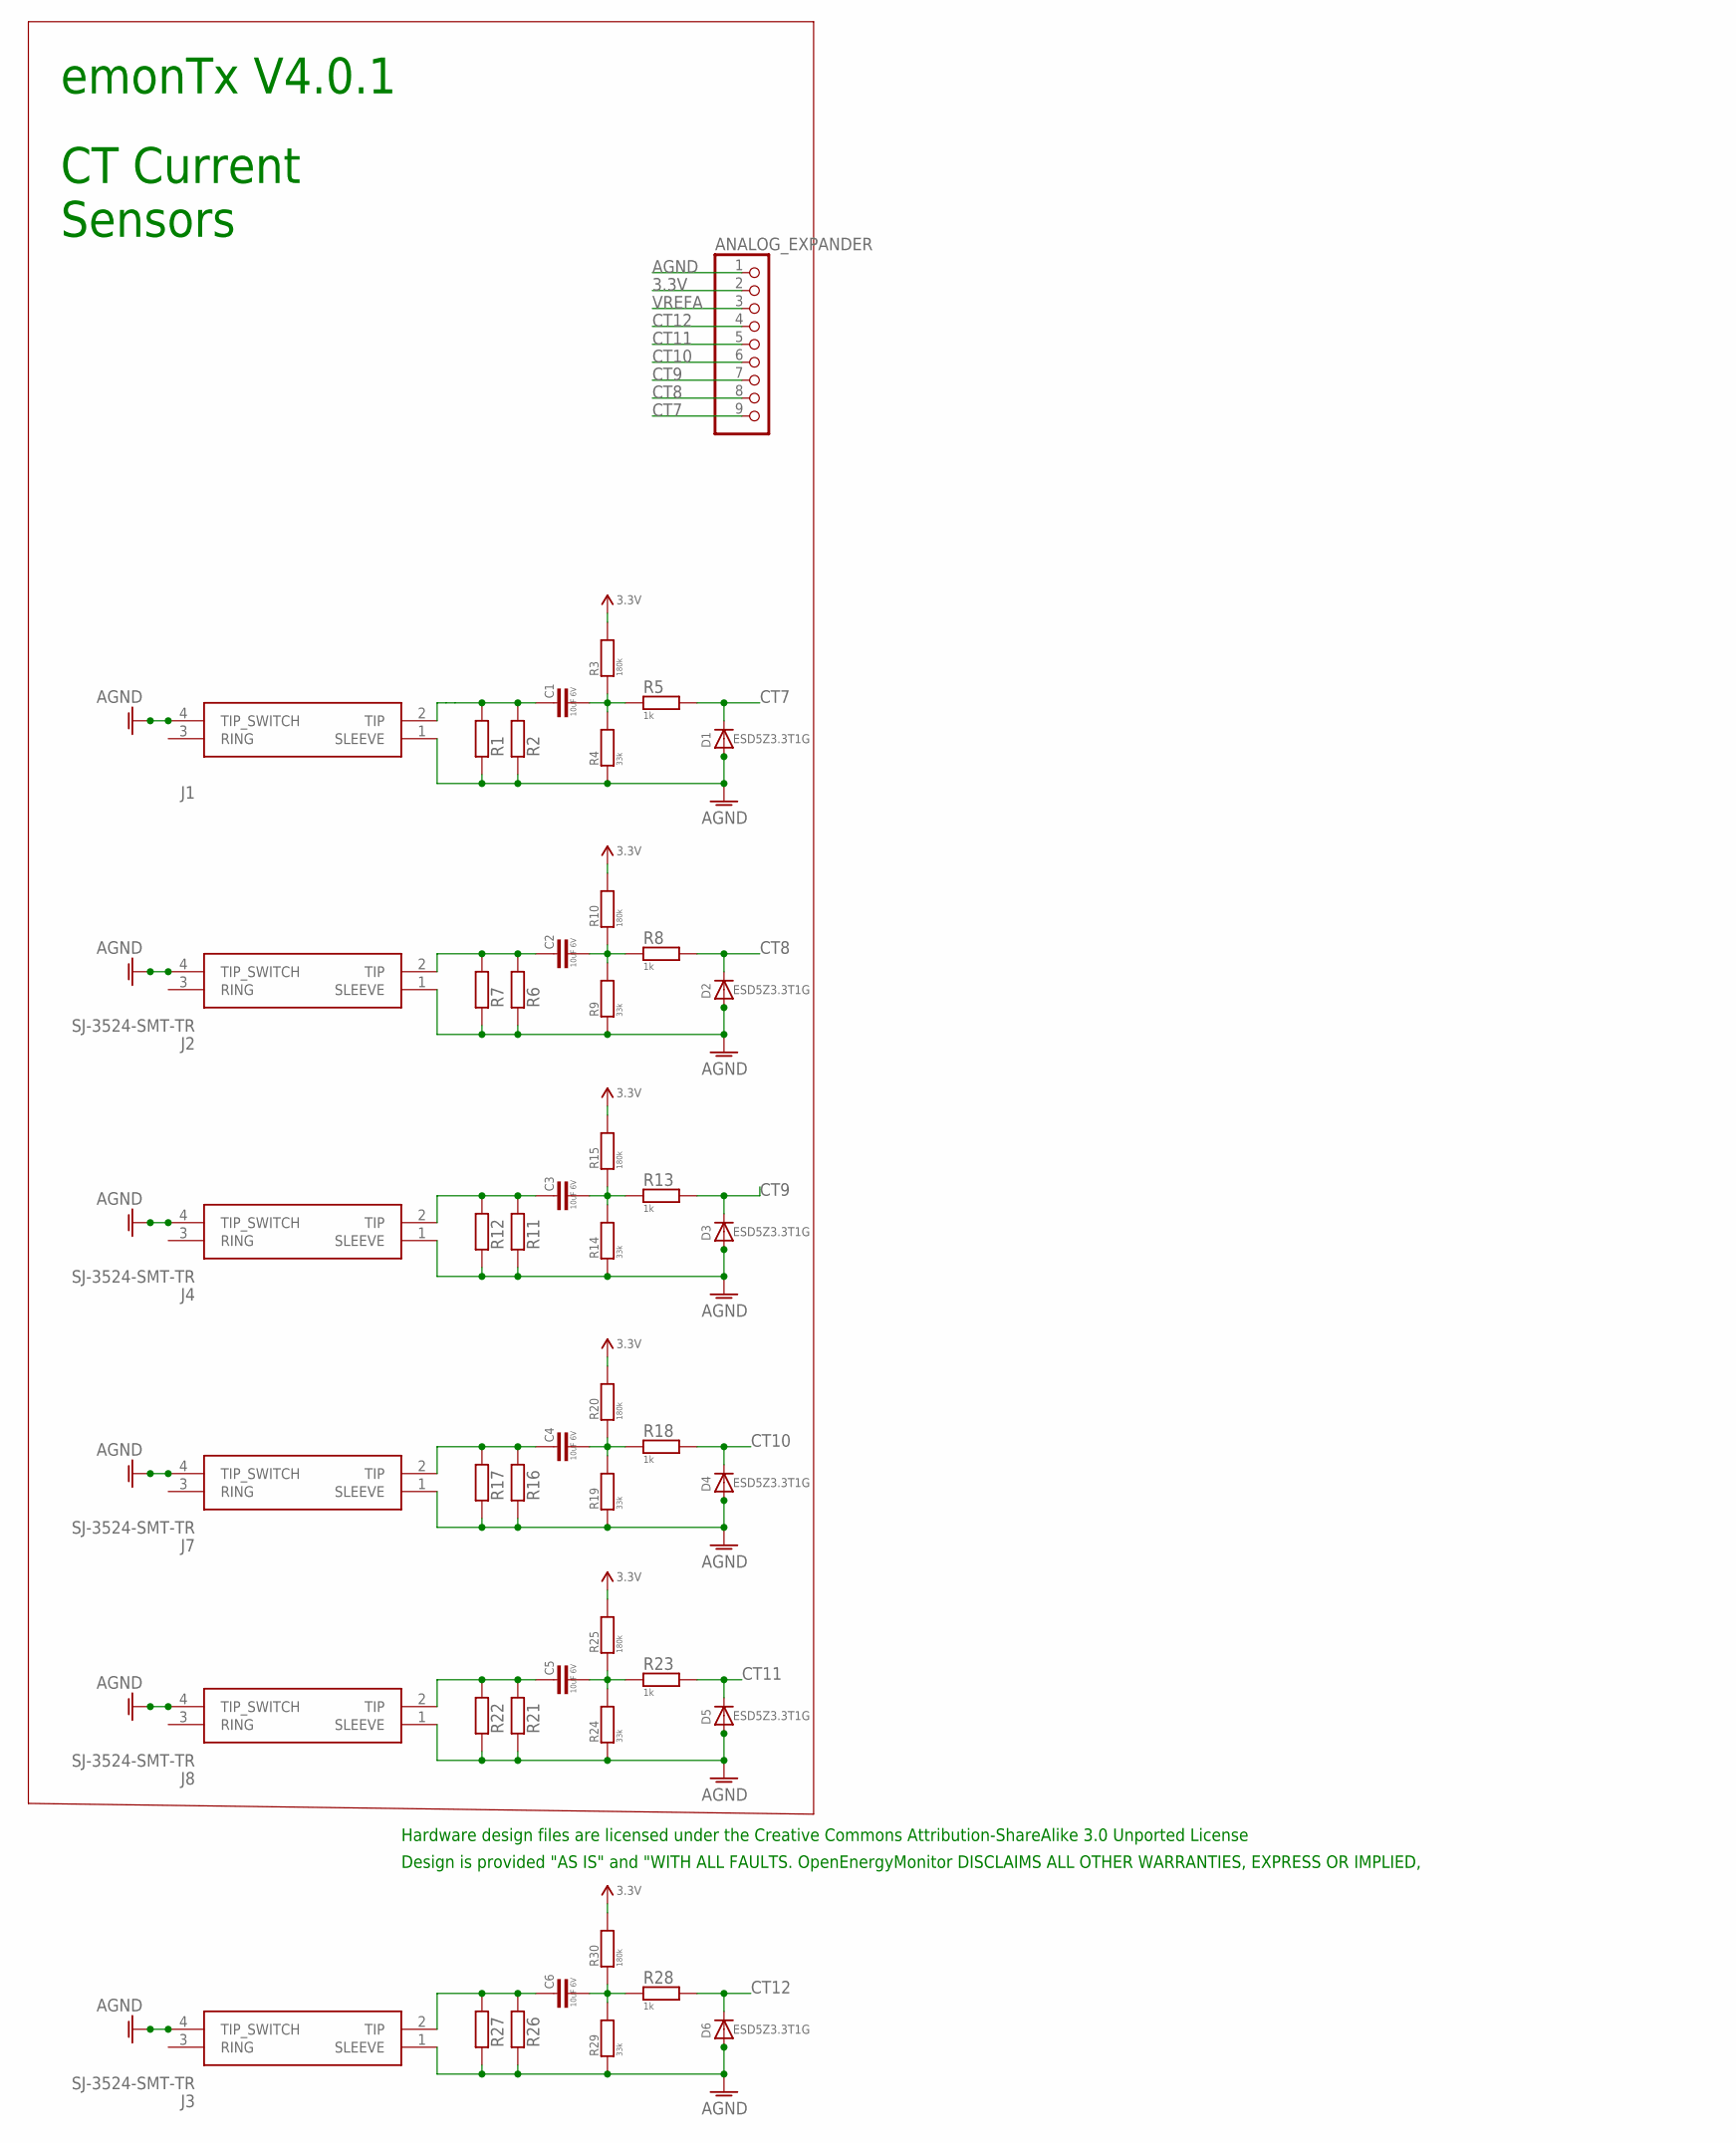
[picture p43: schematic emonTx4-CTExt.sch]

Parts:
ANALOG_EXPANDER: PINHD-1X9; 1X09-BIG
C1, C2, C3, C4, C5, C6: 10uF 6V; C0603
D1, D2, D3, D4, D5, D6: ESD5Z3.3T1G; SOD-523
J1, J2, J3, J4, J7, J8: SJ-3524-SMT-TR
R1, R7, R12, R17, R22, R27: R-EU_R1206; R1206
R2, R6, R11, R16, R21, R26: R-EU_0204/7; 0204/7
R3, R10, R15, R20, R25, R30: 180k; R0603
R4, R9, R14, R19, R24, R29: 33k; R0603
R5, R8, R13, R18, R23, R28: 1k; R0603

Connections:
3.3V: ANALOG_EXPANDER.2, R3.2, R10.2, R15.2, R20.2, R25.2, R30.2
AGND: ANALOG_EXPANDER.1, D1.A, D2.A, D3.A, D4.A, D5.A, D6.A, J1.1 (SLEEVE), J1.4 (TIP_SWITCH), J2.1 (SLEEVE), J2.4 (TIP_SWITCH), J3.1 (SLEEVE), J3.4 (TIP_SWITCH), J4.1 (SLEEVE), J4.4 (TIP_SWITCH), J7.1 (SLEEVE), J7.4 (TIP_SWITCH), J8.1 (SLEEVE), J8.4 (TIP_SWITCH), R1.1, R2.1, R4.2, R6.1, R7.1, R9.2, R11.1, R12.1, R14.2, R16.1, R17.1, R19.2, R21.1, R22.1, R24.2, R26.1, R27.1, R29.2
CT7: ANALOG_EXPANDER.9, D1.K (C), R5.2
CT8: ANALOG_EXPANDER.8, D2.K (C), R8.2
CT9: ANALOG_EXPANDER.7, D3.K (C), R13.2
CT10: ANALOG_EXPANDER.6, D4.K (C), R18.2
CT11: ANALOG_EXPANDER.5, D5.K (C), R23.2
CT12: ANALOG_EXPANDER.4, D6.K (C), R28.2
unnamed: C2.1, J2.2 (TIP), R6.2, R7.2
unnamed: C2.2, R8.1, R9.1, R10.1
unnamed: C3.1, J4.2 (TIP), R11.2, R12.2
unnamed: C3.2, R13.1, R14.1, R15.1
unnamed: C4.1, J7.2 (TIP), R16.2, R17.2
unnamed: C4.2, R18.1, R19.1, R20.1
unnamed: C5.1, J8.2 (TIP), R21.2, R22.2
unnamed: C5.2, R23.1, R24.1, R25.1
unnamed: C6.1, J3.2 (TIP), R26.2, R27.2
unnamed: C6.2, R28.1, R29.1, R30.1
unnamed: C1.2, R3.1, R4.1, R5.1
unnamed: C1.1, J1.2 (TIP), R1.2, R2.2
VREFA: ANALOG_EXPANDER.3

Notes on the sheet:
CT Current Sensors
Design is provided "AS IS" and "WITH ALL FAULTS. OpenEnergyMonitor DISCLAIMS ALL OTHER WARRANTIES, EXPRESS OR IMPLIED,
Hardware design files are licensed under the Creative Commons Attribution-ShareAlike 3.0 Unported License
emonTx V4.0.1

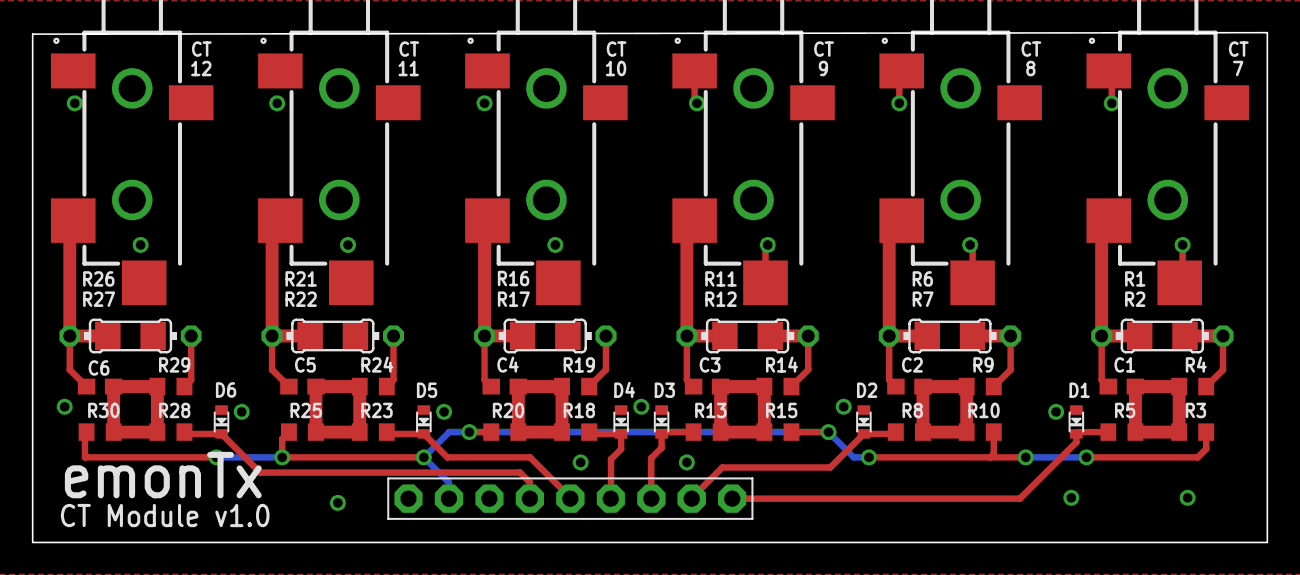
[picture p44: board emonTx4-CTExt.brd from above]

Board: 2 copper layers, 77.5 x 32.0 mm, 49 parts (0 on the bottom side), 20 nets.

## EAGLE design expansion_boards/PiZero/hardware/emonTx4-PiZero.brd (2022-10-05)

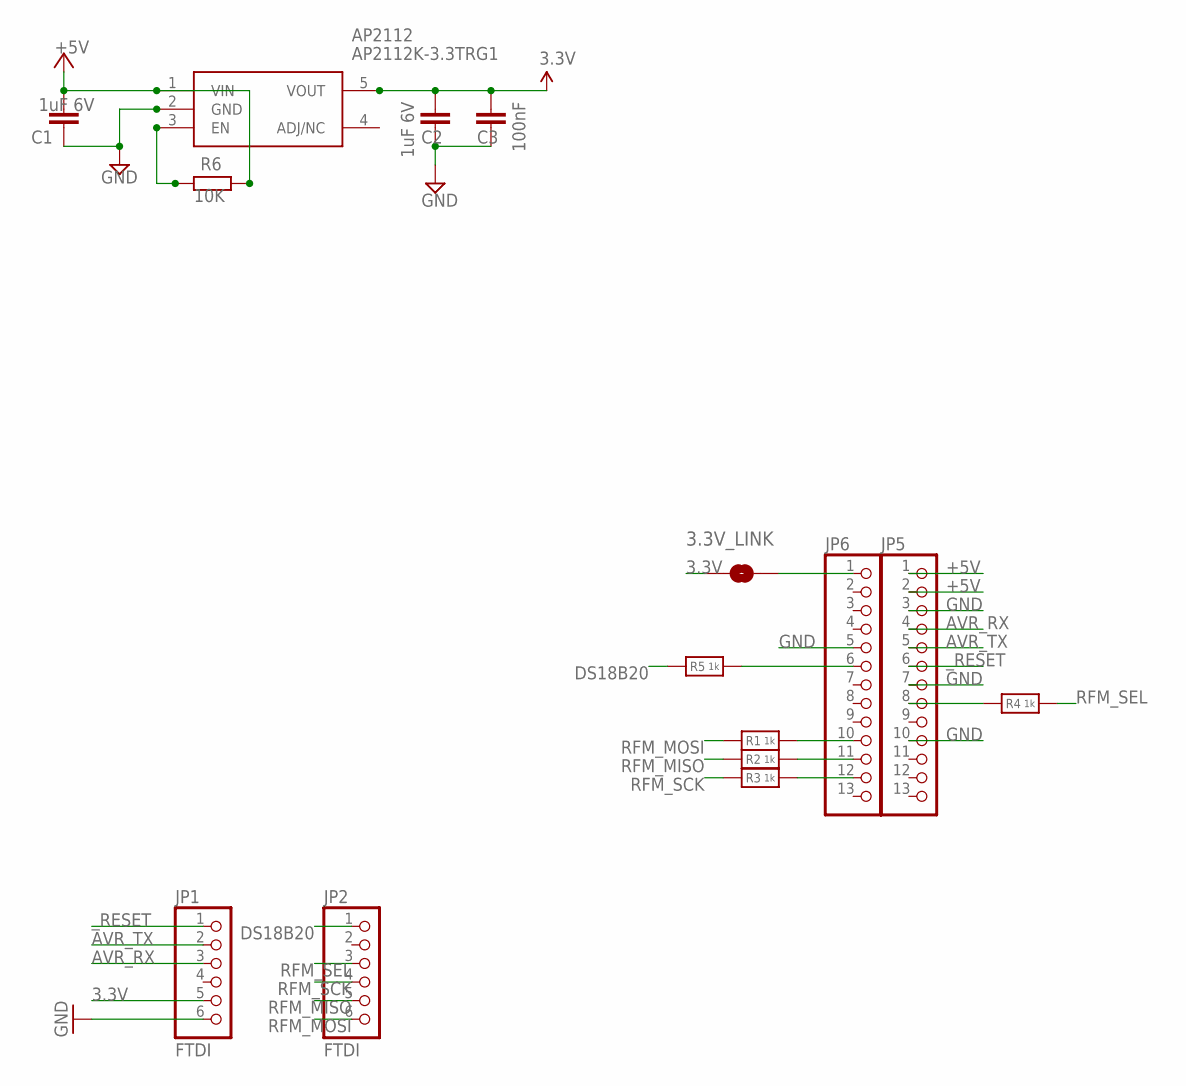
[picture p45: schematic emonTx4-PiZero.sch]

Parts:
3.3V_LINK: SOLDERJUMPERNC; SJ_2S
AP2112: AP2112K-3.3TRG1; SOT95P282X130-5N
C1, C2: 1uF 6V; C0603
C3: 100nF; C0603
JP1, JP2: FTDI; 1X06_ROUND_70
JP5, JP6: PINHD-1X13_BIG; 1X13-BIG
R1, R2, R3, R4, R5: 1k; _0603
R6: 10K; R0603

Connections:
3.3V: 3.3V_LINK.1, AP2112.5 (VOUT), C2.2, C3.2, JP1.5
+5V: AP2112.1 (VIN), C1.2, JP5.1, JP5.2, R6.1
AVR_RX: JP1.3, JP5.4
AVR_TX: JP1.2, JP5.5
DS18B20: JP2.1, R5.2
GND: AP2112.2 (GND), C1.1, C2.1, C3.1, JP1.6, JP5.3, JP5.7, JP5.10, JP6.5
unnamed: JP5.8, R4.2
unnamed: JP6.6, R5.1
unnamed: 3.3V_LINK.2, JP6.1
unnamed: JP6.10, R1.1
unnamed: JP6.11, R2.1
unnamed: JP6.12, R3.1
unnamed: AP2112.3 (EN), R6.2
RFM_MISO: JP2.5, R2.2
RFM_MOSI: JP2.6, R1.2
RFM_SCK: JP2.4, R3.2
RFM_SEL: JP2.3, R4.1
_RESET: JP1.1, JP5.6

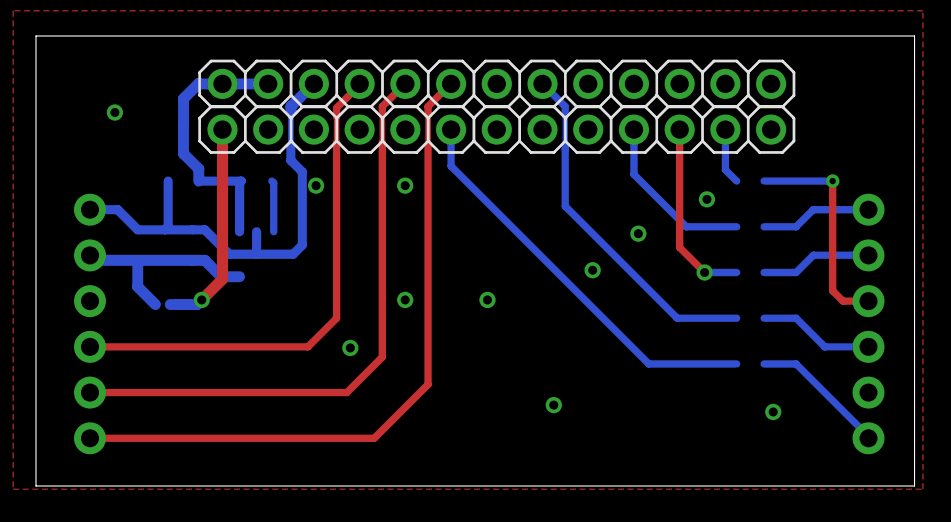
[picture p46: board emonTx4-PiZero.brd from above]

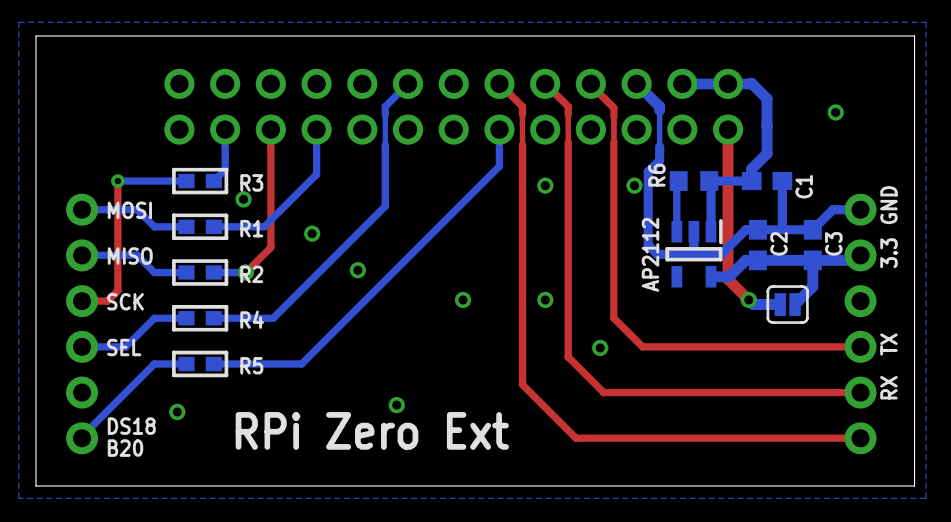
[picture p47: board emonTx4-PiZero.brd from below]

Board: 2 copper layers, 48.8 x 25.0 mm, 15 parts (11 on the bottom side), 18 nets.

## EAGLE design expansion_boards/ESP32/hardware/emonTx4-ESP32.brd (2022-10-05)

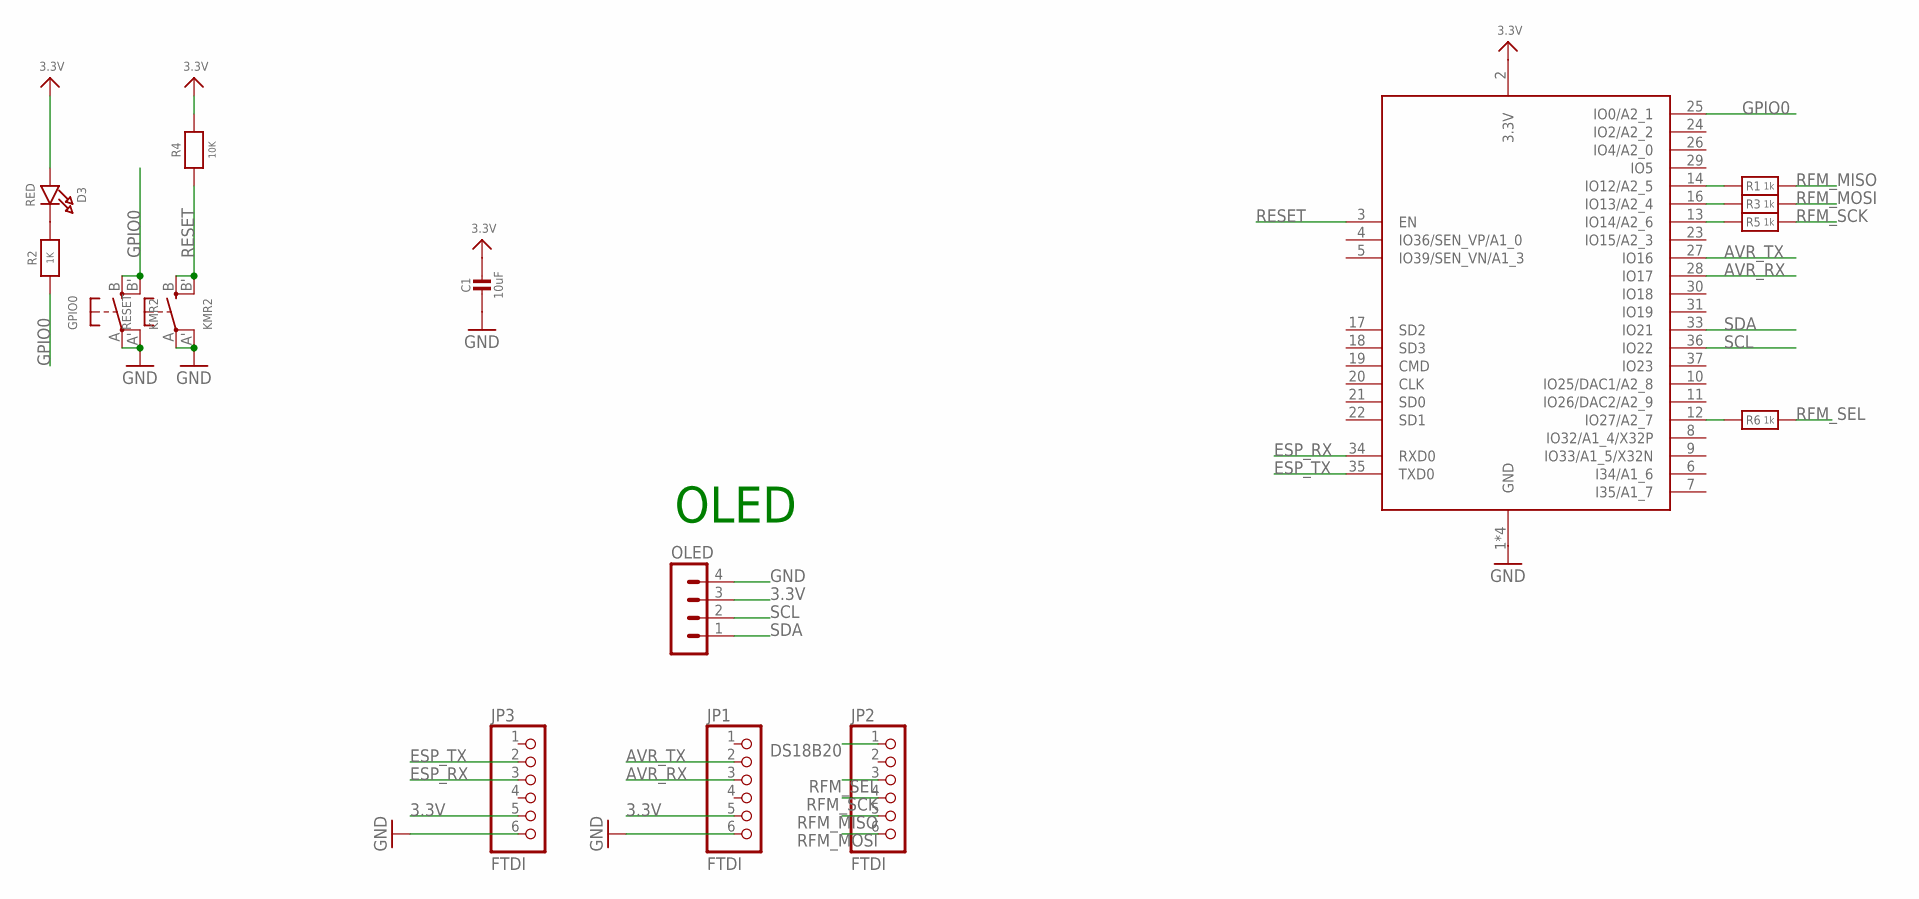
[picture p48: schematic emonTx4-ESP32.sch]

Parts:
C1: 10uF; _0603
D3: RED; CHIPLED_0603
GPIO0: KMR2; BTN_KMR2_4.6X2.8
JP1, JP2, JP3: FTDI; 1X06_ROUND_70
OLED: MA04-1-OLEDOLED; MA04-1-OLED
R1, R3, R5, R6: 1k; _0603
R2: 1K; _0603
R4: 10K; _0603
RESET: KMR2; BTN_KMR2_4.6X2.8
X2: ESP32_WROOM32; WROOM32

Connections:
3.3V: C1.1, D3.A, JP1.5, JP3.5, OLED.3, R4.2, X2.2 (3.3V)
AVR_RX: JP1.3, X2.28 (IO17)
AVR_TX: JP1.2, X2.27 (IO16)
DS18B20: JP2.1
ESP_RX: JP3.3, X2.34 (RXD0)
ESP_TX: JP3.2, X2.35 (TXD0)
GND: C1.2, GPIO0.A, GPIO0.A' (P1), JP1.6, JP3.6, OLED.4, RESET.A, RESET.A' (P1), X2.1 (GND), X2.15 (GND), X2.38 (GND), X2.P$1 (GND)
GPIO0: GPIO0.B (S), GPIO0.B' (S1), R2.1, X2.25 (IO0/A2_1)
unnamed: D3.C, R2.2
unnamed: R1.2, X2.14 (IO12/A2_5)
unnamed: R3.2, X2.16 (IO13/A2_4)
unnamed: R5.2, X2.13 (IO14/A2_6)
unnamed: R6.2, X2.12 (IO27/A2_7)
RESET: R4.1, RESET.B (S), RESET.B' (S1), X2.3 (EN)
RFM_MISO: JP2.5, R1.1
RFM_MOSI: JP2.6, R3.1
RFM_SCK: JP2.4, R5.1
RFM_SEL: JP2.3, R6.1
SCL: OLED.2, X2.36 (IO22)
SDA: OLED.1, X2.33 (IO21)

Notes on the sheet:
OLED

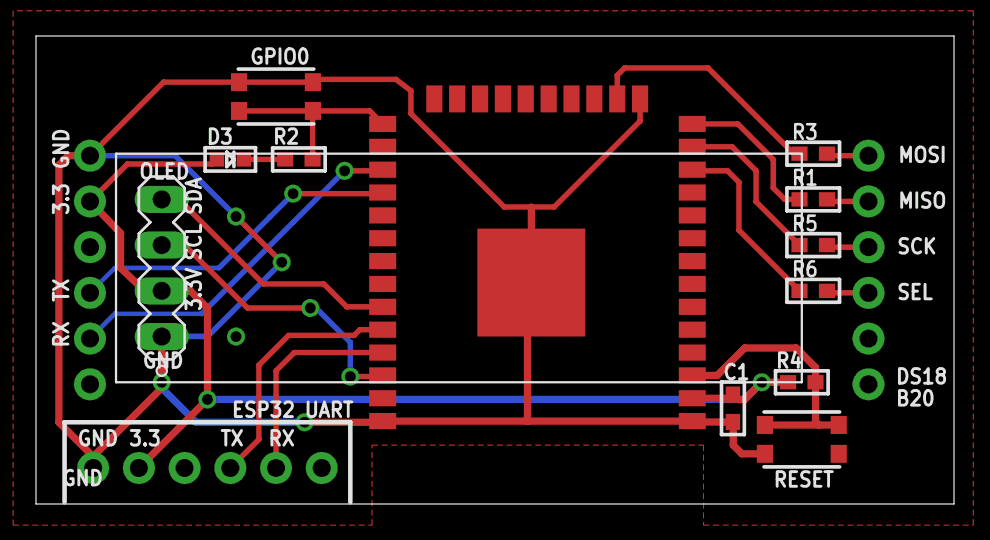
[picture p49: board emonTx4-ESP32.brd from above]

Board: 2 copper layers, 51.0 x 26.0 mm, 15 parts (0 on the bottom side), 19 nets.

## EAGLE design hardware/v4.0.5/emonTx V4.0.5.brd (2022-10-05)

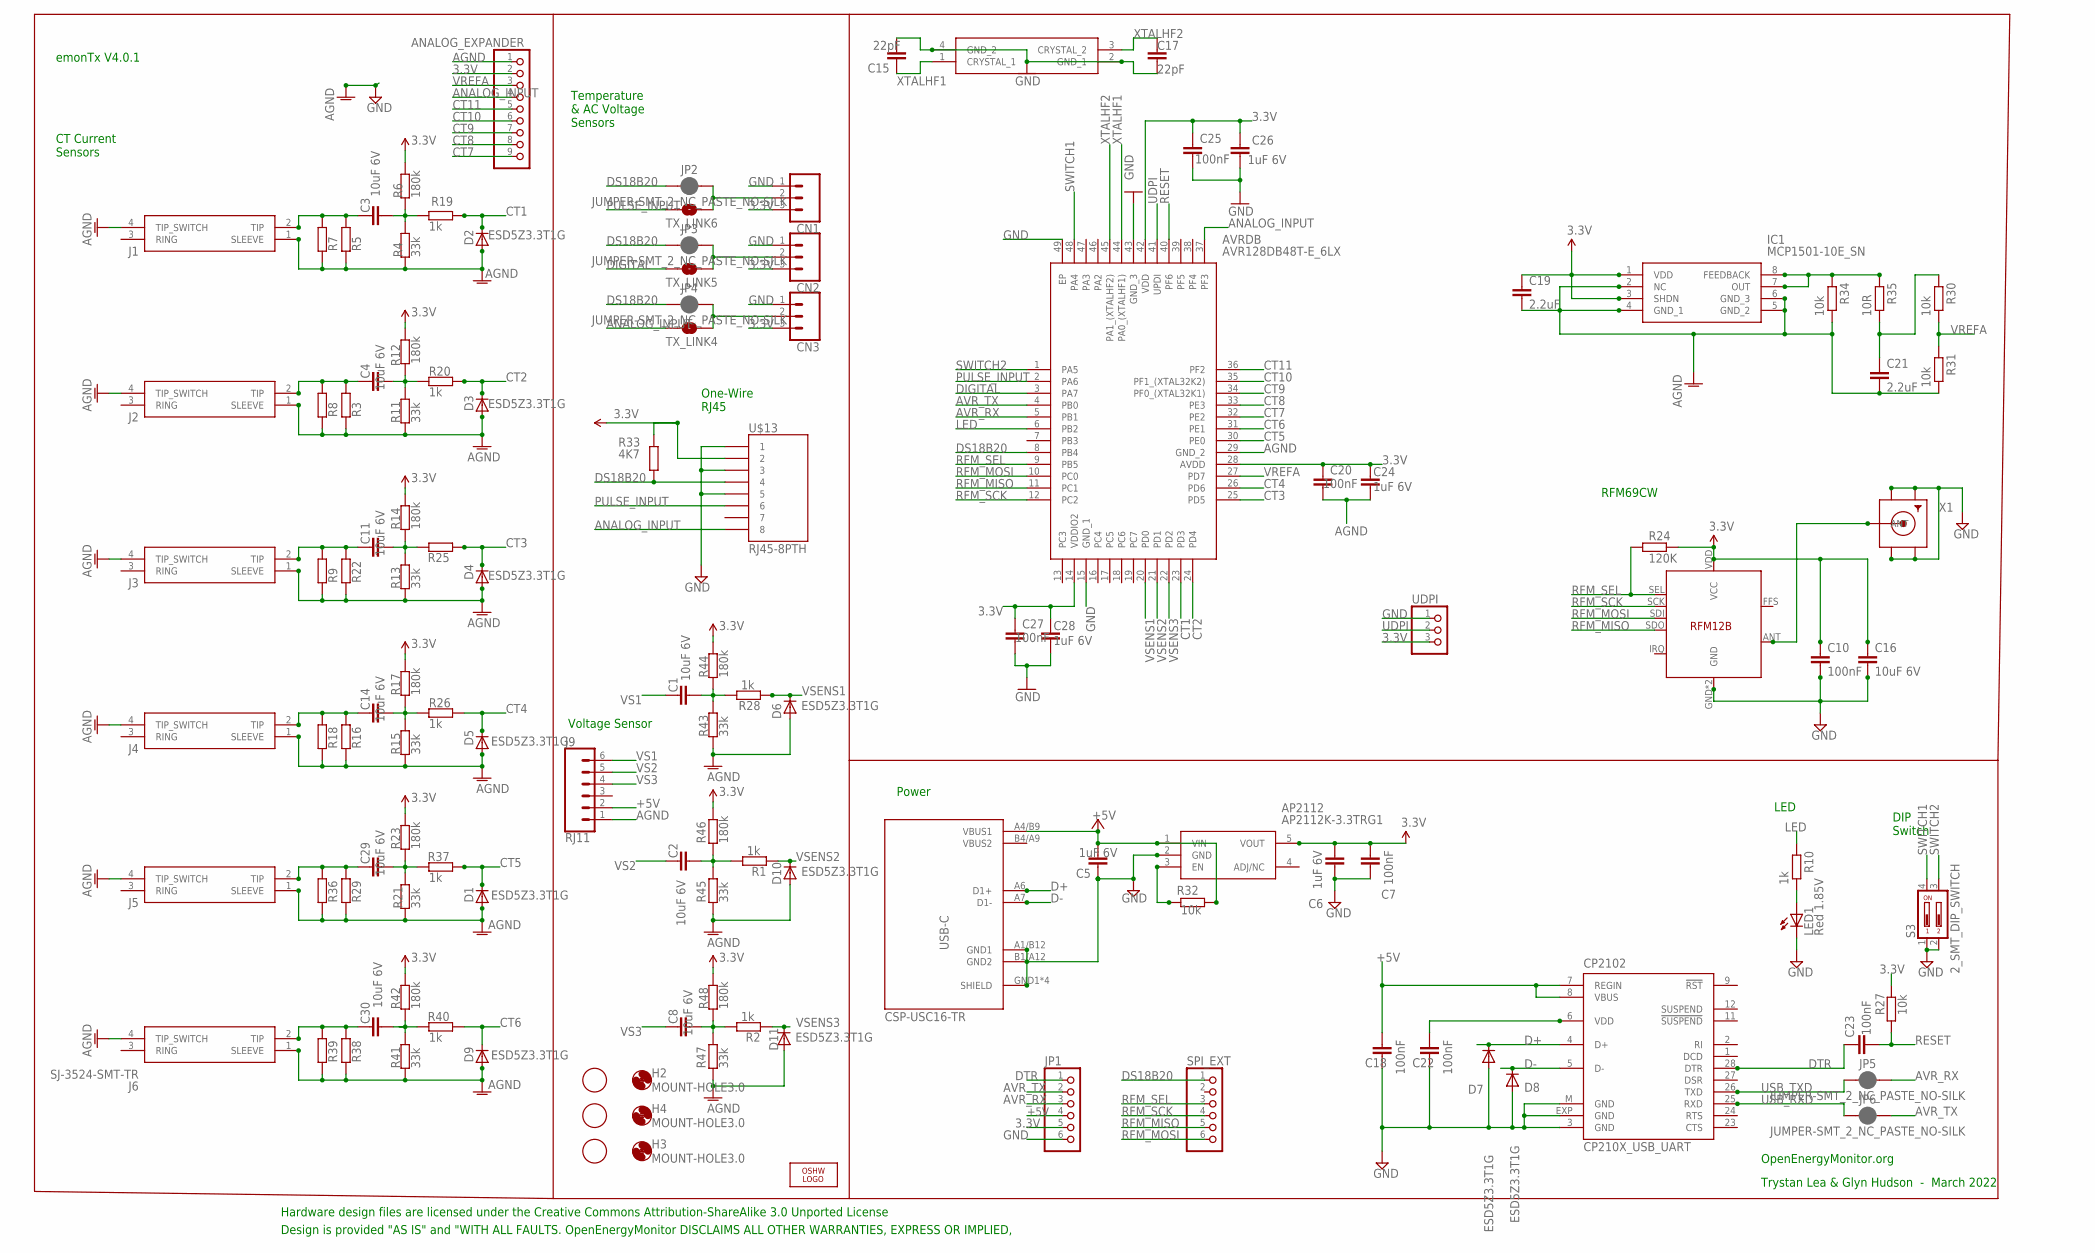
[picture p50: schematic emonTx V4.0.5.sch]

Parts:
ANALOG_EXPANDER: PINHD-1X9; 1X09-BIG
AP2112: AP2112K-3.3TRG1; SOT95P282X130-5N
AVRDB: AVR128DB48T-E_6LX; QFN40P600X600X90-49N
C1, C2, C3, C4, C8, C11, C14, C16, C29, C30: 10uF 6V; C0603
C5, C6, C24, C26, C28: 1uF 6V; C0603
C7, C10, C18, C20, C22, C23, C25, C27: 100nF; C0603
C15, C17: 22pF; C0603
C19, C21: 2.2uF; C0603
CN1, CN2, CN3: CONN_03SCREW; SCREWTERMINAL-3.5MM-3
CP2102: CP210X_USB_UART; MLP28
D1, D2, D3, D4, D5, D6, D7, D8, D9, D10, D11: ESD5Z3.3T1G; SOD-523
H2, H3, H4: MOUNT-HOLE3.0; 3,0
IC1: MCP1501-10E_SN; SOIC127P600X175-8N
J1, J2, J3, J4, J5, J6: SJ-3524-SMT-TR
J9: RJ11; RJ11-6
JP1: PINHD-1X6; 1X06
JP2, JP3, JP4, JP5, JP6: JUMPER-SMT_2_NC_PASTE_NO-SILK; SMT-JUMPER_2_NC_PASTE_NO-SILK
LED1: Red 1.85V; CHIP-LED0805
LOGO1: OSHW_LOGO_6MILX0200-NT; OSHW_6X200_NOTEXT
R1, R2, R10, R19, R20, R25, R26, R28, R37, R40: 1k; R0603
R3, R5, R16, R22, R29, R38: R-EU_0204/7; 0204/7
R4, R11, R13, R15, R21, R41, R43, R45, R47: 33k; R0603
R6, R12, R14, R17, R23, R42, R44, R46, R48: 180k; R0603
R7, R8, R9, R18, R36, R39: R-EU_R1206; R1206
R24: 120K; R0603
R27, R30, R31, R32, R34: 10k; R0603
R33: 4K7; R0603
R35: 10R; R0603
S3: 2_SMT_DIP_SWITCH; DIP_SWITCH_SMT
SPI_EXT: PINHD-1X6; 1X06
TX_LINK4, TX_LINK5, TX_LINK6: SOLDERJUMPERNC; SJ_2S
U$4, U$5, U$7: FIDUCIAL; FIDUCIAL_1MM
U$13: RJ45-8PTH; RJ45-8
U$14: RFM12B
UDPI: PINHD-1X3; 1X03
USB-C: CSP-USC16-TR; USB-C
X1: SMACONNECTOR; SMA90_DIP
XTAL: MCSJK-7U-12.00-12-10-80-B-10; MCSJK7U1200121080B10

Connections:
3.3V: ANALOG_EXPANDER.2, AP2112.5 (VOUT), AVRDB.14 (VDDIO2), AVRDB.28 (AVDD), AVRDB.42 (VDD), C6.2, C7.2, C10.1, C16.1, C19.1, C20.1, C24.1, C25.1, C26.1, C27.1, C28.1, CN1.3, CN2.3, CN3.3, IC1.1 (VDD), IC1.3 (SHDN), JP1.5, R6.2, R12.2, R14.2, R17.2, R23.2, R24.2, R27.2, R33.1, R42.2, R44.2, R46.2, R48.2, U$13.2, U$14.VDD (VCC), UDPI.3
+5V: AP2112.1 (VIN), C5.2, C18.2, CP2102.7 (REGIN), CP2102.8 (VBUS), J9.2, JP1.4, R32.1, USB-C.A4/B9 (VBUS1)
AGND: ANALOG_EXPANDER.1, AVRDB.29 (GND_2), C19.2, C20.2, C21.2, C24.2, D1.A, D2.A, D3.A, D4.A, D5.A, D6.A, D9.A, D10.A, D11.A, IC1.2 (NC), IC1.4 (GND_1), IC1.5 (GND_2), IC1.6 (GND_3), J1.1 (SLEEVE), J1.4 (TIP_SWITCH), J2.1 (SLEEVE), J2.4 (TIP_SWITCH), J3.1 (SLEEVE), J3.4 (TIP_SWITCH), J4.1 (SLEEVE), J4.4 (TIP_SWITCH), J5.1 (SLEEVE), J5.4 (TIP_SWITCH), J6.1 (SLEEVE), J6.4 (TIP_SWITCH), J9.1, R3.1, R4.2, R5.1, R7.1, R8.1, R9.1, R11.2, R13.2, R15.2, R16.1, R18.1, R21.2, R22.1, R29.1, R31.1, R34.1, R36.1, R38.1, R39.1, R41.2, R43.2, R45.2, R47.2
ANALOG_INPUT: ANALOG_EXPANDER.4, AVRDB.37 (PF3), TX_LINK4.1, U$13.8
AVR_RX: AVRDB.5 (PB1), JP1.3, JP5.2
AVR_TX: AVRDB.4 (PB0), JP1.2, JP6.2
CT1: AVRDB.23 (PD3), D2.K (C), R19.2
CT2: AVRDB.24 (PD4), D3.K (C), R20.2
CT3: AVRDB.25 (PD5), D4.K (C), R25.1
CT4: AVRDB.26 (PD6), D5.K (C), R26.2
CT5: AVRDB.30 (PE0), D1.K (C), R37.2
CT6: AVRDB.31 (PE1), D9.K (C), R40.2
CT7: ANALOG_EXPANDER.9, AVRDB.32 (PE2)
CT8: ANALOG_EXPANDER.8, AVRDB.33 (PE3)
CT9: ANALOG_EXPANDER.7, AVRDB.34 (PF0_(XTAL32K1))
CT10: ANALOG_EXPANDER.6, AVRDB.35 (PF1_(XTAL32K2))
CT11: ANALOG_EXPANDER.5, AVRDB.36 (PF2)
D+: CP2102.4 (D+), D7.K (C), USB-C.A6 (D1+)
D-: CP2102.5 (D-), D8.K (C), USB-C.A7 (D1-)
DIG1: U$14.ANT, X1.ANTENNA (ANT)
DIGITAL: AVRDB.3 (PA7), TX_LINK5.1
DS18B20: AVRDB.8 (PB4), JP2.1, JP3.1, JP4.1, R33.2, SPI_EXT.1, U$13.4
DTR: C23.1, CP2102.28 (DTR), JP1.1
GND: AP2112.2 (GND), AVRDB.15 (GND_1), AVRDB.43 (GND_3), AVRDB.49 (EP), C5.1, C6.1, C7.1, C10.2, C15.2, C16.2, C17.2, C18.1, C22.1, C25.2, C26.2, C27.2, C28.2, CN1.1, CN2.1, CN3.1, CP2102.3 (GND), CP2102.EXP (GND), CP2102.M (GND), D7.A, D8.A, JP1.6, LED1.C, S3.1, S3.2, U$13.1, U$13.3, U$13.5, U$14.GND, U$14.P$12 (GND), UDPI.1, USB-C.A1/B12 (GND1), USB-C.B1/A12 (GND2), USB-C.GND1 (SHIELD), USB-C.GND2 (SHIELD), USB-C.GND3 (SHIELD), USB-C.GND4 (SHIELD), X1.GND1, X1.GND2, X1.GND3, X1.GND4, XTAL.2 (GND_1), XTAL.4 (GND_2)
LED: AVRDB.6 (PB2), R10.2
unnamed: AP2112.3 (EN), R32.2
unnamed: C30.1, J6.2 (TIP), R38.2, R39.2
unnamed: C11.1, J3.2 (TIP), R9.2, R22.2
unnamed: C22.2, CP2102.6 (VDD)
unnamed: C30.2, R40.1, R41.1, R42.1
unnamed: C21.1, R30.2, R35.1
unnamed: C3.2, R4.1, R6.1, R19.1
unnamed: C14.1, J4.2 (TIP), R16.2, R18.2
unnamed: C14.2, R15.1, R17.1, R26.1
unnamed: C3.1, J1.2 (TIP), R5.2, R7.2
unnamed: C4.2, R11.1, R12.1, R20.1
unnamed: C29.1, J5.2 (TIP), R29.2, R36.2
unnamed: C4.1, J2.2 (TIP), R3.2, R8.2
unnamed: C1.2, R28.2, R43.1, R44.1
unnamed: CN1.2, JP2.2, TX_LINK6.2
unnamed: CN2.2, JP3.2, TX_LINK5.2
unnamed: C2.2, R1.2, R45.1, R46.1
unnamed: CN3.2, JP4.2, TX_LINK4.2
unnamed: C8.2, R2.2, R47.1, R48.1
unnamed: IC1.7 (OUT), IC1.8 (FEEDBACK), R34.2, R35.2
unnamed: C29.2, R21.1, R23.1, R37.1
unnamed: C11.2, R13.1, R14.1, R25.2
unnamed: LED1.A, R10.1
PULSE_INPUT: AVRDB.2 (PA6), TX_LINK6.1, U$13.6
RESET: AVRDB.40 (PF6), C23.2, R27.1
RFM_MISO: AVRDB.11 (PC1), SPI_EXT.5, U$14.SDO
RFM_MOSI: AVRDB.10 (PC0), SPI_EXT.6, U$14.SDI
RFM_SCK: AVRDB.12 (PC2), SPI_EXT.4, U$14.SCK
RFM_SEL: AVRDB.9 (PB5), R24.1, SPI_EXT.3, U$14.SEL
SWITCH1: AVRDB.48 (PA4), S3.4
SWITCH2: AVRDB.1 (PA5), S3.3
UDPI: AVRDB.41 (UPDI), UDPI.2
USB_RXD: CP2102.25 (RXD), JP6.1
USB_TXD: CP2102.26 (TXD), JP5.1
VREFA: ANALOG_EXPANDER.3, AVRDB.27 (PD7), R30.1, R31.2
VS1: C1.1, J9.6
VS2: C2.1, J9.5
VS3: C8.1, J9.4
VSENS1: AVRDB.20 (PD0), D6.K (C), R28.1
VSENS2: AVRDB.21 (PD1), D10.K (C), R1.1
VSENS3: AVRDB.22 (PD2), D11.K (C), R2.1
XTALHF1: AVRDB.44 (PA0_(XTALHF1)), C15.1, XTAL.1 (CRYSTAL_1)
XTALHF2: AVRDB.45 (PA1_(XTALHF2)), C17.1, XTAL.3 (CRYSTAL_2)

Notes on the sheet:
Voltage Sensor
OpenEnergyMonitor.org
Trystan Lea & Glyn Hudson - March 2022
Power
CT Current Sensors
Temperature & AC Voltage Sensors
Design is provided "AS IS" and "WITH ALL FAULTS. OpenEnergyMonitor DISCLAIMS ALL OTHER WARRANTIES, EXPRESS OR IMPLIED,
Hardware design files are licensed under the Creative Commons Attribution-ShareAlike 3.0 Unported License
emonTx V4.0.1
RFM69CW
One-Wire RJ45
DIP Switch
LED

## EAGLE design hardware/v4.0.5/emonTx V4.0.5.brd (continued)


Board: 2 copper layers, 99.9 x 64.9 mm, 126 parts (1 on the bottom side), 68 nets.

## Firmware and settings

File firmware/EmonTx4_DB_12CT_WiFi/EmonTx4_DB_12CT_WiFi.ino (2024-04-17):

// EmonTx4_DB_12CT_WiFi 
// This default example prints 1 voltage and 12 power values to the serial port
// this is then either picked up by an EmonESP 8266 WiFi module or can be used
// for direct USB link to a emonBase/emonPi via emonHub.

#define Serial Serial3
#include <Arduino.h>
#include "emonLibDB.h"
#define EMONTX4          // Must be above "#include <RFM69_LPL.h>

#define DATALOG 9.8   

#define EXPANSION_BOARD  // Can be commented out for 6 CT only

const uint8_t LEDpin = PIN_PB2;                   // emonTx V4 LED
uint32_t counter = 0;
void setup() 
{  
  pinMode(LEDpin, OUTPUT);

  Serial.begin(9600);
  Serial.println("Set baud=115200");
  Serial.end();
  Serial.begin(115200);
  
  Serial.println("\nEmonTx4_DB_12CT_WIFI"); 

  
  /****************************************************************************
  *                                                                           *
  * Set the properties of the physical sensors                                *
  *                                                                           *
  ****************************************************************************/
  
  EmonLibDB_set_vInput(1, 100.0, 0.16);  
  
  /* Include the next two lines if you have a 3-phase emonVS */
 
  // EmonLibDB_set_vInput(2, 100.0, 0.16); 
  // EmonLibDB_set_vInput(3, 100.0, 0.16); 
  
  EmonLibDB_set_cInput(1, 20.0, 0.3);         // 0.3° @ 20 A for 100 A CT
  EmonLibDB_set_cInput(2, 20.0, 0.3);
  EmonLibDB_set_cInput(3, 20.0, 0.3);
  EmonLibDB_set_cInput(4, 20.0, 0.3);
  EmonLibDB_set_cInput(5, 20.0, 0.3);
  EmonLibDB_set_cInput(6, 20.0, 0.3);
  
#ifdef EXPANSION_BOARD

  EmonLibDB_set_cInput(7, 20.0, 0.3);
  EmonLibDB_set_cInput(8, 20.0, 0.3);
  EmonLibDB_set_cInput(9, 20.0, 0.3);
  EmonLibDB_set_cInput(10, 20.0, 0.3);
  EmonLibDB_set_cInput(11, 20.0, 0.3);
  EmonLibDB_set_cInput(12, 20.0, 0.3);
  
#endif  

  /****************************************************************************
  *                                                                           *
  * Link voltage and current sensors to define the power                      *
  *  & energy measurements                                                    *
  *                                                                           *
  * For best precision and performance, include only the following lines      *
  *    that apply to current/power inputs being used.                         *
  ****************************************************************************/

/*
  EmonLibDB_set_pInput(1, 1);                  // CT1, V1
*/
  EmonLibDB_set_pInput(1, 1);                  // CT2, V2 (etc)
  EmonLibDB_set_pInput(2, 1);
  EmonLibDB_set_pInput(3, 1);
  EmonLibDB_set_pInput(4, 1);  
  EmonLibDB_set_pInput(5, 1);
  EmonLibDB_set_pInput(6, 1);

#ifdef EXPANSION_BOARD

  EmonLibDB_set_pInput(7, 1);                  // CT7, V1  
  EmonLibDB_set_pInput(8, 1);                  // CT8, V2 (etc)
  EmonLibDB_set_pInput(9, 1);
  EmonLibDB_set_pInput(10, 1);  
  EmonLibDB_set_pInput(11, 1);
  EmonLibDB_set_pInput(12, 1);

#endif

  /* How to measure Line-Line loads: */
/*
  EmonLibDB_set_pInput(3, 1, 2);               // CT1 between V1 & V2    
  EmonLibDB_set_pInput(2, 2, 3);               // CT2 between V2 & V3
  EmonLibDB_set_pInput(3, 3, 1);               // CT2 between V3 & V1  (etc)  
  EmonLibDB_set_pInput(4, 1, 2);  
  EmonLibDB_set_pInput(5, 2, 3);
  EmonLibDB_set_pInput(6, 3, 1);

  EmonLibDB_set_pInput(7, 1, 2);  
  EmonLibDB_set_pInput(8, 2, 3);
  EmonLibDB_set_pInput(9, 3, 1);
  EmonLibDB_set_pInput(10, 1, 2);  
  EmonLibDB_set_pInput(11, 2, 3);
  EmonLibDB_set_pInput(12, 3, 1);
*/

/*
    Pulse counting on any channel is only available if the appropriate solder link is made on the hardware,
      and the related "TMP" link is broken.
*/      
  EmonLibDB_setPulseEnable(true);              // Enable counting on the "Pulse" input
  EmonLibDB_setPulseMinPeriod(20);             // Contact bounce must not last longer than 20 ms
  // EmonLibDB_setPulseEnable(Dig, true);         // Enable counting on the "Pulse" input
  // EmonLibDB_setPulseMinPeriod(Dig, 20);        // Contact bounce must not last longer than 20 ms

  EmonLibDB_datalogPeriod(DATALOG);            // Report every 9.8 s (approx)
  Serial.print("Starting ");
  EmonLibDB_Init();                            // Start continuous monitoring.
  Serial.print("reports every ");
  Serial.print(EmonLibDB_getDatalogPeriod());
  Serial.println(" seconds approx");
  
}

void loop()             
{
  static uint32_t counter = 0;

  if (EmonLibDB_Ready())   
  {
    counter++;
    Serial.print("MSG:"); Serial.print(counter);
    Serial.print(",V1:"); Serial.print(EmonLibDB_getVrms(1));
    
    // Uncomment for further phases as required
    // Serial.print(",V2:"); Serial.print(EmonLibDB_getVrms(2));
    // Serial.print(",V3:"); Serial.print(EmonLibDB_getVrms(3));
    // Serial.print(",FR:"); Serial.print(EmonLibDB_getLineFrequency());
    
#ifndef EXPANSION_BOARD
    for (uint8_t ch=1; ch<=6; ch++)
#else
    for (uint8_t ch=1; ch<=12; ch++)
#endif
    {
      Serial.print(",P"); Serial.print(ch); Serial.print(":"); Serial.print(EmonLibDB_getRealPower(ch)); 

      // Uncomment for energy values
      // Serial.print(",E"); Serial.print(ch); Serial.print(":"); Serial.println(EmonLibDB_getWattHour(ch));
    }
    Serial.println();
    delay(200);
  }
}

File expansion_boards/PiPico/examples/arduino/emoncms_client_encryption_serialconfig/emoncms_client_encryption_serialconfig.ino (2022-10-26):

// Emoncms client with encryption and serial configuration

#include <WiFi.h>
#include <HTTPClient.h>
#include <Crypto.h>
#include <base64.hpp>       // https://github.com/Densaugeo/base64_arduino
#include <EEPROM.h>

// Used for serial configuration
char input[64];
byte idx = 0;

// Config struct
struct {
    char signature[6];
    char ssid[33];
    char pass[33];
    char apikey[33];
} conf;

// Signature used to check EEPROM
const char signature[6] = "ECE01";

#define AES_KEY_LENGTH 16

uint8_t key[AES_KEY_LENGTH];

// This needs to be randomly generated
uint8_t iv[AES_KEY_LENGTH] = { 0x28,0x4E,0x3A,0xBE,0xE3,0x8E,0x88,0x0E,0x2D,0x4F,0x78,0xE3,0xA7,0xB8,0x9D,0x48 };

SHA256 sha256;

char nodestr[] = "node=emontx&data=";
char packet[128];
uint8_t packet_index = 0;

uint8_t data_ready = 0;

bool last_wifi_connected = false;

int LEDpin = LED_BUILTIN;

void bin2hex(char*out, uint8_t* block, int length) {
  for (int i=0; i<length; i++) {
    sprintf(out,"%02x",*block);
    out += 2;
    block++;
  }
}

byte asc2byte(char chr) {
  byte rVal = 0;
  if (isdigit(chr)) {
    rVal = chr - '0';
  } else if (chr >= 'a' && chr <= 'f') {
    rVal = chr + 10 - 'a';
  }
  return rVal;
}

void hex2bin(const char* inP, byte* outP, size_t len) {
  for (; len > 1; len -= 2) {
    byte val = asc2byte(*inP++) << 4;
    *outP++ = val | asc2byte(*inP++);
  }
}

void eepromLoad(byte *dest, byte len) {
  for (byte i=0; i<len; i++) {
    dest[i] = EEPROM.read(i);
  }
}

void eepromSave(byte *dest, byte len) {
  for (byte i=0; i<len; i++) {
    EEPROM.write(i,dest[i]);
  }
  if (EEPROM.commit()) {
    Serial.println("Saved");
  }
}

void printConfig() {
  Serial.print("signature:");
  Serial.println(conf.signature);
  Serial.print("ssid:");
  Serial.println(conf.ssid);
  Serial.print("psk:");
  Serial.println(conf.pass);
  Serial.print("apikey:");
  Serial.println(conf.apikey);
}

bool set_conf(char* input, char *tag, char *conf_var, byte max_len) {
  byte tag_len = strlen(tag);
  if (strncmp(input,tag,tag_len)==0) {
        byte len = idx-tag_len;
        if (len>max_len) len = max_len;
        memset(conf_var, 0, max_len);
        strncpy(conf_var,input+tag_len,len);
        conf_var[len] = '\0';
        return true;
  }
  return false;      
}

void handle_conf(char* ptr) {
  if (set_conf(ptr,"ssid:",conf.ssid,32)) {
    Serial.print("Set:");
    Serial.println(conf.ssid);
  } else if (set_conf(ptr,"psk:",conf.pass,32)) {
    Serial.print("Set:");
    Serial.println(conf.pass); 
  } else if (set_conf(ptr,"apikey:",conf.apikey,32)) {
    Serial.print("Set:");
    Serial.println(conf.apikey);   
  } else if (strncmp(ptr,"save",4)==0) {
    eepromSave((byte *)&conf,sizeof(conf));

    // Only start WiFi if configuration is valid
    if (strlen(conf.ssid)>=4 && strlen(conf.pass)>=4 && strlen(conf.apikey)==32) {
      last_wifi_connected = false;
      Serial.println("Attempting to connect to WiFi");
      // Start WiFi with supplied parameters
      WiFi.begin(conf.ssid, conf.pass);
      // Convert apikey to binary
      hex2bin(conf.apikey, key, strlen(conf.apikey));
    } 
    
  } else if (strncmp(ptr,"load",4)==0) {
    eepromLoad((byte *)&conf,sizeof(conf));
    printConfig();
  }
}

void setup() {
  pinMode(LEDpin,OUTPUT);
  led_state(1);
  
  Serial.begin(115200);
  Serial1.begin(115200);
  delay(2000);
  Serial.println("Pi Pico emoncms client with AES128CBC encryption");
  
  EEPROM.begin(128);

  eepromLoad((byte *)&conf,sizeof(conf));
  if (strncmp(conf.signature,signature,6)!=0) {
    Serial.println("Invalid signature");
    // Reset conf structure
    memset(&conf, 0, sizeof(conf));
    strncpy(conf.signature,signature,6);
  }
  printConfig();
  
  // Operate in WiFi Station mode
  WiFi.mode(WIFI_STA);

  // Only start WiFi if configuration is valid
  if (strlen(conf.ssid)>=4 && strlen(conf.pass)>=4 && strlen(conf.apikey)==32) {
    Serial.println("Attempting to connect to WiFi");  
    // Start WiFi with supplied parameters
    WiFi.begin(conf.ssid, conf.pass);
    // Convert apikey to binary
    hex2bin(conf.apikey, key, strlen(conf.apikey));
  }
  
  // Reset packet to nodestr
  memset(packet, 0, 128);
  strcpy(packet,nodestr);
  packet_index = strlen(nodestr);

  led_state(0);
}

void loop() {
  
  // Serial configuration input
  while (Serial.available()) {
    char c = char(Serial.read());
    if (c=='\n') {
      handle_conf(input);
      memset(input, 0, 64);
      idx = 0;
      led_flash(500);
    } else {
      input[idx] = c;
      idx++;
    }
  }
  
  // Receive data from connected emontx
  while (Serial1.available()) {
    char c = char(Serial1.read());
    if (c=='\n') {
      if (strncmp(packet+strlen(nodestr),"MSG:",3)==0) {
        Serial.println(packet);
        data_ready = 1;
        led_flash(50);
      } else {
        handle_conf(packet+strlen(nodestr));
        memset(packet, 0, 128);
        strcpy(packet,nodestr);
        packet_index = strlen(nodestr);
        led_flash(500);
      }
    } else {
      packet[packet_index] = c;
      packet_index++;
    }
  }

  // Print WiFi connection status
  if (!last_wifi_connected) {
    if(WiFi.status()== WL_CONNECTED) {
      last_wifi_connected = true;
      
      // Connection established
      Serial.print("Connected to WiFi network ");
      Serial.println(WiFi.SSID());

      // Print IP Address
      Serial.print("Assigned IP Address: ");
      Serial.println(WiFi.localIP());

      // Test packet
      Serial.println("Sending test packet");
      memset(packet, 0, 128);
      strcpy(packet,nodestr);
      packet_index = strlen(nodestr);
      strcpy(packet+packet_index,"start:123");
      data_ready = 1;
      led_flash(50);
    } else {
      led_flash(20);
      delay(100);
    }
  }
  
  // Send data if data is ready
  if (data_ready) {
    data_ready = 0;
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

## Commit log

2022-05-09 emontx4 v4.0.2-beta
    [emonTx V4.0.1.brd, emonTx V4.0.1.sch, emonTx V4.0.2-beta.brd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]
2022-06-15 minor fascia revisions
    [#V0.2-fascia-emontxv4.dxf, V0.1-fascia-emontxv4.brd, V0.2-fascia-emontxv4.brd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]
2022-06-28 add gerbers
    [emonTx V4.0.4.brd, emontx4-fascia-v0.1.dxf]
2022-07-06 update fascia
    [#V0.2-fascia-emontxv4.dxf, V0.1-fascia-emontxv4.brd, V0.2-fascia-emontxv4.brd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]
2022-10-05 fix online configuration, update default CT calibration
2022-10-05 v4.0.5 routes 5V to uart connector
    [emonTx V4.0.5.brd, emonTx V4.0.5.sch]
2022-10-05 extension board hardware files
    [emonTx4-CTExt.brd, emonTx4-CTExt.sch, emonTx4-ESP32.brd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]
2022-10-05 basic esp32 arduino examples
2022-10-20 pi pico emoncms client example with AES128CBC encryption
2022-10-20 esp32 emoncms client example with AES128CBC encryption
2022-10-23 updated pi pico extension design
    [emonTx4-PiPico.brd, emonTx4-PiPico.sch]
2022-10-24 return assumed vrms if no voltage sensor
2022-10-26 change ct calibration, led stays on until msg 0
2022-10-26 minor serial print typo, remove factory RF test
2022-10-26 ESP8266 huzzah adapter board
    [emonTx4-ESP8266.brd, emonTx4-ESP8266.sch]
2022-10-26 ESP32 client with encryption and serialconfig
2022-10-26 pi pico LED feedback
2022-11-15 Create single EmonTxV4 Firmware with option to switch between radio formats
2022-11-21 calibrate reference voltage at startup
2022-11-25 start on expansion board documentation and rename extension to expansion board
    [emonTx4-CTExt.brd, emonTx4-CTExt.sch, emonTx4-ESP32.brd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]
2022-11-25 page on voltage sensors
2022-11-26 acacconverter picture, voltage sensor page improvements
2022-11-29 firmware 1.5.3, sightly slower sample rate, temperature sensors disabled if not detected at startup
2022-11-29 a couple more decimal places
2022-12-02 updated ESP8266 adapter board
    [emonTx4-ESP8266.brd, emonTx4-ESP8266.sch]
2022-12-03 start on temperature, pulse and analog page, accuracy and tech spec in overview
2022-12-03 more detail on temperature sensing
2022-12-26 emontx4 heat pump monitor firmware example
2022-12-26 heat pump monitor documentation first draft
2022-12-26 voltage sensing technical
2023-03-09 V1.2 fascia
    [V1.1-fascia-emontxv4-2mm-clear-acrylic.dxf, V1.1-fascia-emontxv4.brd, V1.2-fascia-emontxv4.brd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]
2023-04-19 6x DS18B20 temperature sensor example
2023-04-25 update 6x temperature sensor example
2023-04-26 Fix disabling of temperature sensing at startup if none detected
2023-04-26 v1.5.7: Fix disabling of temperature sensing at startup if none detected
2023-04-26 only attempt to print temperature sensor address and check for sensors if enabled
2023-04-26 update emontx4 heatpump firmware example
2023-05-15 12 CT fascia
    [V1.2-fascia-emontxv4_12CT.brd]
2023-06-07 emonTx4 v4.0.5 BOM
    [BOM.ods]
2023-07-03 expansion board documentation
2023-07-31 Add "3PH" to three-phase serial print statup
2024-02-23 serial print 6x temp to identify
2024-05-15 update temperature section
2024-05-15 update heatpump monitor docs
2024-05-15 update expansion boards page
2024-05-15 updated 6ct expansion board page
2024-05-26 3-phase 4-wire and n,american systems
2025-10-13 overview.md: emonTx5 is definitely released now
    Reorganized text for clarity and improved flow.

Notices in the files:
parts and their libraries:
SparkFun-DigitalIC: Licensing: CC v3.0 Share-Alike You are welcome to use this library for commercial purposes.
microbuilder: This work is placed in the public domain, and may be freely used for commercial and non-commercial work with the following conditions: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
